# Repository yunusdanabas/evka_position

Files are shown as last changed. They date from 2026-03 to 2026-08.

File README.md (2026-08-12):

# Evka Position: Spherical 3D Positioning Prototype

> Turkce operator guide: [README_TR.md](README_TR.md)

Evka Position is an existing-repository prototype that derives a 3D point from two rotary
encoders and one draw-wire encoder:

```text
encoder counts -> (radius, theta, phi) -> sensor-frame (X, Y, Z) mm
```

Start with [HANDOFF.md](HANDOFF.md), use [docs/ONBOARDING.md](docs/ONBOARDING.md) for the
self-contained setup and safety baseline, and browse [docs/README.md](docs/README.md) for the
documentation status index.

## Handoff Status

| Area | Approved statement |
|---|---|
| Current hardware | The assembled ESP32-S3 v4 carrier is the current prototype. It is not a production-qualified product. |
| Firmware | Shared classic/v4 firmware and all PlatformIO environments build successfully. No new flash or hardware validation is claimed. |
| Telemetry | Live 20 Hz telemetry has been observed in earlier work. Full end-to-end hardware acceptance remains open. |
| Repeatability | Theta count loss is unresolved. The recorded return error reached about 1.1 degrees, approximately 35 mm at 2 m. |
| Coordinates | Firmware and `tools/evka_gui` report the sensor frame. No endpoint/world transform has been accepted. |
| Host application | `tools/evka_gui` is the canonical operator GUI. The vendor C# application has been deleted; the TCP compatibility protocol remains supported. |
| Legal/release | The repository has no redistribution license and makes no public production-readiness claim. |

Do not hide theta slip, backlash, or lost counts by changing PPR or fitting a world transform.
Resolve repeatability first, then calibrate scale, fit a candidate transform, and validate it on
hold-out points.

Known repeatability record:
[docs/calibration/sessions/2026-07-17_repeatability.md](docs/calibration/sessions/2026-07-17_repeatability.md).

### Software Verification Record

| Check | Result |
|---|---|
| `QT_QPA_PLATFORM=offscreen pytest -q -m qt_heavy --forked` | PASS: 44 tests |
| `QT_QPA_PLATFORM=offscreen pytest -q -m "not qt_heavy"` | PASS: 160 tests, 11 subtests (204 total with the above) |
| Dashboard harness (`npm ci && npm test`) | PASS: 50 checks |
| `python -m compileall tools -q` | PASS |
| `python -m tools.ipt.solver` | PASS: 0.405 mm target error |
| PlatformIO build matrix | PASS: all 10 configured environments |

The Python suite runs as **two invocations on purpose**. Modules marked `qt_heavy` build
pyqtgraph widgets that segfault when they share a process, so they run forked; forking only
works if the parent has not built a QApplication first, which is why they get their own
invocation. A plain `pytest -q` is still expected to segfault intermittently — use the two
commands above. Background: [docs/CI_PYTEST_SEGFAULT_LOG.md](docs/CI_PYTEST_SEGFAULT_LOG.md).

These are software-only results. Hardware acceptance remains governed by the open
gates in [docs/integration/final_integration_validation.md](docs/integration/final_integration_validation.md).

## Hardware Baseline

- MCU: ESP32-S3-DevKitC-1 on the v4 carrier; classic Wemos D1 R32 remains a compatibility target.
- Theta/Phi: Autonics E40S6-5000, 20,000 counts/rev at X4 quadrature.
- Radius: OPKON DWEM2 P2000, theoretical 8,000 counts/rev at X4 quadrature.
- Main firmware encoder driver: `madhephaestus/ESP32Encoder` using ESP32 PCNT.
- Encoder outputs are 5 V; the v4 carrier includes the signal dividers required by the ESP32.

### v4 Connector Map

| Connector | Axis | PCB pin order | GPIO |
|---|---|---|---|
| J1 | Draw-wire | `1=A, 2=GND, 3=B, 4=+5V` | A=7, B=8 |
| J2 | Phi | `1=+5V, 2=A, 3=GND, 4=B` | A=4, B=5 |
| J3 | Theta | `1=A, 2=GND, 3=B, 4=+5V` | A=9, B=10 |

Cable colors:

| Encoder | A | B | +5V | GND |
|---|---|---|---|---|
| E40S6 theta/phi | Black | White | Brown | Blue |
| DWEM2 draw-wire | Yellow | Green | Brown | White |

This connector order is derived from the v4 KiCad PCB/pad nets and the current firmware pin map.
It was **not physically reverified during this final documentation pass**. Verify the actual board
and cable before applying power.

Compile-time pins, calibration defaults, battery behavior, LED selection, and network constants
are defined in `firmware/src/SphericalSensor.h`. Runtime PPR values may be overridden by NVS, so
query `CONSTANTS` before a calibration session.

## Canonical Operator GUI

The host-tools package is version `0.2.1` and requires Python 3.10 or newer.

Install the Python dependencies from the repository root:

```bash
python3 -m venv .venv
source .venv/bin/activate
pip install -r requirements.txt
```

Run the canonical GUI:

```bash
python -m tools.evka_gui
python -m tools.evka_gui --serial /dev/ttyACM0 --baud 115200
python -m tools.evka_gui --tcp 192.168.1.50:8080
python -m tools.evka_gui --ws 192.168.1.50
python -m tools.evka_gui --replay frames.csv
```

`evka_gui` supports Serial, TCP, WebSocket, and replay; includes Quick IPT, diagnostics,
recording, snapshots, and the calibration-report workflow; and records raw sensor-frame data.
Software zero is a display/session offset only. The GUI does not apply an endpoint/world transform
to live telemetry, so its XYZ and IPT results remain in the sensor frame.

The standalone `tools/position_checker` entry points are legacy compatibility tools.

## Firmware Build and Flash

PlatformIO is the supported firmware toolchain. Build without uploading:

```bash
pio run -e esp32s3_v4
pio run -e wemos_d1_r32
pio run -e button_remote
```

Flash after wiring and safety review. Replace `/dev/ttyACM0` with the correct port
(`/dev/ttyUSB0` on some boards, `COMx` on Windows). Do not open the same port in two apps at once.

**Main device** (ESP32-S3 v4 carrier — current prototype):

```bash
pio run -e esp32s3_v4 --target upload --upload-port /dev/ttyACM0
pio device monitor -e esp32s3_v4
```

Classic Wemos compatibility target (not for the v4 carrier):

```bash
pio run -e wemos_d1_r32 --target upload --upload-port /dev/ttyUSB0
```

**Remote control** (ESP32-C3 pendant, ESP-NOW):

```bash
pio run -e button_remote --target upload --upload-port /dev/ttyACM0
pio device monitor -e button_remote
```

Bench-only pendant test firmware (own AP `REMOTE_TEST`, no ESP-NOW — see
[`tools/remote_tester/README.md`](tools/remote_tester/README.md)):

```bash
pio run -e button_remote_test --target upload --upload-port /dev/ttyACM0
```

The `test_*` environments use the classic Wemos pin map and must not be flashed onto the v4
carrier. See [CONTRIBUTING.md](CONTRIBUTING.md) and
[pcb_design/EVKA_position_v4/FIRMWARE.md](pcb_design/EVKA_position_v4/FIRMWARE.md) before any
flash or bring-up work.

## Protocol and Networking

The canonical, source-derived transport and command reference is
**[docs/PROTOCOL.md](docs/PROTOCOL.md)**. In summary:

- Serial: 115200 baud; machine-readable `DATA,...` at 20 Hz.
- WebSocket: `ws://<device>/ws`; `DATA,...` at 20 Hz.
- TCP: port 8080; separate `X...,Y...,Z...` and `SENSOR,...` lines at 20 Hz.
- `RAW_COUNTS` returns zero-relative counts, not absolute PCNT values.

The firmware's existing credentials and addresses are unchanged:

| Setting | Current value |
|---|---|
| AP SSID | `CMDCNC_EVKA` |
| AP password | `cmdcnc1234` |
| AP dashboard | `http://192.168.1.50` |
| TCP | `192.168.1.50:8080` |
| WebSocket | `ws://192.168.1.50/ws` |
| STA static profile | `192.168.1.84/24`, gateway `192.168.1.254` |
| STA default network | `WIFI_STA_DEFAULT_SSID` / `_PASS` in [firmware/src/SphericalSensor.h](firmware/src/SphericalSensor.h) — a specific shop-floor network; change before deploying elsewhere |

These fixed credentials and unauthenticated command channels are suitable only for an isolated,
trusted lab network. Do not expose the AP, TCP port, or WebSocket to an untrusted LAN or the public
internet. `WIFI_SET` changes stored STA credentials and reboots the device.

## Calibration Boundary

The active workflow is documented under [docs/calibration/](docs/calibration/). No shared/default
calibration JSON is checked in and no endpoint/world transform is accepted. After the repeatability,
calibration, and hold-out gates pass, a session JSON may be supplied explicitly to the legacy
visualizer with `--legacy-visualizer --calibration <session-calibration.json>`. The canonical
`tools/evka_gui` remains sensor-frame-only.

## Repository Areas

- Active: `firmware/src/`, `tools/evka_gui/`, `docs/PROTOCOL.md`, active calibration and v4 docs.
- Archive/reference: classic test material, integration history, GUI migration logs, and
  `docs/hardware_design/12v_legacy/`.
- Research: `laser_radius/` and `docs/research/`; these are studies, not implemented baseline.
- Unindexed: `report/` holds a standalone LaTeX report that nothing else references. It is kept
  for the record and is not part of the documentation status index.

Prebuilt operator GUI bundles (Windows `.exe` and portable source) are published as assets on the
[v0.2.1 release](https://github.com/yunusdanabas/evka_position/releases/tag/v0.2.1), not in git.
Rebuild them with the scripts in `packaging/evka_gui/`.

## License and Redistribution

There is no repository license file. Default copyright restrictions apply. Do not redistribute,
publish a product release, or represent this prototype as production-ready until ownership and
licensing are explicitly resolved. Historical vendor C# material has been deleted; that cleanup does
not affect the retained TCP wire protocol.

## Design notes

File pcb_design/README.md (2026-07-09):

# pcb_design — KiCad workspaces

Four board revisions live side by side. **Only v4 is fabricated and current** —
the rest are kept for reference.

| Workspace | Status | Notes |
|---|---|---|
| `EVKA_position_v4/` | **CURRENT — fabricated** | ESP32-S3-DevKitC-1 carrier; firmware env `esp32s3_v4` (`-DPCB_V4`). Pin map, bring-up, battery, LED: [`EVKA_position_v4/FIRMWARE.md`](EVKA_position_v4/FIRMWARE.md) |
| `EvkaPosition_v2/` | Superseded | Full-featured 5V design (74HC14 buffers, load-sharing). ERC-clean but never fabricated. Its design docs were removed on migration to v4 — recover from git history if needed |
| `EVKA_position_v3/` | Superseded | Stripped "simple" variant of v2 (direct-GPIO dividers, no buffers). Never fabricated |
| `EVKA_position_v5/` | Experimental / WIP | Layout exploration after v4; not fabricated, no firmware support |

Netlists are generated files — regenerate with
`kicad-cli sch export netlist <project>.kicad_sch` (a stray root-level
`EvkaPosition_v2.net` is git-ignored for this reason). KiCad backup folders
(`*-backups/`) are git-ignored too.

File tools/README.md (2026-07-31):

# Host Tools

The supported operator path is `tools/evka_gui`. Host tools are package version `0.2.1` and require
Python 3.10+. All current GUI telemetry, recordings, snapshots, and Quick IPT results are sensor-frame
values. No endpoint/world transform is accepted or applied by the canonical GUI.

## evka_gui: Canonical Operator GUI

```bash
python -m tools.evka_gui
python -m tools.evka_gui --serial /dev/ttyACM0 --baud 115200
python -m tools.evka_gui --tcp 192.168.1.50:8080
python -m tools.evka_gui --ws 192.168.1.50
python -m tools.evka_gui --replay frames.csv
```

It provides Serial/TCP/WebSocket/replay connections, 3D and 2D views, recording, snapshots,
saved-point events, diagnostics, zero-relative raw counts, Quick IPT, and calibration-session tools.

Coordinate rules:

- Software Zero is a display/session offset only.
- Hardware Zero sends a firmware `ZERO*` command.
- Recordings and calibration capture use raw sensor-frame telemetry, not software-zeroed display
  values.
- The calibration window can generate a candidate session JSON after report PASS, but that does not
  establish project acceptance or change the live GUI frame.

Full guide: [evka_gui/README.md](evka_gui/README.md).

## calibration

Candidate Kabsch sensor-to-world fitting with separate calibration and hold-out sets:

```bash
python -m tools.calibration.gui
python -m tools.calibration.report
```

Theta repeatability must pass before collecting endpoint pairs. No shared/default calibration JSON
is checked in or accepted.

Operator workflow: [../docs/calibration/report_workflow.md](../docs/calibration/report_workflow.md).
Tool details: [calibration/README.md](calibration/README.md).

## Quick IPT

Quick IPT is inline in `evka_gui`. A standalone UI remains available:

```bash
python -m tools.ipt --tcp 192.168.1.50:8080
python -m tools.ipt --serial /dev/ttyACM0 --baud 115200
python -m tools.ipt.solver
```

The recovered point is in the sensor frame. See [ipt/README.md](ipt/README.md).

## Remote Tester

Development-only direct TCP/serial tester for `button_remote_test` firmware:

```bash
python tools/remote_tester/remote_test_gui.py
```

It is also available from the canonical GUI's **Remote Tester...** action, using a separate test
connection. See [remote_tester/README.md](remote_tester/README.md).

## Legacy position_checker

`tools/position_checker` retains shared parsing/transport/view code and legacy standalone entry
points. New operator instructions should use `tools/evka_gui`.

A passing session JSON may be supplied explicitly only to the legacy visualizer:

```bash
python -m tools.position_checker.main --legacy-visualizer --port /dev/ttyUSB0 \
  --calibration docs/calibration/sessions/current/calibration.json
```

| Legacy command | Canonical replacement |
|---|---|
| `python -m tools.position_checker.main --legacy-visualizer --port ...` | `python -m tools.evka_gui --serial ...` |
| `python -m tools.position_checker.cmd_main` | `python -m tools.evka_gui --tcp ...` |

Historical migration documents may mention older GUI package names as archive history.

## Protocol and Security

[../docs/PROTOCOL.md](../docs/PROTOCOL.md) is the canonical protocol reference. Do not treat
`cmd_main.py`, a GUI parser, or a historical vendor application as the wire-contract source.

Current fixed credentials and unauthenticated state-changing commands are trusted-lab-only. Do not
expose the device's TCP/WebSocket services to an untrusted network.

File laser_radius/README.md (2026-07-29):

# Laser Radius Research — Spherical Positioning Variant

**Location:** `laser_radius/` at repo root — all detailed research deliverables live here.

**Scope:** Detailed research for an EVKA positioning variant that replaces the draw-wire radius encoder with a laser distance measurement, while keeping two rotary encoders for azimuth (θ) and elevation (φ).  
**Status:** Detailed study, revised to a fixed requirement (2026-07-01) — device shortlists, kinematics/calibration, firmware sketch, procurement plan, and a LaTeX summary report are documented below and in the linked files. Physical bench testing has not started.  
**Current prototype baseline:** ESP32-S3 v4 carrier + 2× E40S6 rotary encoders + OPKON DWEM2 draw-wire.
**Target platform (this variant):** ESP32-S3-DevKitC-1 on EVKA_position_v2 carrier direction.

---

## Executive Summary

**Fixed requirement:** laser range ≤ 40 m, laser device accuracy ≤ 10 mm (target sub-cm) across that full range. This is the laser sensor's own datasheet spec, not the total combined-system XYZ accuracy — see [`kinematics_and_calibration.md`](kinematics_and_calibration.md) §4 for why the rotary encoders separately add error that this spec doesn't cover.

**This single number is a real physics dividing line, and it reshaped the shortlist from an earlier draft of this study:** cheap pulsed time-of-flight LIDAR modules (the entire Benewake TF-series, DFRobot SEN0492) measure round-trip pulse timing directly and only achieve ±5cm–±1%-of-reading accuracy — they **fail this spec** and are excluded as recommendations (kept only as documented "does not meet spec" reference entries in `version_b_integrated_modules.md` §1). Phase-shift (AMCW) laser distance meters — the Leica handheld class, and industrial OEM modules like Meskernel and Dimetix — measure phase difference of a modulated beam and achieve flat, distance-independent mm-class accuracy across their full rated range. Every **certified** device below is confirmed phase-shift; two popular families (**Bosch** handhelds and the **JRT** OEM modules) are **flagged** rather than certified — the stricter 2026-07-08 survey could not confirm their measurement principle is phase-shift from any primary source, so they are held out of the recommended pass list until that is verified (they are *not* excluded — they are not ToF or %-of-reading; see `version_a_handheld_devices.md` §2.3).

**Recommendation (confirmed-phase-shift-first, revised 2026-07-09):** lead the bench path with a device whose phase-shift principle *and* price are both confirmed. Cheapest such path is the **Meskernel LDL-T** — both 2026-07-08 surveys confirm it as phase-shift; ±1 mm, 100 Hz, UART TTL/RS232/RS485; confirmed street price ~$87.50 (~4,097 TRY) for the 80 m LDL-T-80, ~$68–80 for the 40 m LDL-T 40. For the lowest *integration* risk, the **Dimetix D-series** is the only candidate with a fully public ASCII command set — the newly-confirmed **DBN-50-050** (±5 mm, still under the ≤10 mm bar) at CHF 1,076 / ~$1,332 is the budget entry, the **DAE-10-050** (±1 mm) at ~$2,700 the precise one. For a confirmed, domestically-stocked handheld, the **Leica DISTO D5** (±1 mm, 200 m, BLE) is now confirmed available in Turkey. **Bosch PLR 40 C: Bluetooth type now confirmed (BLE 4.2 GATT, 2026-07-09)** — ESP32-S3 compatible, protocol decrypted from GLM family (CRC-8, IEEE 754 float parsing), but byte-level traces are from GLM 50C/120C — **one real-device capture session on PLR 40 C still required** before firmware work. Measurement principle (phase-shift vs other) still unconfirmed. **Do not use PLR 40 C for production** — BLE latency jitter, no USB/wired fallback, 5-minute auto-power-off, and power supply fragility make it unsuitable for continuous automated tracking. Use wired industrial sensors (Meskernel/Dimetix) instead. **Flagged — do not certify yet:** the **Bosch GLM 50-27 CG** and **JRT B605B / M88B** are attractive on price and (for Bosch) domestic availability, but the stricter survey could not confirm their measurement principle from any primary source — treat them as promising-but-unverified and confirm the principle before committing. Reach for an industrial module (Micro-Epsilon ILR2250/3800, WayCon LDI, FAE LS 121/122 FA) only if IP-rated/certified housing becomes a hard requirement — a large cost premium for accuracy margin the Meskernel/Dimetix path already clears. Full reasoning: [`version_a_handheld_devices.md`](version_a_handheld_devices.md), [`version_b_integrated_modules.md`](version_b_integrated_modules.md), and the bench-test order in [`procurement_and_bom.md`](procurement_and_bom.md).

**2026-07-01 addendum — extended shortlist:** a second research pass (assisted by a Copilot CLI research agent) more than tripled the candidate count — 8 more handheld/BLE devices (Hilti PD-I, Leica DISTO D2/S910, Bosch GLM 50-27CG/165-27CG, Stanley TLM165i, RS PRO/CEM iLDM-150H, ADA Cosmo 60 Green) and 5 more industrial fixed-mount devices (Micro-Epsilon optoNCDT ILR1181-3/ILR2250/ILR3800, Jenoptik LDM4x, WayCon LDI, Scantron SLS), all confirmed phase-shift and meeting the ≤10mm/≤40m spec. Two standouts worth knowing about even in this summary: **RS PRO ILDM-150H** (~$90–130) is the cheapest BLE handheld found, potentially unseating Bosch on price with comparable local availability via RS Components' Turkey branch; **Leica DISTO S910** (~$900–1,200) is the single best-specified handheld (±1.0 mm, 300 m range, *native* wired USB — no accessory cable needed), priced near the industrial tier. The research also produced a documented "don't re-check these" list of 15+ rejected devices/manufacturers (wrong tech, wrong range, or no data interface) — see §3.1/§3.2 in the two device files.

**2026-07-08 addendum — confirmed pricing & SKU survey:** a targeted Istanbul price/model survey (two independent passes) replaced most of the earlier *estimates* with **CONFIRMED** prices and exact SKUs, and it changed two recommendations:
- **Confirmed prices/SKUs:** Dimetix **DAE-10-050** (P/N 500633, ±1 mm, ~$2,700) and **DBN-50-050** (P/N 500635, ±5 mm, ~$1,332 — cheapest qualifying Dimetix); Leica **DISTO D5** (confirmed in TR), **S910** (~$1,916–2,132 — **corrected up** from the earlier ~$900–1,200 estimate), and D2 (current refresh SKU 986858 = 150 m); Bosch **GLM 50-27 CG** (8,200 TRY / ~$175); Meskernel **LDL-T-80** (~$87.50, and its rate corrected **30 → 100 Hz**).
- **New models added:** Leica **DISTO X6** (250 m, ±1 mm — the practical rugged X4 successor alongside the D5), Dimetix **DBN-50-050**, Meskernel **LDK-40**, JRT **M88B**, and **FAE LS 121/122 FA** (50 m, ±3 mm industrial). New price *anchors* (still ESTIMATE) for the previously quote-only Micro-Epsilon **ILR2250** (~$1,800) and Jenoptik **LDM41** (~$1,500).
- **Corrections:** Bosch and JRT **demoted to a flagged (uncertified) tier** — see the physics note above. Micro-Epsilon's older **ILR1171/1181/1191** family is **pulsed ToF** (rejected); ILR2250/ILR3800 remain the confirmed phase-comparison picks. Jenoptik LDM4x's 150 m headline is reflector-dependent (~30 m on natural surfaces) — flagged.
- **New figures:** `report/figures/price_vs_accuracy.png` (same ±1 mm accuracy spans ~$43→$2,772) and `turkey_availability.png` (lead-time by sourcing class), generated by `report/figures/make_figures.py`. FX used: USD/TRY 46.85, CHF/USD 1.238, EUR/USD 1.141, GBP/USD 1.336 (2026-07-08).

**A brief LaTeX report summarizing this whole study is in [`report/`](report/report.pdf).**

**A key finding that affects both versions:** the RS-485 GPIO plan cited below (§1.4) comes from the older `12v_legacy/v2` pin map. The current as-built 5V v2 board wires those same pins differently (no dedicated RS-485/RS422 header exists yet) — see [`version_b_integrated_modules.md`](version_b_integrated_modules.md) §4 for the corrected wiring and the new-hardware implications.

---

## 1. Overview and Concept

### 1.1 Relation to Current System

The existing system computes 3D position from spherical coordinates `(r, θ, φ)` and converts to Cartesian `(X, Y, Z)` using the same elevation-azimuth convention documented in [`docs/hardware_design/system_architecture.md`](../docs/hardware_design/system_architecture.md) and implemented in `firmware/src/SphericalSensor.cpp`.

In this variant, **only the radius source changes**: instead of quadrature counts from a draw-wire drum, `r` comes from a laser distance measurement on the phi (elevation) head. The two rotary encoders remain unchanged in role.

### 1.2 Kinematic Chain

Current draw-wire chain:

`Base → Theta → Arm → Phi → Draw-Wire → Target`

Proposed laser chain:

`Base → Theta → Arm → Phi → Laser (on phi head) → Target`

The laser is mounted on the phi head and points at the target along the boom, replacing the draw-wire cable path.

```mermaid
graph TD
    Base[FixedBase] -->|Z_axis| ThetaMotor[Motor1_Theta]
    ThetaMotor --> Arm[HorizontalArm]
    Arm -->|X_axis| PhiMotor[Motor2_Phi]
    PhiMotor --> LaserHead[LaserOnPhiHead]
    LaserHead -->|"r via laser"| Target[TargetObject]
    Target --> XYZ["X Y Z computed"]
```

### 1.3 Why Laser Instead of Draw-Wire

| Factor | Draw-wire (current) | Laser (proposed) |
|---|---|---|
| Mechanical coupling | Cable sag, wrap, drum wear | Line-of-sight only |
| Calibration | `CAL_W`, drum circumference, PPR | Device offset, reflectivity |
| BOM / wiring | 3rd quadrature encoder (2 lines) | Serial or RS232/RS422/RS485 interface |
| Dual use | Fixed to machine | Version A: detachable handheld possible |
| Accuracy at 40 m | Good linear step (~0.025 mm/count), but ≤3 m practical reach | ±1–2.6 mm class (phase-shift devices) at full 40 m range |

### 1.4 ESP32-S3 Pin Baseline

Align with V2 pin assignment ([`pin_assignment_v2.md`](../docs/hardware_design/12v_legacy/v2/pin_assignment_v2.md)):

| Function | GPIO | Notes |
|---|---|---|
| Theta A/B | 4, 5 | Unchanged |
| Phi A/B | 6, 7 | Unchanged |
| Wire A/B/Z | 15, 16, 17 | **Freed** — no draw-wire in this variant |
| RS-485/RS422 TX/RX/DE | 13, 14, 18 | Version B fixed laser; optional for Version A wired serial. **Superseded** — the current as-built 5V v2 board wires 13/14 as general AUX pins and 18 as BTN2; see [`version_b_integrated_modules.md`](version_b_integrated_modules.md) §4 for the corrected 13/14/15 wiring. |
| Battery ADC | 1 | Optional, if carrier retains 12V monitor |

### 1.5 Accuracy Baseline (Current vs. Fixed Requirement)

Current draw-wire system (from system architecture, at ~5 m, ≤3 m practical reach):

| Axis | Source | Typical error contribution |
|---|---|---|
| θ, φ | E40S6 @ 20000 PPR | ~1.57 mm arc at 5 m (grows linearly with range — ~12.6 mm at 40 m) |
| r | Draw-wire | ±0.025 mm per count step |
| Combined XYZ | — | ~±3.2 mm worst case at 5 m |

**Laser variant fixed requirement:** ≤ 40 m range, ≤ 10 mm laser device accuracy (device spec, confirmed as the target — see Executive Summary). Every shortlisted device meets this with 4–10× margin (§2/§3 below and the linked files) — the harder number to watch is the *combined* system accuracy at long range, which the encoders alone push to ~18 mm at 40 m regardless of laser choice (see `kinematics_and_calibration.md` §4); that's out of scope for this laser-selection study per the user's decision but worth keeping in mind.

### 1.6 Related Work in This Repo

[`docs/research/improvement_research.md`](../docs/research/improvement_research.md) mentions a VL53L1X ToF sensor for cross-validation against the draw-wire — that is a short-range sanity check, not a full radius replacement. This folder covers a dedicated laser-radius architecture with two sub-versions below.

---

## 2. Version A — Detachable Handheld / Wired-Serial Laser

Mounted on the phi head during operation, quick-disconnect so the same tool can be used standalone in the field. **Full shortlist, per-device specs, protocol notes, and pricing: [`version_a_handheld_devices.md`](version_a_handheld_devices.md).**

Top candidates against the ≤40m/≤10mm spec: **Meskernel LDL-T** (confirmed phase-shift, ±1mm to 80m, RS232/RS485/USART, native **100 Hz**, ~$68–87.50), **Leica DISTO D5/S910** (±1mm to 200–300m, BLE + native USB on S910, confirmed TR pricing), and — *flagged, phase-shift unconfirmed by the stricter survey* — **JRT B605B/M88B** (≈±2.6mm @ 40m, RS232 TTL, cheapest wired option) and **Bosch PLR 40 C** (±2mm flat to 40m, BLE-only, best local availability). Extended research added Hilti PD-I, Leica DISTO D2/X6/S910, Bosch GLM 50-27CG/165-27CG, Stanley TLM165i, RS PRO/CEM iLDM-150H, ADA Cosmo 60 Green — 13 qualifying/flagged devices total. **UNI-T LM50A (and Makita LD050P, found in the addendum) remain unsuitable** regardless of the spec change — neither has any automated data interface at all (no Bluetooth/USB/RS232), which is an integration problem, not an accuracy one.

---

## 3. Version B — Built-In Fixed Laser Module

Permanently mounted on the phi head — no operator handling. **Full shortlist, wiring, and the as-built GPIO correction: [`version_b_integrated_modules.md`](version_b_integrated_modules.md).**

The previously-considered primary pick (Benewake TF02-i-RS485, and its TF03/TFmini/SEN0492 alternatives) **fails the ≤10mm spec** — pulsed-ToF modules land at ±5cm–±1% of reading, 5–40× over budget — and is now excluded, kept only as a documented reference for why. The primary path is a **Dimetix D-series** industrial phase-shift sensor — now pinned to confirmed SKUs: **DAE-10-050** (±1mm, ~$2,700) or the cheaper **DBN-50-050** (±5mm, still ≤10mm, ~$1,332), both with a fully public ASCII command set (lowest integration risk of any candidate). Far cheaper: panel-mount the **Meskernel LDL-T** bare module (confirmed phase-shift, ±1mm, 100 Hz) as a fixed installation instead of a handheld dock — the **JRT B605B** works the same way but is flagged (phase-shift unconfirmed). Extended research added industrial-tier alternatives to Dimetix (Micro-Epsilon optoNCDT ILR2250/ILR3800 ~$1,800, Jenoptik LDM41 ~$1,500, FAE LS 121/122 FA ~$1,400, WayCon LDI quote-only, Scantron SLS — all ±1-3mm class) plus a sweep of 13 manufacturers (SICK, Banner, Wenglor, Balluff, Contrinex, Riftek, and others) that turned out to sell the wrong technology (pulsed ToF or short-range triangulation) — documented as a "don't re-research" list. Note: Micro-Epsilon's older ILR1171/1181/1191 line is pulsed ToF (2026-07-08 correction) and now rejected — use the phase-comparison ILR2250/ILR3800 instead.

---

## 4. Open Questions

1. ~~Range and accuracy requirements~~ — **resolved**: ≤40 m, ≤10 mm laser device accuracy (2026-07-01).
2. **Spherical origin offset** — distance from laser aperture to mechanical pivot; correction term in `r` before `sphericalToCartesian()`. See `kinematics_and_calibration.md` §1.
3. **Target reflectivity** — dark, glossy, or angled surfaces; need for retroreflector plate or laser filter window on phi head. See `kinematics_and_calibration.md` §2.
4. **Exact pricing for most candidates** (JRT B605B, Meskernel LDL-T, Leica's current D-line, and all 4 addendum industrial modules) — unconfirmed, need direct quotes. See `procurement_and_bom.md` Open Risks.
5. **Update rate** — resolved for the recommended devices (JRT ~8Hz needs hold-last-value gap-filling; Meskernel/Bosch/Dimetix don't). See `firmware_integration.md` §2.
6. **Firmware architecture** — new `LaserRadiusSensor` class vs extending `SphericalSensor.h`; removal of wire encoder and `CAL_W` / `PPR_WIRE` paths. Sketch in `firmware_integration.md` §4.
7. **Calibration workflow** — replace draw-wire `CAL_W` with laser zero offset and optional scale check. Proposed in `kinematics_and_calibration.md` §3.
8. **Safety and enclosure** — Class 1 vs Class 2 exposure; interlocks if operator can remove dock (Version A).
9. **CMD / WiFi dashboard** — expose radius source type in `STATUS` / WebSocket JSON; update calibration UI tab.
10. **Dimetix's exact current-catalog SKU** for a confirmed 40 m RS232/RS422 unit — see `version_b_integrated_modules.md` Open Risk #1.

---

## 5. Next Steps

1. Order a **Meskernel LDL-T** (confirmed phase-shift, cheapest such option) and a **Dimetix DBN-50-050** (confirmed public ASCII protocol, lowest integration risk) as the two confirmed-phase-shift leads — see `procurement_and_bom.md` §2 for the full bench-test order.
2. Bench-test the confirmed lead at 5 m / 20 m / 40 m against a known reference to confirm its datasheet accuracy holds in practice.
3. Measure spherical origin offset (`d_offset_mm`) on a physical phi-head mock-up.
4. Draft the `LaserRadiusSensor` firmware class and prototype the non-blocking poll pattern from `firmware_integration.md` §2 on a bare ESP32-S3 dev board.
5. Only pursue the **flagged** Bosch/JRT modules after confirming their phase-shift principle from a primary source; escalate to the industrial tier (Micro-Epsilon, WayCon, FAE) only if IP-rated housing becomes a hard requirement.

---

## Folder Index (detailed research)

| File | Status |
|---|---|
| `README.md` | Executive summary + brief overview (this file) |
| `RESEARCH_PROMPT.md` | Prompt used for the original deep-dive research pass |
| [`bosch_plr_40c_integration.md`](bosch_plr_40c_integration.md) | **Updated 2026-07-09** — Bluetooth type **confirmed** (BLE 4.2 GATT). Protocol decrypted from GLM family (CRC-8, IEEE 754 float, BLE UUIDs). ESP32-S3 NimBLE code sketches. **Not yet verified on physical PLR 40 C** — one capture session required. Recommendation: do not use for production (use wired Meskernel/Dimetix instead). |
| [`version_a_handheld_devices.md`](version_a_handheld_devices.md) | Done — 12 wired/BLE candidates vs. the ≤40m/≤10mm spec (4 original + 8 from the 2026-07-01 addendum); why UNI-T LM50A / Makita LD050P are excluded |
| [`version_b_integrated_modules.md`](version_b_integrated_modules.md) | Done — Dimetix D-series + 4 more industrial-tier options + JRT/Meskernel budget path; TF02-i-class and 13 rejected manufacturers documented with physics reasoning |
| [`kinematics_and_calibration.md`](kinematics_and_calibration.md) | Done — offset geometry, `CAL_W`-replacement workflow, combined error-budget table |
| [`firmware_integration.md`](firmware_integration.md) | Done — interface options, 20 Hz feasibility, BLE+WiFi coexistence, `LaserRadiusSensor` sketch; §2 updated 2026-07-09 with confirmed BLE details, UUIDs, CRC-8 code, IEEE 754 parsing |
| [`procurement_and_bom.md`](procurement_and_bom.md) | Done — pricing/supplier table, recommended bench-test order |
| [`report/report.pdf`](report/report.pdf) | Done — brief LaTeX report summarizing this whole study |

---

*Document created: 2026-07-01. Revised same day to a fixed ≤40m/≤10mm requirement (dropping the earlier proposed tier framework). Detailed study — not a build specification; no firmware or PCB files were changed. Physical bench testing is the next phase (see each file's "Next Physical Test Steps").*

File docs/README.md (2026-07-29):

# Documentation Status Index

This index separates the active v4 prototype handoff from historical material and research. A file
in the repository is not automatically a current requirement.

## Active Prototype Handoff

| Document | Role |
|---|---|
| [../AGENTS.md](../AGENTS.md) | Shared agent guide: working rules, safety boundaries, validation commands |
| [../AGENT_LOG.md](../AGENT_LOG.md) | Historical multi-agent activity log |
| [../HANDOFF.md](../HANDOFF.md) | Approved existing-repository status, blockers, and reading order |
| [ONBOARDING.md](ONBOARDING.md) | Self-contained workstation, safety, and first-session baseline |
| [../CONTRIBUTING.md](../CONTRIBUTING.md) | Supported toolchain and contribution boundaries |
| [../README.md](../README.md) | Short project and operator overview |
| [ARCHITECTURE.md](ARCHITECTURE.md) | Runtime design, coordinate frames, pins, LED, and battery behavior |
| [PROTOCOL.md](PROTOCOL.md) | **Canonical source-derived telemetry and command/reply contract** |
| [PROJECT_ROADMAP.md](PROJECT_ROADMAP.md) | Remaining prototype gates in approved order |
| [firmware/CODE_WALKTHROUGH.md](firmware/CODE_WALKTHROUGH.md) | Guided map of current firmware source |
| [../pcb_design/EVKA_position_v4/FIRMWARE.md](../pcb_design/EVKA_position_v4/FIRMWARE.md) | v4 PCB-derived pin map and firmware quickstart |
| [../README_TR.md](../README_TR.md) | Turkish operator guide |

## Active Calibration

Theta count loss is unresolved and there is no accepted endpoint/world transform. Treat generated
transforms as candidates until the required repeatability, calibration, and hold-out gates pass.

| Document | Role |
|---|---|
| [calibration/README.md](calibration/README.md) | Calibration order and current stop conditions |
| [calibration/calibration_guide.md](calibration/calibration_guide.md) | Encoder-scale and candidate endpoint workflow |
| [calibration/report_workflow.md](calibration/report_workflow.md) | CSV/report workflow and acceptance thresholds |
| [calibration/sessions/README.md](calibration/sessions/README.md) | Session inputs, candidate outputs, and archiving |
| [calibration/sessions/2026-07-17_repeatability.md](calibration/sessions/2026-07-17_repeatability.md) | Current theta count-loss evidence |
| [calibration/draw_wire_calibration.md](calibration/draw_wire_calibration.md) | Draw-wire scale procedure |
| [calibration/theta_rotary_calibration.md](calibration/theta_rotary_calibration.md) | Theta procedure and repeatability gate |
| [calibration/phi_rotary_calibration.md](calibration/phi_rotary_calibration.md) | Phi procedure and J2 mapping |

## Active Integration and Operations

| Document | Role |
|---|---|
| [integration/CMD_SOFTWARE_INTEGRATION.md](integration/CMD_SOFTWARE_INTEGRATION.md) | Retained TCP compatibility integration; vendor C# app has been deleted |
| [integration/final_integration_validation.md](integration/final_integration_validation.md) | Pending prototype acceptance checklist |
| [integration/setup_test_guide.md](integration/setup_test_guide.md) | Classic-board bench reference plus v4 routing notice |
| [WIFI_PERFORMANCE_ISSUES_LOG.md](WIFI_PERFORMANCE_ISSUES_LOG.md) | Historical WiFi fixes and open validation notes |
| [WIFI_AP_STA_RECONNECT_PATTERNS.md](WIFI_AP_STA_RECONNECT_PATTERNS.md) | AP/STA implementation reference |
| [ASYNCTCP_STACK_OVERFLOW_ANALYSIS.md](ASYNCTCP_STACK_OVERFLOW_ANALYSIS.md) | AsyncTCP implementation risk reference |
| [ESPASYNCHACK_NOTES.md](ESPASYNCHACK_NOTES.md) | Installed ESPAsyncWebServer behavior notes |

## Hardware Reference

| Document | Status |
|---|---|
| [../pcb_design/README.md](../pcb_design/README.md) | PCB workspace index; v4 is the current assembled prototype |
| [hardware_design/encoders/](hardware_design/encoders/) | Active encoder references |
| [hardware_design/remote/](hardware_design/remote/) | ESP-NOW pendant reference |
| [hardware_design/assembly/](hardware_design/assembly/) | Bench/assembly reference; verify revision before use |
| [hardware_design/5v/](hardware_design/5v/) | Older classic-board design reference |
| [hardware_design/12v_legacy/](hardware_design/12v_legacy/) | **Archive:** superseded 12 V/v2/v3 designs, not the v4 baseline |

## Host Tools

| Document | Status |
|---|---|
| [../tools/evka_gui/README.md](../tools/evka_gui/README.md) | **Active canonical GUI**, sensor-frame-only |
| [../tools/calibration/README.md](../tools/calibration/README.md) | Active candidate transform/report tooling |
| [../tools/ipt/README.md](../tools/ipt/README.md) | Active Quick IPT tooling; result remains sensor-frame |
| [../tools/remote_tester/README.md](../tools/remote_tester/README.md) | Development-only pendant tester |
| [../tools/position_checker/README.md](../tools/position_checker/README.md) | Legacy standalone tools plus shared libraries |

## Archive and History

These explain how the current repository evolved; they are not current acceptance statements:

- [integration/CMD_INTEGRATION_CHANGELOG.md](integration/CMD_INTEGRATION_CHANGELOG.md)
- [firmware/firmware_rework_log.md](firmware/firmware_rework_log.md)
- [gui_unification/](gui_unification/)
- [superpowers/specs/](superpowers/specs/)

Historical mentions of `tools/evka_gui_v2` or the deleted vendor C# application remain historical
only; referenced vendor paths no longer exist in the worktree.
The supported GUI is `tools/evka_gui`; the retained protocol is [PROTOCOL.md](PROTOCOL.md).

## Research

Research documents describe alternatives, not implemented or accepted hardware:

- [research/](research/)
- [../laser_radius/](../laser_radius/)
- [BLE_WIFI_COEXISTENCE.md](BLE_WIFI_COEXISTENCE.md)
- [resources.md](resources.md)

## Legal and Security Boundary

The repository has no redistribution license and makes no public production-readiness claim. The
current fixed credentials and unauthenticated TCP/WebSocket commands are trusted-lab-only. See
[PROTOCOL.md](PROTOCOL.md#security-boundary).

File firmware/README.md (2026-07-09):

# Evka Position Firmware

ESP32 firmware for the Spherical 3D Positioning System.

## Project Structure

*   `src/`: Production firmware (PlatformIO build target `wemos_d1_r32`).
    *   `EvkaPosition.cpp`: Entry point (`setup()` / `loop()`).
    *   `SphericalSensor.h`: Configuration defines, structs, class declaration.
    *   `SphericalSensor.cpp`: Coordinate math, filtering, validation.
    *   `WebDashboard.h` / `WebDashboard.cpp`: WiFi AP, HTTP dashboard, WebSocket server.
    *   `CmdTcpServer.h` / `CmdTcpServer.cpp`: Raw TCP server on port 8080 (CMD protocol).
*   `tests/`: Standalone test sketches, each compiled independently.
    *   `DrawWireTest/`: Standalone test for the OPKON DWEM2 draw-wire encoder.
    *   `RotaryEncoderTest/`: Standalone test for the Autonics E40S6 rotary encoder (theta + phi).
    *   `SingleRotaryTest/`: Single rotary encoder test (theta or phi independently).
    *   `AllSensorsTest/`: All three encoders together, without position math.

## Dependencies

*   **Encoder** by Paul Stoffregen (v1.4.4+) — automatically installed by PlatformIO via `platformio.ini`.

## Build & Flash

Supported workflow policy: use PlatformIO on ESP32 only. Arduino IDE and `arduino-cli` are not part of this firmware workflow.

See [`docs/integration/setup_test_guide.md`](../docs/integration/setup_test_guide.md) for full toolchain setup and step-by-step instructions.

For the WiFi/TCP/WebSocket user guide (Turkish): [`README_TR.md`](../README_TR.md)

Quick compile check:
```bash
pio run -e wemos_d1_r32
```

## Configuration

Edit `src/SphericalSensor.h` to change pin assignments, encoder resolution, or safety limits. See [`docs/ARCHITECTURE.md`](../docs/ARCHITECTURE.md) for a summary of all constants.

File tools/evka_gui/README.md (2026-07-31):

# evka_gui — EVKA Unified Control GUI (canonical)

Single-window control panel + 3D view for v4 board bring-up and daily operation.
Opens maximized with a 50/50 control/plot splitter by default.

This is the canonical operator GUI for the current prototype. It is **sensor-frame-only**: live XYZ,
recordings, snapshots, saved points, and Quick IPT results do not receive an endpoint/world
transform. Software zero is a display/session offset.

**Transports:** Serial, WiFi/TCP (port 8080), WebSocket (port 80 `/ws`), CSV replay.
A dropped link **reconnects on its own** (exponential backoff, 1 s → 30 s); the
Disconnect button becomes **Cancel** while a retry is pending.

**Main panel:** live position and connection controls stay visible; IPT, Points,
Diagnostics, and Commands live in tabs. The compact protocol log is in the left
column, not a bottom dock.

**Toolbar:** Record, Freeze, Calibration…, WiFi Settings…, IPT plots…, Remote Tester…
(ButtonRemoteTest dev firmware), Capture/Clear/Export Snapshots, Export Saved Points CSV,
Open Dashboard, Export Session CSV.

**Record** writes the live stream as raw firmware `DATA,` lines — the format
`--replay` already reads, so a recording plays straight back. It works on every
transport (TCP sends `X,Y,Z` + `SENSOR,` instead of `DATA,`, and is re-serialised), and
it always stores **raw sensor-frame** values, never software-zeroed ones. The firmware
web dashboard records the same format, so you can record on a phone in the field and
replay it here.

**Freeze** pauses the *view* — the link stays up, command replies still land, and a
recording in progress keeps writing. Arming IPT clears it automatically, since capture
would otherwise collect nothing.

**Views:** software 3D trail + XY/XZ/YZ plots with layer toggles (trail / IPT / origin /
saved points), adjustable trail length, IPT overlays on 2D and 3D views. The 3D view
rotates on left-drag and zooms on the mouse wheel.

**Look and feel:** colours and button names come from
`docs/gui_unification/DESIGN_TOKENS.md` (mirrored in `tokens.py`), shared with the
firmware web dashboard so the two read as one product.

**Replay:** pause, speed, step, slider seek (rebuilds session state from frame 0).

**Profiles:** save/load/delete named connection presets (mode, host, port, replay path).

```bash
python -m tools.evka_gui                              # open disconnected
python -m tools.evka_gui --serial /dev/ttyUSB0 --baud 115200
python -m tools.evka_gui --tcp 192.168.1.50:8080      # AP direct
python -m tools.evka_gui --tcp 192.168.1.84:8080      # STA
python -m tools.evka_gui --ws 192.168.1.50            # WebSocket dashboard stream
python -m tools.evka_gui --replay frames.csv
```

**Quick IPT:** inline **Quick IPT** group — ARM, sweep, STOP, SOLVE, Copy P, export capture
CSV, add P to snapshots. Optional **IPT plots…** pop-out. Standalone: `python -m tools.ipt`.

**Calibration window:** wire/theta/phi PPR trials, plus an **Endpoint** tab that runs the
whole endpoint session — collect world/sensor pairs, assign each to the calibration or
validation set, **Generate report**, and read PASS/FAIL and per-point residuals.

The currently named **Deploy calibration.json** button is historical legacy behavior, not canonical
GUI deployment. No shared/default calibration JSON is checked in or auto-loaded. A passing session
JSON may be supplied explicitly only to the legacy visualizer; this GUI remains sensor-frame-only.
Resolve theta count loss before endpoint capture.

Points are read from and written to `docs/calibration/sessions/current/`
(`calibration_points.csv` / `validation_points.csv`) directly — those files are the session
state, so the tab and `python -m tools.calibration.report` always agree. **Import CSV** pulls
in an export from the web dashboard **CALIBRATE → ENDPOINT** tab. The report itself is
generated by `tools/calibration/report.py`; the GUI never fits the transform itself. See
[`docs/calibration/report_workflow.md`](../../docs/calibration/report_workflow.md).

Captured sensor XYZ is always **raw sensor-frame**, never software-zeroed — same rule as
Record, and required for a valid fit.

**Protocol log:** compact left-column panel — filter DATA / ACK / ERR / Other.

Modules: `gui.py`, `model.py`, `transport.py`, `ws_client.py`, `protocol_log.py`,
`session_utils.py`, `replay_utils.py`, `calibration.py`, `ipt_panel.py`, `ipt_window.py`,
`wifi_window.py`, `remote_window.py`. Tests: `tests/`.

## Windows packaging

To ship this GUI to users who have no Python installed, see
[`packaging/evka_gui/WINDOWS.md`](../../packaging/evka_gui/WINDOWS.md) — a PyInstaller
one-folder build producing `EvkaGUI.exe`, with verification and troubleshooting steps. Build it
**on Windows** from the repo root (PyInstaller cannot cross-compile):

```powershell
powershell -ExecutionPolicy Bypass -File packaging\evka_gui\build_windows.ps1
```

Frozen builds have no repo root, so calibration sessions and `calibration.json` go to
`%LOCALAPPDATA%\evka_position\` instead — see `_project_root()` in
[`tools/calibration/report.py`](../calibration/report.py).

Feature matrix and design history: [`tools/README.md`](../README.md) and
[`docs/gui_unification/`](../../docs/gui_unification/).

Runtime protocol: [`docs/PROTOCOL.md`](../../docs/PROTOCOL.md). Fixed credentials and unauthenticated
commands are for isolated trusted-lab use only.

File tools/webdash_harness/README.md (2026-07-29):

# webdash_harness — run the firmware web dashboard without hardware

The dashboard is ~1,100 lines of HTML/CSS/JS living inside a PROGMEM string in
`firmware/src/WebDashboard.cpp`. `pio run` proves it *compiles*; it proves nothing
about whether the JavaScript **runs**. This harness executes it.

It extracts the blob, stubs the WebSocket the page expects, and drives the real page
under jsdom — so a broken DOM id, a typo'd handler, or a mis-wired button fails here
instead of on a phone in the field.

```bash
cd tools/webdash_harness
npm ci                     # installs the pinned dev-only jsdom version
npm test                   # extracts WebDashboard.cpp and runs the UI checks
```

What it checks: page loads clean, IPT mode + ARM/STOP/SOLVE recovering a known hidden
target, degenerate sweeps being blocked rather than trusted, recording surviving a
FREEZE, the protocol log, `RAW_COUNTS`, and that calibration APPLY + SAVE (NVS)
actually sends `SAVE_PPR` while APPLY (RAM) does not.

`window.__sweep(P, L, n, halfAngleDeg)` synthesises the operator's spiral hand motion
around a hidden target, which is what makes the IPT path testable at all.

**The numerics are covered separately** and with no npm dependency, by
`tools/ipt/tests/test_web_solver_parity.py` — that one runs in normal `pytest`, slices
the solver out of the blob, and asserts it agrees with `tools/ipt/solver.py` under
node. This harness covers the *UI wiring*; that test covers the *math*.

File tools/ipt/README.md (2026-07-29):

# Quick IPT — hidden-point measurement

Recover a target point that the pen **cannot touch directly** (around a corner,
behind an obstacle, inside a recess) using the same method as the Prodim Proliner V9's
"Quick IPT" (Inverted Pen Technology).

You hold the pen **tip** fixed on the hidden target and sweep the **handle**. The
draw-wire attaches to the pen *body*, a fixed distance `L` from the tip, so every
point evka_position measures during the sweep lies on a **sphere of radius `L`
centred on the target**. Fitting that sphere returns the target. evka_position has
the same sensor topology as the Proliner V9 (one wire + two angle encoders), so the
method transfers directly — this tool needs **no firmware change**.

Prototype limitation: theta count loss is unresolved, so real IPT accuracy is not accepted. Results
are sensor-frame points. `tools/evka_gui` does not apply an endpoint/world transform, and no current
transform has been accepted.

```
            measured attachment points  M_i  (on a sphere of radius L)
                      .  .  .
                  .            .
                .    target P    .        the tip is held on P;
                .   (tip fixed)  .        the handle sweeps, so the wire-side
                  .            .          attachment point M_i traces a sphere
                      .  .  .             centred on P.
```

## Quick start

```bash
# Unified GUI (recommended) — connect once, then use inline Quick IPT
python -m tools.evka_gui --tcp 192.168.1.50:8080

# Standalone IPT (own connection UI)
# WiFi (raw CMD server, default port 8080) — AP CMDCNC_EVKA @ 192.168.1.50
python -m tools.ipt --tcp 192.168.1.50:8080

# Serial
python -m tools.ipt --serial /dev/ttyUSB0 --baud 115200

# No flag → opens disconnected; pick TCP/serial in the panel
python -m tools.ipt
```

When using `evka-gui` / `python -m tools.evka_gui`, use the inline **Quick IPT**
group on the main panel (ARM/STOP/SOLVE). Optional toolbar **IPT plots…** opens
full-height projections. No second connection is needed.

**Dependencies:** `numpy`, `PyQt5`, `pyqtgraph`, `pyserial` (all in `pyproject.toml`).

## Trying it out — step by step

### Option A: No hardware (solver self-check)

You can run the sphere-fit solver on synthetic data right now, no ESP32 needed:

```bash
python -m tools.ipt.solver
```

Expected output:

```
P_hat = [1200.101 -450.051  300.389]  L_hat = 399.596 mm  rms = 0.0734 mm  cond = 35  slip = ok  geom = ok
target error = 0.405 mm
```

This generates 12 points on a synthetic 35° spiral, fits the sphere, and prints
the recovered target, pen length, RMS residual, and quality flags. It proves the
math works before you touch any hardware.

### Option B: Run the tests

```bash
python -m pytest tools/ipt/tests/ -v
```

10 offline tests: solver recovery, known-radius path, slip detection, geometry
conditioning, too-few-points, large-offset centering, capture arming, dedup,
invalid-frame dropping, and TCP XYZ/SENSOR pairing.

### Option C: Connect to a real EVKA device over WiFi (TCP)

**Recommended:** use the unified GUI and the inline **Quick IPT** panel after
connecting (no second socket). Standalone steps below still apply if you
prefer `python -m tools.ipt`.

1. **Power on the EVKA device.** It creates a WiFi AP:
   - SSID: `CMDCNC_EVKA`
   - Password: `cmdcnc1234`

2. **Connect your PC to that WiFi network.**

3. **Run the tool:**
   ```bash
   # Unified GUI (recommended)
   python -m tools.evka_gui --tcp 192.168.1.50:8080
   # Connect, then use inline Quick IPT

   # Standalone IPT
   python -m tools.ipt --tcp 192.168.1.50:8080
   ```
   Or open standalone without arguments and fill in the panel:
   ```bash
   python -m tools.ipt
   ```
   Then select **TCP**, enter `192.168.1.50` : `8080`, click **CONNECT**.

4. **If the device is in router (STA) mode** instead of AP, use the STA IP:
   ```bash
   python -m tools.ipt --tcp 192.168.1.84:8080
   ```
   (STA static IP is `192.168.1.84`, gateway `192.168.1.254` — see
   `SphericalSensor.h` for the current profile.)

5. **Subnet conflict?** If `192.168.1.50` is unreachable, your PC may be routing
   it to your home router. Disconnect from home/office WiFi and connect to
   `CMDCNC_EVKA` only.

### Option D: Connect over serial (USB)

1. **Plug the ESP32 into your PC** via USB.

2. **Find the serial port:**
   ```bash
   # Linux
   ls /dev/ttyUSB* /dev/ttyACM*

   # macOS
   ls /dev/cu.usbserial* /dev/cu.usbmodem*

   # Windows (Device Manager → Ports)
   #   COM3, COM4, etc.
   ```

3. **Run the tool:**
   ```bash
   # Linux
   python -m tools.ipt --serial /dev/ttyUSB0 --baud 115200

   # macOS
   python -m tools.ipt --serial /dev/cu.usbserial-XXXX --baud 115200

   # Windows
   python -m tools.ipt --serial COM3 --baud 115200
   ```

   Or open the GUI and pick **Serial** in the connection panel.

### Using the GUI

Once connected, the GUI has three panels:

**Connection** (top right):
| Field | Default | Description |
|---|---|---|
| TCP / Serial radio | TCP | Pick transport |
| Host (TCP) | `192.168.1.50` | AP fallback IP |
| Port (TCP) | `8080` | CMD TCP port |
| Serial port | `/dev/ttyUSB0` | USB serial device |
| Baud | `115200` | Firmware baud rate |
| CONNECT / DISCONNECT | — | Start/stop transport |

**Capture** (middle right):
| Control | Action |
|---|---|
| Known pen length L | Enter mm (e.g. `400`) or leave blank for self-calibration |
| ARM / START SWEEP | Begin capturing points (clears previous buffer) |
| STOP | Stop capturing |
| SOLVE | Fit sphere to captured points and show result |
| CLEAR | Clear points and result |

**Result** (bottom right):
| Field | Shows |
|---|---|
| Points | Count of accepted samples (need ≥ 8) |
| P | Recovered target X, Y, Z in mm (sensor frame) |
| L_hat / L used | Fitted pen length (self-cal) or entered value + independent fit |
| RMS residual | Sphere fit quality in mm + status [ok/warn/reject] |
| Geometry cond | Sweep quality number + status [ok/warn/block] |

**3D view** (left): green dots = captured points, blue translucent sphere = fit,
orange marker = recovered target P.

### Doing a real measurement

1. **Connect** (TCP or serial — see above).
2. **Attach a pen** to the draw-wire body at a fixed offset from the tip. The
   exact offset doesn't matter if you leave L blank (self-calibrating).
3. **Hold the pen tip firmly** on the point you can't reach directly.
4. Click **ARM / START SWEEP**.
5. **Sweep the handle** in a wide spiral — aim for 30°+ of movement in multiple
   directions. The bigger the sweep, the better the geometry.
6. Click **STOP** (need at least 8 points; 15–20 is better).
7. Click **SOLVE**.
8. **Check the quality flags:**
   - **RMS residual [ok]** + **Geometry cond [ok]** → good measurement, read P.
   - **[warn]** → marginal; consider re-measuring with a wider sweep.
   - **[reject]** or **[block]** → re-measure. Tip slipped or sweep too small.
9. The recovered **P** (X, Y, Z) is in the sensor origin frame, in mm.

### Headless use (no GUI)

`solve_ipt()` works on any numpy array — useful for batch processing or scripts:

```python
import numpy as np
from tools.ipt.solver import solve_ipt

# M is an (n, 3) array of measured attachment points in mm
M = np.array([
    [1200.1, -450.0, 300.2],
    [1205.3, -448.1, 310.5],
    # ... at least 8 points
])

# Self-calibrating (L unknown)
out = solve_ipt(M)
print(out["P"], out["L_hat"], out["L_fit"],
      out["slip_warning"], out["geom_warning"])

# Known pen length (L = 400 mm)
out = solve_ipt(M, L=400.0)
print(out["P"], out["L_hat"], out["L_fit"])  # L_hat == 400, L_fit == independent
```

Return dict fields:

| Key | Type | Meaning |
|---|---|---|
| `ok` | bool | True if enough points; False if < 8 |
| `P` | np.ndarray (3,) | Recovered target [X, Y, Z] in mm |
| `L_hat` | float | Fitted pen length (self-cal) or entered L (known-L mode) |
| `L_fit` | float | Independent algebraic sphere-fit radius (sanity check) |
| `rms_resid` | float | RMS residual of the sphere fit in mm |
| `cond` | float | Geometric Jacobian condition number |
| `n_points` | int | Number of accepted points |
| `slip_warning` | str | "ok" / "warn" / "reject" |
| `geom_warning` | str | "ok" / "warn" / "block" |

## Workflow

```mermaid
flowchart LR
    A[Connect<br>TCP / serial] --> B[Hold tip<br>on target]
    B --> C[ARM<br>start sweep]
    C --> D[Sweep handle<br>wide spiral]
    D --> E[STOP]
    E --> F[SOLVE]
    F --> G{Quality?}
    G -- ok --> H[Read P]
    G -- warn/reject --> I[Re-measure<br>wider sweep]
    I --> C
```

1. **Connect** (TCP or serial).
2. Hold the pen **tip** on the hidden target.
3. **ARM / START SWEEP**, then sweep the handle through a **wide spiral** (the
   bigger the cone, the better the result — see "Why a big movement").
4. **STOP**, then **SOLVE**.
5. Read the recovered **P**, the self-calibrated **L_hat** (or **L used** if you
   entered a fixed value), and the quality flags. Leave the *Known pen length L*
   field blank to self-calibrate, or enter the nominal pen length (e.g. 200/400/600)
   to use the better-conditioned solver and sanity-check `L_fit` against it.

The recovered **P is in the sensor origin frame** (the boot zero-point set by
`setZeroPoint()`), in mm — the same frame as the live X/Y/Z readout, *not* a world
frame.

## Reading the quality flags

| Field | Meaning |
|---|---|
| **Points** | Accepted samples. Need ≥ 8; more averages down noise (~1/√n). |
| **L_hat** | Self-calibrated pen length (when L field is blank). Should match your physical pen within a few mm. |
| **L used / fit** | When L is entered: `L used` is the fixed value; `fit` is the independent algebraic sphere-fit radius — compare to sanity-check the entered length against the data. |
| **RMS residual** | How cleanly the points lie on one sphere. Rises when the tip slips. |
| **Geometry cond** | Dilution of precision from the sweep shape. High = sweep too small/flat. |

Status bands (heuristics, tuned in simulation — re-tune on real hardware):

- **RMS residual** — `ok < 2 mm`, `warn 2–5 mm`, `reject > 5 mm`.
- **Geometry cond** — `ok` up to ~25° sweep, `warn` ~10–20° (≈2 mm error),
  `block` below ~5° (≈20 mm error).

### Why a big movement?

A small or single-plane sweep leaves the sphere centre poorly determined along the
sweep axis (a small patch of a big sphere is nearly flat — it doesn't pin a
centre). This is geometric dilution of precision, exactly like poor satellite
geometry in GNSS. Simulation: a 3° sweep gives ~85 mm error; a 70° sweep gives
~0.17 mm. If `Geometry cond` warns, **open the sweep wider**. In tight spaces, a
two-direction "cross" motion is the minimum viable substitute for a full spiral.

### "Reject" / tip slipped

If the tip wanders off the target during the sweep, the points no longer lie on a
single sphere and the RMS residual climbs. A `reject` flag means re-measure.

## Hardware assumptions

- **Sensor topology:** one draw-wire encoder (radius) + two rotary encoders (θ, φ).
- **Coordinate frame:** sensor origin at boot zero-point; X/Y/Z in mm; θ azimuth, φ elevation from horizontal.
- **Update rate:** 20 Hz DATA stream over serial; 20 Hz X/Y/Z + SENSOR over TCP.
- **Validity:** firmware emits `is_valid` flag; invalid frames are dropped by the capture buffer.
- **Dedup:** points closer than 1 mm to the last accepted point are rejected (20 Hz emits many near-identical frames when the handle is momentarily still).

## Troubleshooting

| Symptom | Likely cause | Fix |
|---|---|---|
| `need >= 8 points` | Sweep too short or dedup too aggressive | Sweep wider; move handle more between samples |
| `RMS residual: reject` | Tip slipped off target | Re-measure; hold tip firmly on target |
| `Geometry cond: block` | Sweep too small or flat | Open sweep wider; use spiral motion |
| `L_fit` differs from entered `L` by >5 mm | Entered L is wrong or tip slipped | Re-measure pen length; leave L blank to self-calibrate |
| No points captured | Not armed or invalid frames | ARM first; check `is_valid` in firmware stream |
| TCP connection fails | Wrong IP/port or subnet conflict | Use AP fallback `192.168.1.50:8080`; disconnect from home/office WiFi |

## Known-radius mode

When you enter a fixed pen length `L` in the GUI:

- The solver uses the better-conditioned differencing method (trilateration).
- The radius is held at `L` during refinement.
- `L used` shows the fixed value you entered.
- `L fit` shows the independent algebraic sphere-fit radius — if this differs from `L` by more than a few mm, the entered length is wrong or the tip slipped.

When you leave `L` blank:

- The solver fits both centre and radius (self-calibrating).
- `L_hat` is the fitted radius — should match your physical pen within a few mm.

## Files

| File | Role |
|---|---|
| `solver.py` | Sphere-fit estimators + `solve_ipt()` entry point. Pure numpy; no I/O. |
| `capture.py` | Armed buffer: dedup + TCP XYZ/SENSOR pairing + serial frame ingest. |
| `gui.py` | Standalone pyqtgraph GUI (own connection panel). |
| `../evka_gui/ipt_panel.py` | Embedded IPT panel for unified GUI (shared connection). |
| `../evka_gui/ipt_window.py` | Optional IPT projection plot pop-out. |
| `__main__.py` | CLI entry point (`python -m tools.ipt`). |
| `tests/` | Offline pytest suite (no hardware): `test_solver.py`, `test_capture.py`. |

```mermaid
flowchart LR
    FW[ESP32 firmware<br>unchanged] -->|raw lines| EVKA[evka_gui _drain]
    FW -->|XYZ stream 20 Hz| STAND[standalone ipt/gui.py]
    EVKA --> CAP[capture.py<br>armed buffer]
    STAND --> CAP
    CAP -->|point cloud| SOL[solver.py<br>sphere fit]
    SOL --> OUT[Result: P, L, flags]
```

`solve_ipt(M, L=None)` is usable headlessly on any `(n, 3)` array of mm points:

```python
import numpy as np
from tools.ipt.solver import solve_ipt
out = solve_ipt(my_points)          # {ok, P, L_hat, L_fit, rms_resid, cond, n_points, ...}
print(out["P"], out["L_hat"], out["L_fit"], out["slip_warning"], out["geom_warning"])
```

## Tests

```bash
python -m pytest tools/ipt/tests/ -q
python -m tools.ipt.solver          # self-check demo on a synthetic spiral
```

## Implementation notes

- **Transport asymmetry.** Serial carries one full `DATA,...` line per cycle (with
  validity); the raw TCP server sends `X..,Y..,Z..` and `SENSOR,...` as *separate*
  lines, so the TCP path pairs each XYZ line with the following SENSOR line to
  recover validity.
- **Threading.** Transports run on daemon threads. The TCP client only enqueues
  raw lines; a `QTimer` on the GUI thread drains the queue and polls the serial
  `DataStore`. All pyqtgraph GL updates happen on the GUI thread only.
- **Centering.** The cloud is centred before the algebraic fit so the condition
  number reflects geometry, not coordinate magnitude. Because that removes the
  scale-driven ill-conditioning, the *geometry* warning instead uses the condition
  number of the geometric Jacobian (the true dilution-of-precision indicator).
- **Finite-value guard.** TCP XYZ floats are checked for `isfinite` before acceptance;
  serial `DATA` parsing already rejects non-finite values.

## Limitations

- **3-DOF only.** evka_position returns a point, not a pose (no orientation sensor).
  IPT recovers the hidden *point*, not the full 6-DOF pose of the pen tip.
- **Tip slip detection.** RMS residual flags slip, but cannot correct it. If the tip
  wanders, re-measure.
- **Sweep geometry.** Small or flat sweeps give poor geometry conditioning. The
  `Geometry cond` warning is the operator's cue to sweep wider.
- **Coordinate frame.** Results are in the sensor origin frame (boot zero-point),
  not a world frame. Transform externally if you need world coordinates.

## References

- Prodim patent **US 9,267,794 B2** / EP 2,792,994 B1 (Teune & Janssen) — the IPT method.
- Z. Yaniv, *"Which Pivot Calibration?"*, SPIE 2015 — pivot-calibration estimators/accuracy.
- I. D. Coope, *"Circle fitting by linear and nonlinear least squares"*, JOTA 76(2), 1993.

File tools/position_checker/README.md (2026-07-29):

# tools/position_checker — live 3D visualizer + CMD GUI

> **Legacy standalone tools.** Use the canonical GUI instead:
> `python -m tools.evka_gui`. Legacy entry points remain as shims
> (`--legacy-visualizer`, `--legacy-cmd-gui`).

This package still provides shared
libraries (`tcp_client.py`, `cmd_display.py`, `parser.py`) consumed by
`tools/evka_gui` and `tools/ipt`.

The canonical wire contract is [../../docs/PROTOCOL.md](../../docs/PROTOCOL.md), not `cmd_main.py`.

Two host-side apps that read the firmware's telemetry:

- **Visualizer** — reads the serial `DATA,` stream and renders a live 3D trajectory.
- **Legacy TCP GUI** - connects over TCP and shows live X/Y/Z + R/theta/phi, min/max tracking,
  saved points, and WiFi settings.

## Run

```bash
# From the repo root, with the venv active (see ../../CONTRIBUTING.md)
python -m tools.position_checker.main --legacy-visualizer --port /dev/ttyUSB0
python -m tools.position_checker.cmd_main                    # TCP CMD GUI
python -m tools.position_checker.main --legacy-visualizer --replay-file frames.csv --fps 20
```

The legacy visualizer defaults to the sensor frame. After both report gates pass, a session JSON can
be applied only with an explicit path:

```bash
python -m tools.position_checker.main --legacy-visualizer --port /dev/ttyUSB0 \
  --calibration docs/calibration/sessions/current/calibration.json
```

It does not search for or auto-load a shared/default JSON. A JSON with a non-`PASS` verdict is
rejected.

## Tests

```bash
pytest tools/position_checker/tests -q
```

Protocol details live in [../../docs/PROTOCOL.md](../../docs/PROTOCOL.md). New operator workflows
use `tools/evka_gui`.

## Module map

| Module | Role |
|---|---|
| `main.py` / `__main__.py` | Visualizer entry point (serial/replay) |
| `cmd_main.py` / `cmd_gui.py` / `cmd_display.py` | Legacy TCP GUI and display helpers |
| `parser.py` | Parse `DATA,` / `X,Y,Z` / `SENSOR,` lines |
| `serial_reader.py` / `tcp_client.py` / `replay_reader.py` | Transports |
| `data_store.py` / `transform.py` / `gui.py` | State, coordinate transform, pyqtgraph view |

Explicit legacy calibration use does not make the transform accepted and does not change canonical
`evka_gui` sensor-frame behavior.

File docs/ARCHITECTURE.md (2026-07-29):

# Architecture and Prototype Boundaries

This document describes the current repository implementation. It does not certify the assembled
v4 prototype. Compile-time configuration is defined in `firmware/src/SphericalSensor.h`; runtime
protocol behavior is defined in `firmware/src/EvkaPosition.cpp` and
`firmware/src/CmdTcpServer.cpp`.

See [PROTOCOL.md](PROTOCOL.md) for the canonical telemetry and command/reply contract and
[firmware/CODE_WALKTHROUGH.md](firmware/CODE_WALKTHROUGH.md) for source navigation.

## Processing Pipeline

Every 50 ms, the main loop performs:

```text
PCNT encoder counters
    -> subtract boot/command zero offsets
    -> apply runtime PPR and encoder signs
    -> spherical (r mm, theta deg, phi deg)
    -> Cartesian sensor frame (X, Y, Z mm)
    -> limits/finite validation
    -> Cartesian EMA filter (alpha 0.2)
    -> Serial, WebSocket, and TCP telemetry
```

- Theta and phi use Autonics E40S6-5000 encoders.
- Radius uses an OPKON DWEM2 draw-wire encoder.
- Main firmware uses `ESP32Encoder` hardware PCNT on classic and v4 targets.
- `RAW_COUNTS` is zero-relative because `readRawEncoders()` subtracts stored offsets.
- Invalid frames bypass Cartesian filtering; the filter is re-primed after zero operations.

## Coordinate Frames

Firmware uses elevation/azimuth spherical coordinates:

```text
x = r * cos(phi) * cos(theta)
y = r * cos(phi) * sin(theta)
z = r * sin(phi)
```

Theta is azimuth from +X in the XY plane. Phi is elevation from horizontal. Signs are board-specific:
v4 uses theta `+1` / phi `-1`; classic uses theta `-1` / phi `+1`.

The firmware output frame is the **sensor frame** established by the zero offsets. The canonical
`tools/evka_gui` displays and records that frame. Its software-zero controls create a client-side
display/session offset only. Quick IPT also returns a sensor-frame point.

The calibration tools can fit a candidate rigid transform:

```text
world = R @ sensor + t
```

No transform or shared/default calibration JSON is currently accepted. `evka_gui` never applies a
world transform to live telemetry. A passing session JSON may be supplied explicitly only to the
legacy visualizer.

## Current Configuration Summary

| Constant | Current source value | Meaning |
|---|---:|---|
| `PPR_ROTARY` | 20000 | E40S6-5000 at X4 quadrature |
| `PPR_WIRE` | 8000 | DWEM2 theoretical X4 count; mounted calibration pending |
| `DRUM_CIRCUM_MM` | 200 | Draw-wire conversion basis |
| `ENCODER_THETA_SIGN` | v4 +1; classic -1 | Count-to-theta sign |
| `ENCODER_PHI_SIGN` | v4 -1; classic +1 | Count-to-phi sign |
| `UPDATE_PERIOD_MS` | 50 | 20 Hz main update |
| `ENABLE_WIFI` | 1 | AP/STA dashboard and WebSocket enabled |
| `ENABLE_CMD_TCP` | 1 | TCP port 8080 enabled |
| `ENABLE_ESPNOW_REMOTE` | 1 | Wireless pendant receiver enabled |
| `ENABLE_BATTERY_MONITOR` | 1 | Battery/supply ADC reporting compiled in |
| `BATTERY_ADC_12V_INPUT` | 0 | Current scaling is the 1S divider path |

NVS values in namespace `evka_cal` override the PPR compile defaults. `CONSTANTS` reports the
runtime values.

## Board Pin Maps

| Target | Theta A/B | Phi A/B | Wire A/B | Battery ADC | Status LED |
|---|---|---|---|---|---|
| Classic `wemos_d1_r32` | 14 / 12 | 32 / 35 | 16 / 17 | GPIO36 | GPIO2 monochrome |
| v4 `esp32s3_v4` | 9 / 10 | 4 / 5 | 7 / 8 | GPIO1, 1S divide-by-2 source path | DevKit WS2812 GPIO48 by default |
| v4 `esp32s3_v4_rgb38` | 9 / 10 | 4 / 5 | 7 / 8 | GPIO1 | DevKit WS2812 GPIO38 override |

### v4 Physical Connector Order

| Connector | Axis | PCB-derived order |
|---|---|---|
| J1 | Wire | `1=A, 2=GND, 3=B, 4=+5V` |
| J2 | Phi | `1=+5V, 2=A, 3=GND, 4=B` |
| J3 | Theta | `1=A, 2=GND, 3=B, 4=+5V` |

J2 A/B therefore reach GPIO4/GPIO5 through pins 2/4, not pins 1/3. This mapping is derived from the
current v4 KiCad PCB/pad nets and source pin comments. It was **not physically reverified in this
final documentation pass**.

## Status LED and Battery

Current source includes `StatusLed.{h,cpp}`:

- v4 default uses a DevKit NeoPixel on GPIO48; `esp32s3_v4_rgb38` selects GPIO38.
- Source states include boot calibration, ESP-NOW fault, invalid position, STA reconnecting,
  connected, AP-only, and transient zero/remote/blink overlays.
- Classic builds retain the GPIO2 off/blink/on WiFi indication.

These are source-defined behaviors, not newly physically verified LED behavior.

Battery monitoring is compiled in (`ENABLE_BATTERY_MONITOR=1`). With the current
`BATTERY_ADC_12V_INPUT=0`, source interprets the ADC as a 1S LiPo divide-by-2 path and emits
`BATT,...` after `STATUS`. This pass did not verify ADC scaling or battery accuracy on hardware.

## Runtime Components

| Component | Responsibility |
|---|---|
| `EvkaPosition.cpp` | Setup/loop, zeroing, command dispatch, 20 Hz fan-out, ESP-NOW events |
| `SphericalSensor.{h,cpp}` | Configuration, PCNT reads, conversions, validation, filter, NVS, battery |
| `StatusLed.{h,cpp}` | Classic and RGB status state machine |
| `WebDashboard.{h,cpp}` | AP/STA management, HTTP dashboard, WebSocket queue/fan-out |
| `CmdTcpServer.{h,cpp}` | TCP port 8080, client limits, line framing, XYZ/SENSOR stream |
| `tools/evka_gui` | Canonical sensor-frame host UI |
| `tools/calibration` | Candidate sensor-to-world fitting/report tools |

The vendor C# application has been deleted from the supported architecture. `CMD` remains only as a
compatibility name for the retained TCP protocol.

## Networking and Security

The device runs AP+STA when STA credentials are configured and keeps the AP fallback available.
Current AP is `CMDCNC_EVKA` / `cmdcnc1234` at `192.168.1.50`; current STA profile is
`192.168.1.84/24` with gateway `192.168.1.254`.

TCP and WebSocket commands are unauthenticated. Fixed credentials are trusted-lab-only, not a
production security boundary. Do not expose ports 80/8080 to an untrusted network.

## Open Architecture Risks

- Theta loses or fails to return counts; mechanical slip/backlash and signal integrity remain open.
- v4 connector mapping needs a recorded physical re-verification.
- Mounted encoder constants are not accepted.
- No endpoint/world transform is accepted or applied by the canonical GUI.
- Full three-encoder accuracy, repeatability, battery, LED, WiFi endurance, and system validation are
  not signed off.
- The repository has no redistribution license and no public production status.

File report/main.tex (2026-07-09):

\documentclass[11pt,a4paper]{article}

% --- PACKAGES ---
\usepackage[utf8]{inputenc}
\usepackage[T1]{fontenc}
\usepackage{lmodern}
\usepackage[top=28mm, bottom=28mm, left=25mm, right=25mm]{geometry}
\usepackage{amsmath}
\usepackage{amssymb}
\usepackage{booktabs}
\usepackage{graphicx}
\usepackage{enumitem}
\usepackage{microtype}
\usepackage{parskip}
\usepackage{xcolor}
\usepackage{array}
\usepackage{tabularx}
\usepackage{fancyhdr}
\usepackage{titlesec}
\usepackage{abstract}
\usepackage{caption}
\usepackage{tikz}
\usetikzlibrary{arrows.meta, shapes.geometric, positioning, fit, backgrounds, shadows}
\usepackage{hyperref}

% --- HYPERREF ---
\hypersetup{
    colorlinks=true,
    linkcolor=blue,
    citecolor=blue,
    urlcolor=blue,
    pdftitle={Spherical 3D Position Tracking System},
    pdfauthor={Yunus Danabas}
}

% --- COLOURS ---
\definecolor{sectionblue}{rgb}{0.10, 0.28, 0.58}
\definecolor{boxblue}{rgb}{0.85, 0.92, 1.00}
\definecolor{boxgreen}{rgb}{0.85, 1.00, 0.88}
\definecolor{arrowgray}{rgb}{0.40, 0.40, 0.40}

% --- SECTION HEADINGS ---
\titleformat{\section}
  {\normalfont\Large\bfseries\color{sectionblue}}
  {\thesection}{1em}{}[\vspace{2pt}\titlerule]
\titleformat{\subsection}
  {\normalfont\large\bfseries}{\thesubsection}{1em}{}

% --- HEADER / FOOTER ---
\pagestyle{fancy}
\fancyhf{}
\fancyhead[L]{\small\itshape Spherical 3D Position Tracking System}
\fancyhead[R]{\small\thepage}
\renewcommand{\headrulewidth}{0.4pt}
\renewcommand{\footrulewidth}{0pt}

% --- CAPTIONS ---
\captionsetup{font=small, labelfont={it}, labelsep=period}

% --- ABSTRACT STYLE ---
\renewenvironment{abstract}
  {\begin{center}\begin{minipage}{0.88\textwidth}
   \rule{\textwidth}{0.4pt}\par\smallskip
   \noindent\textbf{\abstractname}\par\smallskip}
  {\par\rule{\textwidth}{0.4pt}\end{minipage}\end{center}\bigskip}

% --- TITLE ---
\title{%
  \bfseries\LARGE Spherical 3D Position Tracking System\\[8pt]
  \large ESP32-Based Three-Sensor Approach\\[6pt]
  \normalsize\rule{\linewidth}{0.6pt}
}
\author{Yunus Danabas}
\date{March 2026}

% ==================================================================
\begin{document}

\maketitle
\thispagestyle{empty}

\begin{abstract}
This report describes the design, implementation, and calibration of a
real-time 3D position tracking system based on spherical coordinates.
Two Autonics E40S6 incremental rotary encoders measure azimuth
(\(\theta\)) and elevation (\(\phi\)), while an OPKON DWE3000 draw-wire
encoder measures radial distance (\(r\)).  An ESP32-WROOM-32 samples
all three channels at 20\,Hz, converts raw quadrature counts to
Cartesian \((X,Y,Z)\) coordinates, and streams the result over serial
and an optional WiFi web dashboard.  The calibrated system achieves an
angular resolution of \(0.018^\circ\) and a radial resolution of
\(0.025\)\,mm, with a theoretical worst-case positional error of
\(\pm 3.2\)\,mm at 5\,m range.
\end{abstract}

\tableofcontents
\newpage

% ==================================================================
\section{Introduction}

High-precision 3D position measurement is required in robotics
calibration, structural monitoring, and industrial metrology.
Commercial solutions such as laser trackers are accurate but expensive.
For workspaces on the scale of a few metres, where millimetre-level
accuracy suffices, there is a clear gap for an affordable alternative.

This project addresses that gap with a spherical coordinate measurement
approach: a fixed-base assembly with two rotary joints and a retractable
wire.  Azimuth and elevation are measured by incremental rotary encoders;
radial distance by a draw-wire encoder.  An ESP32 converts the three
measurements into real-time Cartesian coordinates and serves data over
serial and WiFi.

The remainder of this report is organised as follows:
Section~\ref{sec:arch} describes the system architecture and processing
pipeline.  Section~\ref{sec:hw} covers the hardware design.
Section~\ref{sec:sw} details the firmware and communication interfaces.
Section~\ref{sec:cal} presents calibration procedures.
Section~\ref{sec:results} reports achieved resolution and accuracy.
Section~\ref{sec:conclusion} concludes.

% ==================================================================
\section{System Architecture}
\label{sec:arch}

\subsection{Kinematic Chain}

The mechanical structure forms a serial chain anchored at a fixed base.
Figure~\ref{fig:kinematic} illustrates the three degrees of freedom and
how they map to spherical coordinates.

\begin{figure}[h]
\centering
\begin{tikzpicture}[
  node distance=0pt,
  block/.style={
    rectangle, rounded corners=4pt, minimum width=2.2cm, minimum height=0.9cm,
    align=center, fill=boxblue, draw=sectionblue, line width=0.8pt,
    font=\small\bfseries
  },
  sensor/.style={
    rectangle, rounded corners=4pt, minimum width=2.0cm, minimum height=0.7cm,
    align=center, fill=boxgreen, draw=green!50!black, line width=0.7pt,
    font=\footnotesize
  },
  arr/.style={-{Stealth[length=6pt]}, line width=1.2pt, color=arrowgray},
  label/.style={font=\footnotesize\itshape, color=sectionblue}
]
  % Main chain nodes
  \node[block] (base) {Base\\(Origin)};
  \node[block, right=1.4cm of base] (theta) {Theta Joint\\(\(\theta\))};
  \node[block, right=1.4cm of theta] (phi) {Phi Joint\\(\(\phi\))};
  \node[block, right=1.4cm of phi] (wire) {Draw-Wire\\(\(r\))};
  \node[block, right=1.4cm of wire] (target) {Target\\Point};

  % Arrows between main nodes
  \draw[arr] (base) -- (theta);
  \draw[arr] (theta) -- (phi);
  \draw[arr] (phi) -- (wire);
  \draw[arr] (wire) -- (target);

  % Sensor nodes below
  \node[sensor, below=0.6cm of theta] (enc_theta) {E40S6\\GPIO 32/35};
  \node[sensor, below=0.6cm of phi]   (enc_phi)   {E40S6\\GPIO 14/12};
  \node[sensor, below=0.6cm of wire]  (enc_wire)  {DWE3000\\GPIO 16/17};

  % Dashed connections to sensors
  \draw[dashed, color=gray!70, line width=0.7pt] (theta) -- (enc_theta);
  \draw[dashed, color=gray!70, line width=0.7pt] (phi)   -- (enc_phi);
  \draw[dashed, color=gray!70, line width=0.7pt] (wire)  -- (enc_wire);

  % Range labels above
  \node[label, above=0.3cm of theta] {\(-180^\circ \ldots +180^\circ\)};
  \node[label, above=0.3cm of phi]   {\(0^\circ \ldots 180^\circ\)};
  \node[label, above=0.3cm of wire]  {100\,mm \ldots 3000\,mm};
\end{tikzpicture}
\caption{Kinematic chain and sensor assignment.  Blue blocks show mechanical
joints; green blocks show the encoder and GPIO used to measure each degree of
freedom.}
\label{fig:kinematic}
\end{figure}

\subsection{Processing Pipeline}

Figure~\ref{fig:pipeline} shows the three-stage data transformation
running at 20\,Hz in firmware.

\begin{figure}[h]
\centering
\begin{tikzpicture}[
  stage/.style={
    rectangle, rounded corners=5pt,
    minimum width=3.4cm, minimum height=1.2cm,
    align=center, fill=boxblue, draw=sectionblue, line width=0.8pt,
    font=\small\bfseries
  },
  detail/.style={font=\footnotesize, text=black!70, align=center},
  arr/.style={-{Stealth[length=7pt]}, line width=1.4pt, color=sectionblue}
]
  \node[stage] (raw) {Raw Counts\\(int32)};
  \node[stage, right=1.8cm of raw] (sph) {Spherical\\Coords};
  \node[stage, right=1.8cm of sph] (ema) {EMA Filter\\(\(\alpha=0.2\))};
  \node[stage, right=1.8cm of ema] (cart) {Cartesian\\$(X,Y,Z)$\,mm};

  \draw[arr] (raw) -- node[above, font=\scriptsize\itshape]{DEG/MM per pulse} (sph);
  \draw[arr] (sph) -- node[above, font=\scriptsize\itshape]{\(r,\theta,\phi\;\to\;X,Y,Z\)} (ema);
  \draw[arr] (ema) -- node[above, font=\scriptsize\itshape]{smooth} (cart);

  \node[detail, below=0.5cm of raw]  {\(\theta\), \(\phi\), \(r\) counts\\3 encoders};
  \node[detail, below=0.5cm of sph]  {\(\theta\) deg, \(\phi\) deg\\\(r\) mm};
  \node[detail, below=0.5cm of ema]  {per-axis\\low-pass};
  \node[detail, below=0.5cm of cart] {streamed over\\serial / WiFi};
\end{tikzpicture}
\caption{Firmware data-processing pipeline.  Each stage runs once per 50\,ms
update cycle.}
\label{fig:pipeline}
\end{figure}

\subsection{Coordinate Convention}

The physics spherical convention is used throughout:

\begin{align}
  X &= r \sin\phi \cos\theta \label{eq:x}\\
  Y &= r \sin\phi \sin\theta \label{eq:y}\\
  Z &= r \cos\phi             \label{eq:z}
\end{align}

where \(r\) is in millimetres and \(\theta\), \(\phi\) are in degrees
(converted to radians before evaluating the trigonometric functions).

% ==================================================================
\section{Hardware Design}
\label{sec:hw}

The hardware uses entirely off-the-shelf components.  The only bespoke
element is the voltage-level shifting network required to interface 5\,V
encoder outputs with the ESP32's 3.3\,V GPIO.

\subsection{Microcontroller}

The system is built around an \textbf{ESP32-WROOM-32} (Wemos D1~R32
form factor).  Key features:

\begin{itemize}[noitemsep, topsep=4pt]
  \item Dual-core Xtensa LX6 at 240\,MHz --- interrupts on one core,
        main loop on the other.
  \item Six interrupt-capable GPIO pins for three quadrature channels.
  \item Integrated 802.11\,b/g/n WiFi for the optional web dashboard.
  \item ADC1 channel (GPIO~36) for battery voltage monitoring.
\end{itemize}

\subsection{Encoders}

\renewcommand{\arraystretch}{1.3}
\begin{table}[h]
\centering
\caption{Encoder specifications.}
\label{tab:encoders}
\begin{tabular}{@{}llll@{}}
\toprule
\textbf{Axis} & \textbf{Model} & \textbf{Type} &
  \textbf{PPR (\(\times\)4)} \\
\midrule
Theta (\(\theta\)) & Autonics E40S6-5000 & Incremental rotary & 20\,000 \\
Phi (\(\phi\))     & Autonics E40S6-5000 & Incremental rotary & 20\,000 \\
Radius (\(r\))     & OPKON DWE3000       & Draw-wire          & \phantom{0}8\,020 \\
\bottomrule
\end{tabular}
\end{table}

All encoders output 0--5\,V TTL quadrature signals and are decoded
using the PaulStoffregen \texttt{Encoder} library (hardware ISR, X4
quadrature).

\subsection{Signal Conditioning}

Every signal line passes through a 10\,k\(\Omega\) / 20\,k\(\Omega\)
resistive voltage divider:

\[
  V_\text{GPIO}
    = 5\,\text{V} \times \frac{20\,\text{k}\Omega}
                              {10\,\text{k}\Omega + 20\,\text{k}\Omega}
    = 3.33\,\text{V}
\]

Additional protection per line: 1\,nF bypass capacitor (noise filter)
and a TVS diode (ESD).  Ferrite beads (600\,\(\Omega\) at 100\,MHz)
isolate encoder VCC feeds.

\subsection{Pin Map}

\renewcommand{\arraystretch}{1.3}
\begin{table}[h]
\centering
\caption{ESP32 GPIO assignments.}
\label{tab:pins}
\begin{tabularx}{\textwidth}{@{}lcX@{}}
\toprule
\textbf{Signal} & \textbf{GPIO} & \textbf{Notes} \\
\midrule
Theta A  & 32 & ADC1\_CH4; interrupt-capable. \\
Theta B  & 35 & Input-only; interrupt-capable. \\
Phi A    & 14 & Interrupt-capable. \\
Phi B    & 12 & Strapping pin --- requires external pull-down. \\
Wire A   & 16 & Draw-wire quadrature A. \\
Wire B   & 17 & Draw-wire quadrature B. \\
Battery  & 36 & ADC1\_CH0; 100\,k\(\Omega\)+100\,k\(\Omega\) divider. \\
\bottomrule
\end{tabularx}
\end{table}

\subsection{Power System}

Two sources are OR-ed via Schottky diodes:

\begin{itemize}[noitemsep, topsep=4pt]
  \item \textbf{External 5\,V} via barrel jack with SI2301 P-MOSFET
        reverse-polarity protection.
  \item \textbf{LiPo cell} charged by TP4056+DW01A, boosted to 5.3\,V
        by MT3608 (compensates Schottky forward-voltage drop).
\end{itemize}

% ==================================================================
\section{Software Design}
\label{sec:sw}

\subsection{Firmware Modules}

The firmware is written in C\texttt{++} (PlatformIO / Arduino ESP32
framework) and split into three modules:

\begin{itemize}[noitemsep, topsep=4pt]
  \item \texttt{EvkaPosition.cpp} --- \texttt{setup()} and
        \texttt{loop()} at 20\,Hz (50\,ms period).
  \item \texttt{SphericalSensor.h/.cpp} --- constants, data structures,
        coordinate math, EMA filter, and range validation.
  \item \texttt{WebDashboard.h/.cpp} --- WiFi AP and WebSocket server
        (compile-gated by \texttt{ENABLE\_WIFI}).
\end{itemize}

Encoder objects are heap-allocated inside \texttt{begin()} because
the ESP32 GPIO ISR infrastructure is not ready during global
construction.

\subsection{Coordinate Mathematics}

Counts are offset by the zero-point snapshot, then converted:

\begin{align}
  \theta &= \bigl(\text{counts}_\theta - \text{offset}_\theta\bigr)
             \times \tfrac{360^\circ}{20\,000} \label{eq:theta}\\[3pt]
  \phi   &= \bigl(\text{counts}_\phi - \text{offset}_\phi\bigr)
             \times \tfrac{360^\circ}{20\,000} \label{eq:phi}\\[3pt]
  r      &= \bigl(\text{counts}_r - \text{offset}_r\bigr)
             \times \tfrac{200\;\text{mm}}{8\,020} \label{eq:r}
\end{align}

The Cartesian output from Eqs.~(\ref{eq:x})--(\ref{eq:z}) is then
smoothed per axis by the EMA filter (Eq.~\ref{eq:ema}):

\begin{equation}
  \hat{x}_n = \alpha \cdot x_n + (1 - \alpha) \cdot \hat{x}_{n-1},
  \qquad \alpha = 0.2
  \label{eq:ema}
\end{equation}

\subsection{Communication Architecture}

Figure~\ref{fig:comms} shows all communication interfaces.

\begin{figure}[h]
\centering
\begin{tikzpicture}[
  mcu/.style={
    rectangle, rounded corners=6pt,
    minimum width=3.0cm, minimum height=3.6cm,
    fill=sectionblue!15, draw=sectionblue, line width=1.2pt,
    align=center, font=\small\bfseries
  },
  ext/.style={
    rectangle, rounded corners=4pt,
    minimum width=2.8cm, minimum height=0.9cm,
    align=center, fill=boxblue, draw=sectionblue, line width=0.7pt,
    font=\small
  },
  enc/.style={
    rectangle, rounded corners=4pt,
    minimum width=2.8cm, minimum height=0.75cm,
    align=center, fill=boxgreen, draw=green!50!black, line width=0.7pt,
    font=\footnotesize
  },
  arr/.style={-{Stealth[length=6pt]}, line width=1.1pt},
  biarr/.style={{Stealth[length=6pt]}-{Stealth[length=6pt]}, line width=1.1pt}
]
  % Central MCU
  \node[mcu] (mcu) {ESP32\\WROOM-32\\[6pt]20\,Hz loop};

  % Encoders on the left
  \node[enc, left=2.2cm of mcu, yshift= 1.1cm] (etheta) {Theta Encoder\\(E40S6, GPIO 32/35)};
  \node[enc, left=2.2cm of mcu, yshift= 0.0cm] (ephi)   {Phi Encoder\\(E40S6, GPIO 14/12)};
  \node[enc, left=2.2cm of mcu, yshift=-1.1cm] (ewire)  {Draw-Wire Enc.\\(DWE3000, GPIO 16/17)};

  % Interfaces on the right
  \node[ext, right=2.2cm of mcu, yshift= 1.2cm] (serial) {Serial Monitor\\115200\,baud};
  \node[ext, right=2.2cm of mcu, yshift= 0.0cm] (wifi)   {WiFi AP\\192.168.4.1};
  \node[ext, right=2.2cm of mcu, yshift=-1.2cm] (python) {Python GUI\\PyQtGraph 3D};

  % Encoder → MCU arrows (quadrature pulses)
  \draw[arr, color=green!50!black]
        (etheta.east) -- node[above, font=\scriptsize]{quadrature} (mcu.west |- etheta);
  \draw[arr, color=green!50!black]
        (ephi.east)   -- (mcu.west |- ephi);
  \draw[arr, color=green!50!black]
        (ewire.east)  -- (mcu.west |- ewire);

  % MCU → Serial
  \draw[arr, color=sectionblue]
        (mcu.east |- serial) -- node[above, font=\scriptsize]{DATA,x,y,z} (serial.west);

  % MCU ↔ WiFi (bidirectional: commands + data)
  \draw[biarr, color=sectionblue]
        (mcu.east |- wifi) -- node[above, font=\scriptsize]{WebSocket} (wifi.west);

  % Serial → Python
  \draw[arr, color=gray!60]
        (serial.south) -- (python.north);

  % Labels
  \node[font=\scriptsize\itshape, text=gray, below=0.18cm of etheta.south west, anchor=north west]
        {5\,V TTL → 3.3\,V dividers};
\end{tikzpicture}
\caption{Communication architecture.  Encoder signals flow into the ESP32 via
voltage dividers.  Processed position data exits over USB serial (also consumed
by the Python GUI) and optionally over WebSocket to a WiFi-connected browser.}
\label{fig:comms}
\end{figure}

\subsection{Serial Protocol}

Commands are newline-terminated ASCII strings at 115200\,baud:

\renewcommand{\arraystretch}{1.3}
\begin{table}[h]
\centering
\caption{Serial command interface.}
\label{tab:serial}
\begin{tabularx}{\textwidth}{@{}llX@{}}
\toprule
\textbf{Command} & \textbf{Response} & \textbf{Action} \\
\midrule
\texttt{ZERO}   & \texttt{ACK:ZERO}   & Snapshot current counts as new
                                         zero-point; all positions become
                                         relative to this instant. \\
\texttt{PING}   & \texttt{ACK:PONG}   & Connectivity check. \\
\texttt{STATUS} & \texttt{STATUS,...} & Comma-separated frame: validity,
                                         frame count, timestamp,
                                         \(r/\theta/\phi\), \(X/Y/Z\). \\
\bottomrule
\end{tabularx}
\end{table}

The firmware also emits unsolicited \texttt{DATA,x,y,z,...} lines at
20\,Hz for the Python visualiser.

\subsection{WiFi Dashboard}

When \texttt{ENABLE\_WIFI=1}, \texttt{setup()} creates a WPA2 access
point (\texttt{EvkaPosition}) and starts a WebSocket server on port~80.
Browsers at \texttt{192.168.4.1} receive live position frames at 20\,Hz.

% ==================================================================
\section{Calibration}
\label{sec:cal}

\subsection{Zero-Point Procedure}

On power-up the firmware waits 2\,s, then calls \texttt{setZeroPoint()},
which records the current encoder counts as reference offsets.  The
robot \textit{must} be at mechanical home (wire retracted, angles at
reference marks) at this moment.  The \texttt{ZERO} serial command
re-takes the snapshot at any time without reflashing.

\subsection{PPR Calibration}

The nominal DWE3000 base PPR is 2000.  With X4 decoding and a 200\,mm
drum, the initial scaling was:

\[
  \text{MM\_PER\_PULSE}_\text{nom}
    = \frac{200\;\text{mm}}{2000 \times 4}
    = 0.025\;\text{mm/count}
\]

A known 400\,mm extension read as 1604\,mm --- a factor of $\sim$4.01
error.  The corrected base PPR is:

\begin{equation}
  \text{PPR\_WIRE}_\text{cal}
    = 2000 \times \frac{1604}{400}
    = 8020
  \label{eq:ppr}
\end{equation}

giving the corrected scaling:

\[
  \text{MM\_PER\_PULSE}_\text{cal}
    = \frac{200\;\text{mm}}{8020}
    \approx 0.02494\;\text{mm/count}
\]

Rotary PPR is verified by commanding ten full turns and confirming
\(10 \times 4 \times 5000 = 200\,000\) counts.  All runs are logged to
CSV templates in \texttt{docs/calibration/templates/}.

% ==================================================================
\section{Results}
\label{sec:results}

\subsection{Resolution and Accuracy}

\renewcommand{\arraystretch}{1.3}
\begin{table}[h]
\centering
\caption{Theoretical resolution and positional error at 5\,m range.}
\label{tab:accuracy}
\begin{tabular}{@{}llll@{}}
\toprule
\textbf{Axis} & \textbf{Sensor} & \textbf{Resolution} &
  \textbf{Error at 5\,m} \\
\midrule
\(\theta\) & E40S6   & \(0.018^\circ\)       & \(\approx 1.57\)\,mm arc \\
\(\phi\)   & E40S6   & \(0.018^\circ\)       & \(\approx 1.57\)\,mm arc \\
\(r\)      & DWE3000 & \(\pm 0.025\)\,mm     & \(\pm 0.025\)\,mm        \\
\textbf{Total} & ---  & ---                   & \(\approx \pm 3.2\)\,mm  \\
\bottomrule
\end{tabular}
\end{table}

At the primary 3\,m workspace, the angular error contribution drops to
\(\approx \pm 0.94\)\,mm, making the total error comfortably better
than \(\pm 2\)\,mm.

\subsection{Update Rate and Visualisation}

The main loop runs at 20\,Hz (50\,ms, set by
\texttt{UPDATE\_PERIOD\_MS}).  The companion Python tool at
\texttt{tools/position\_checker/gui.py} renders a live 3D trajectory
using PyQtGraph \texttt{GLViewWidget} at 30--60\,FPS over serial.

% ==================================================================
\section{Conclusion}
\label{sec:conclusion}

A self-contained 3D position tracking system was built from commodity
industrial encoders and an ESP32 microcontroller.  The spherical
coordinate approach reduces mechanical complexity to three single-axis
sensors.  A systematic PPR calibration corrected a factor-of-four
draw-wire error, bringing radial accuracy to within 1\,mm.  The system
delivers \(\pm 3.2\)\,mm worst-case accuracy at 5\,m range at 20\,Hz,
with an optional WiFi dashboard and a real-time Python 3D visualiser.

\subsection*{Future Work}

\begin{itemize}[noitemsep, topsep=4pt]
  \item Full three-encoder hardware integration test on the assembled
        mechanism.
  \item Custom PCB fabrication (design complete; 120\(\times\)80\,mm
        pertinax layout, assembly pending).
  \item Dynamic accuracy validation using a laser distance meter as
        ground truth.
  \item Extended Kalman filter fusing encoder data with an IMU for
        improved dynamic tracking.
\end{itemize}

\end{document}

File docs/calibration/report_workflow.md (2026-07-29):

# Calibration Report Workflow

Operator guide for the systematic endpoint (Kabsch) calibration and validation report.

> **Current status:** this workflow produces candidate transforms. Theta count loss is unresolved,
> there is no accepted endpoint/world transform, and no shared/default calibration JSON is checked
> in. `tools/evka_gui` remains sensor-frame-only.

```bash
# From the repo root
python -m tools.calibration.report
```

This is the preferred path for Stages 5-6 of [calibration_guide.md](calibration_guide.md).
It does **not** change firmware — you collect real-world reference points, put them in CSV
files, then the tool fits a candidate sensor-to-world transform and writes a Markdown report.

Full tool notes: [tools/calibration/README.md](../../tools/calibration/README.md).
Session folder layout: [sessions/README.md](sessions/README.md).

---

## 1. Purpose and prerequisites

Endpoint calibration computes a rigid-body transform that maps **sensor XYZ** into your
**machine/world** frame:

```text
world = R @ sensor + t
```

| Requirement | Detail |
|---|---|
| Mechanical repeatability | Theta/phi/radius must return repeatably; Kabsch cannot correct count loss, slip, or backlash. |
| Encoder PPR done | Complete Stages 1–4 first (wire, theta, phi, apply constants). This stage corrects frame tilt/offset, not encoder scale. |
| Calibration points | At least **3** (tool minimum); recommend **8+**, well spread in X/Y/Z |
| Validation points | At least **1** (tool minimum); recommend **3–5** hold-outs not used in the fit |
| Geometry | Calibration set must span **≥ 2 directions** (not collinear or coincident) |

---

## 2. Quick start

Default session directory: `docs/calibration/sessions/current/`.

### Standalone app (normal path)

```bash
python -m tools.calibration.gui --tcp 192.168.1.84:8080     # or --serial /dev/ttyUSB0, --ws HOST
```

One full-screen window: connection, live position, and tabs for Wire / Theta / Phi /
**Endpoint** / Points / Commands. On the Endpoint tab: collect pairs (**Use Current Sensor
XYZ** grabs the live reading), set **Add to: Calibration / Validation** per point,
**Generate report**, and read the verdict and per-point residuals. Keep the generated JSON in its
session directory; optional legacy visualization is described in
[Section 6](#6-optional-explicit-legacy-transform).

It has no software zero — captured coordinates are always the raw sensor frame.

### Inside evka_gui

`python -m tools.evka_gui` → toolbar **Calibration…** → **Endpoint** tab has the same
endpoint workflow, if you are already in the telemetry GUI.

Both read and write the two session CSVs directly and call the same `generate_report()` as
the CLI, so all three always agree. No terminal step, and no device connection is needed
once the points are in.

### CLI (two-run workflow)

**First run** — creates empty CSV templates if they are missing:

```bash
python -m tools.calibration.report
```

You should see something like:

```text
Input templates are ready in: .../docs/calibration/sessions/current
Fill `calibration_points.csv` and `validation_points.csv`, then run:
python -m tools.calibration.report
```

**Fill the CSVs** (see [CSV format](#4-csv-format) below), then **run again**:

```bash
python -m tools.calibration.report
```

On success the tool writes `report.md`, `calibration.json`, and the per-point error CSVs
into the same session folder. See
[optional explicit legacy transform](#6-optional-explicit-legacy-transform).

---

## 3. Collecting measurement pairs

For each point: move the probe to a known world position `(world_x, world_y, world_z)` and
record the sensor Cartesian output `(sensor_x, sensor_y, sensor_z)`.

**Recommended layout (calibration set):**
- 3–4 points along +X (e.g. 100, 200, 400, 600 mm)
- 3–4 points along +Y
- 1–2 points along +Z or otherwise off-plane
- Include the world origin when practical

### Collection paths

| Source | How | CSV compatibility |
|---|-----|---|
| **Calibration app** | `python -m tools.calibration.gui` → Endpoint tab → enter world XYZ, **Use Current Sensor XYZ**, pick the set, **Add pair** | Writes both session CSVs directly — no split step |
| **evka_gui** | Toolbar **Calibration…** → Endpoint tab → same as above | Writes both session CSVs directly — no split step |
| **Web dashboard** | Connect to AP `CMDCNC_EVKA` → `http://192.168.1.50` → **CALIBRATE → ENDPOINT** → SET ORIGIN → RECORD POINT → EXPORT CSV | Header has `label` + 6 coords (no `notes`) — loads as-is, or use the GUI's **Import CSV** |
| **Serial** | Move probe, send `STATUS`, copy last three fields as sensor XYZ into the session CSVs | Manual entry |

`STATUS` reply format:

```text
STATUS,<is_valid>,<frame_count>,<ts_ms>,<r>,<theta>,<phi>,<x>,<y>,<z>
```

Use the last three fields as `sensor_x`, `sensor_y`, `sensor_z`.

### Splitting into calibration vs validation

The split is an operator decision: the **fit** set goes to `calibration_points.csv`, and
**hold-out** points not used in the fit go to `validation_points.csv`.

In either GUI, choose the set in the **Add to** dropdown when adding a point, or change a
row's **Set** dropdown afterwards — the CSVs are rewritten on every change. By hand, edit
the two files directly.

Optional **repeatability**: in the validation set, measure the same world point more than
once and reuse the **same label** with the **same world coordinates**. The report then
computes per-label standard deviation and spread. If the same label is reused for
*different* world points, that label is skipped and a warning is written into `report.md`.

---

## 4. CSV format

**Required columns** (only these six are mandatory):

```text
world_x, world_y, world_z, sensor_x, sensor_y, sensor_z
```

**Optional columns:** `label`, `notes`.

Full header (matches the templates the tool creates):

```csv
label,world_x,world_y,world_z,sensor_x,sensor_y,sensor_z,notes
```

Example rows:

```csv
label,world_x,world_y,world_z,sensor_x,sensor_y,sensor_z,notes
P0,0,0,0,1106.28,25.38,-160.68,origin
PX,100,0,0,1205.10,24.90,-161.20,
PY,0,100,0,1107.00,125.50,-160.40,
```

Blank lines are skipped. Non-numeric coordinates raise an error that names the physical
CSV line number.

---

## 5. Outputs and pass criteria

After a successful run, the session folder contains:

| File | Purpose |
|---|---|
| `report.md` | Human-readable summary: transform, RMSE, per-point errors, PASS/FAIL |
| `calibration.json` | Candidate transform `{R, t, rmse_mm, n_points}` for review and optional explicit legacy use |
| `calibration_errors.csv` | Per-point calibration residuals |
| `validation_errors.csv` | Per-point validation residuals |

**Pass criteria** (printed in the report Thresholds table):

| Check | Limit |
|---|---:|
| Calibration RMSE | ≤ 10.0 mm |
| Validation max error | ≤ 15.0 mm |

Both must PASS before you use the session JSON or consider accepting the transform.

**Error sign convention:** in the report tables and error CSVs,

```text
dX / dY / dZ = computed − world
```

Positive means the transformed sensor reading overshoots the known world coordinate.
`error_mm` is the Euclidean norm of that delta.

If calibration uses fewer than 8 points, `report.md` includes a warning — still usable for
bench checks, but prefer 8+ for a final field report.

---

## 6. Optional Explicit Legacy Transform

The session `calibration.json` stays in the session directory. There is no checked-in shared/default
file and no tool auto-loads one. After **both** Calibration and Validation show **PASS**, the legacy
visualizer can inspect that session transform only when the path is supplied explicitly:

```bash
python -m tools.position_checker.main --legacy-visualizer --port /dev/ttyUSB0 \
  --calibration docs/calibration/sessions/current/calibration.json
```

Without `--calibration PATH`, it remains in the sensor frame; a JSON with a non-`PASS` verdict is
rejected. Passing and viewing a transform do not by themselves create project acceptance.

`tools/evka_gui` is not a transform consumer. It records, plots, and solves IPT in the sensor frame.
The currently named **Deploy calibration.json** GUI action is legacy source behavior. The report CLI
prints only an explicit legacy-visualizer invocation; neither path changes the canonical GUI frame.

---

## 7. Session archiving

Before starting a new calibration session:

1. Copy the working folder to a dated archive, for example:

   ```bash
   cp -r docs/calibration/sessions/current \
         docs/calibration/sessions/2026-07-16_operator
   ```

2. Clear or replace the point rows in `current/calibration_points.csv` and
   `current/validation_points.csv` (keep the header).
3. Attach the archived `report.md` (and optionally the error CSVs) to the final calibration
   record — see [templates/final_calibration_record_template.md](templates/final_calibration_record_template.md).

Generated artifacts (`report.md`, `calibration.json`, `*_errors.csv`) are git-ignored under
`sessions/`; archive or attach them outside git if you need a durable paper trail.

---

## 8. Troubleshooting

| Symptom | Cause / fix |
|---|---|
| `Input templates are ready…` | CSVs are empty (header only). Add rows and rerun. |
| `need at least 3 calibration points` | Too few fit points in `calibration_points.csv`. |
| `need at least 1 validation point` | Add at least one hold-out row to `validation_points.csv`. |
| `collinear or coincident` | Spread calibration points in at least two directions (not a single line). |
| `missing columns: …` | CSV is missing one of the six required coordinate headers. |
| `row N has non-numeric coordinates` | Bad cell; `N` is the physical line number (blank lines counted). |
| Calibration **FAIL** (RMSE > 10 mm) | Re-check Stages 1–4; re-measure outliers; avoid collinear sets. |
| Validation **FAIL** (max > 15 mm) | Hold-outs disagree with the fit - re-measure; do not copy or accept. |
| Repeatability warning in report | Same `label` used for different world points — use unique labels or identical world coords for repeats. |
| High residuals after copy | Confirm the session passed and re-check mechanics, scale, labels, and hold-outs. |

---

## 9. Legacy alternative

For a one-off fit without validation CSVs, you can still edit embedded arrays in
`tools/calibration/calibrate.py` and run:

```bash
python -m tools.calibration.calibrate
python -m tools.calibration.calibrate --out /tmp/evka_candidate_calibration.json
```

That path writes (or can write) `calibration.json` directly and does **not** produce
`report.md` or a hold-out validation table. Prefer the report workflow for field sessions
and an auditable PASS/FAIL record. Do not use quick-fit output as a passing session transform.

---

## 10. Tests

```bash
pytest tools/calibration/tests/test_report.py -q
```

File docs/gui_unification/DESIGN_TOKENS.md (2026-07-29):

# EVKA Operator UI — Design Tokens & Action Vocabulary

The two operator UIs — the PyQt5 desktop (`tools/evka_gui/`) and the firmware web
dashboard (`firmware/src/WebDashboard.cpp`) — are used roughly equally, often by the
same person in the same session. They must read as one product.

Qt cannot render HTML components, so **nothing below is shared code**. What is shared
is the spec: the colour roles, the type/spacing scale, and one canonical name per
action. Each UI implements them natively.

> Source of truth for this doc is the doc itself. When a UI disagrees with it, the UI
> is wrong. New UI must be built against it; existing UI is retrofitted in Phase 3.

---

## 1. Colour roles

The web already had a coherent HUD palette. The desktop was a hybrid — Flat-UI colours
(`#27ae60`, `#c0392b`, `#f39c12`, `#2980b9`) fighting HUD colours (`#00ff88`, `#ff4444`)
inside the same window. **The HUD palette wins**: it is what the field operator sees on
the phone, and it is the one that was internally consistent.

| Role | Hex | Use | Replaces on desktop |
|---|---|---|---|
| `ok` | `#00ff88` | Success, connected, live, go-actions (ARM, CONNECT, APPLY) | `#27ae60` |
| `danger` | `#ff4444` | Destructive + hardware-affecting (ZERO (HW), CLEAR, DISCONNECT, DELETE) | `#c0392b` |
| `warn` | `#ffd700` | Caution, marginal fit, frozen, reconnecting, RAM-only state | `#f39c12`, `#e67e22` |
| `accent` | `#00ffff` | Headings, live values, focus, the primary read-out | `#00bcd4` |
| `info` | `#4488ff` | Neutral emphasis, Z axis, links | `#2980b9` |
| `ipt` | `#00ff88` | IPT capture cloud (same green as `ok`) | — |
| `ipt-target` | `#ff8c00` | The solved IPT point P + its sphere | `#ff6600` |
| `muted` | `#8899aa` | Secondary labels, hints, units | `#7f8c8d`, `#aaaaaa` |
| `text` | `#eef` | Primary text | `#e0e0e0` |
| `bg-deep` | `#0a0a1a` | Inputs, wells, recessed surfaces | — |
| `bg-canvas` | `#0f0f23` | 3D / plot backgrounds | — |
| `bg-panel` | `#1a1a2e` | Panel + window chrome | — |
| `border` | `#2a3550` | Dividers, card edges | — |

Axis colours are **not** themeable — they are a physical convention and already agree:
X `#ff4444`, Y `#00ff88`, Z `#4488ff`.

## 2. Type & spacing

- **Monospace everywhere for numbers.** A position that shifts width as it counts is
  unreadable. Both UIs already do this; keep it.
- Type scale: `10 / 12 / 14 / 16 / 20 / 28 px`. 16 px is the floor for any web
  `<input>` — below that, iOS Safari zooms the page on focus.
- Spacing scale: `4 / 8 / 12 / 16 / 24 px`.
- **Touch targets ≥ 44 px** on the web (the dashboard is used on a phone). The desktop
  may go smaller; it has a mouse.

## 3. Action vocabulary — one name per action

Same action, same name, both UIs. The table fixes three real defects:

1. The desktop shipped **raw protocol tokens as button labels** (`SAVE_POINT`,
   `DEL_POINT`). The wire format is not operator-facing language.
2. The web called the same concept **two different things** — `SAVE ORIGIN` in the
   session panel, `SET ORIGIN` in the endpoint calibration tab.
3. A bare **`CLEAR`** appeared in the web's CONTROL block meaning "clear the trail",
   colliding with `CLEAR` elsewhere meaning "clear the table".

| Action | Canonical label | Role | Was (web) | Was (desktop) |
|---|---|---|---|---|
| Re-zero all encoders (firmware `ZERO`) | `ZERO (HW)` | danger | `ZERO (HW)` | `Hardware ZERO` |
| Zero the client-side display offsets | `ZERO (SW)` | warn | `ZERO (SW)` | `Software Zero (All)` |
| Drop those offsets | `CLEAR SW ZERO` | muted | `CLEAR` (ambiguous) | `Clear SW Zero` |
| Store a point on the device | `SAVE POINT` | ok | `SAVE POINT` | `SAVE_POINT` ✗ |
| Remove the last stored point | `DEL LAST POINT` | danger | `DEL LAST POINT` | `DEL_POINT` ✗ |
| Mark the session origin | `SET ORIGIN` | ok | `SAVE ORIGIN` / `SET ORIGIN` ✗ | `Set Origin` |
| Forget the session origin | `CLEAR ORIGIN` | muted | — | `Clear Origin` |
| Empty the 3D trail | `CLEAR TRAIL` | muted | `CLEAR` (ambiguous) ✗ | `Clear Trail` |
| Reset per-axis extremes | `RESET MIN/MAX` | muted | `RESET MIN/MAX` | `Reset Min/Max` |
| Capture a manual point | `CAPTURE SNAPSHOT` | ok | `CAPTURE` | `Capture Snapshot` |
| Pause the position stream | `FREEZE` | warn | `FREEZE` | `Freeze` |
| Flash the status LED | `BLINK LED` | info | `BLINK LED` | `Blink LED` |
| Apply calibration to RAM | `APPLY (RAM)` | warn | `APPLY (RAM)` | `APPLY (RAM)` |
| Apply + persist to flash | `APPLY + SAVE (NVS)` | ok | `APPLY + SAVE (NVS)` | `APPLY + SAVE (NVS)` |
| Begin an IPT sweep | `ARM` | ok | *(new)* | `ARM` |
| End the sweep | `STOP` | warn | *(new)* | `STOP` |
| Fit the hidden point | `SOLVE` | accent | *(new)* | `SOLVE` |
| Start writing the stream to file | `RECORD` | danger | *(new)* | *(new)* |

**Casing rule.** Action buttons — commands aimed at the machine — are `ALL CAPS` in
both UIs. Window chrome, menus and toolbar entries keep each platform's idiom: Title
Case with an ellipsis on the desktop (`Calibration…`), all-caps in the web's HUD header.
Unifying the *chrome* would make the desktop feel like a kiosk; unifying the *actions*
is what lets an operator move between the two without re-learning.

## 4. State colour semantics

Both UIs signal connection and data state constantly. Same state, same colour:

| State | Colour |
|---|---|
| Connected / live | `ok` |
| Frozen, reconnecting, RAM-only calibration, marginal fit | `warn` |
| Disconnected, invalid frame, rejected fit | `danger` |
| Idle / never connected | `muted` |

An invalid frame (`is_valid == 0`) turns the X/Y/Z read-outs `danger` in both UIs
already. Keep that — it is the single most important state on the screen.

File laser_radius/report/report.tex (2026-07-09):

\documentclass[11pt]{article}

\usepackage[a4paper,margin=2.5cm]{geometry}
\usepackage{amsmath}
\usepackage{graphicx}
\usepackage{booktabs}
\usepackage{array}
\usepackage{xcolor}
\usepackage{tikz}
\usepackage{hyperref}
\usepackage{enumitem}
\usepackage{fancyhdr}
\usetikzlibrary{arrows.meta, positioning}

\hypersetup{colorlinks=true, linkcolor=blue, urlcolor=blue, citecolor=blue}
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

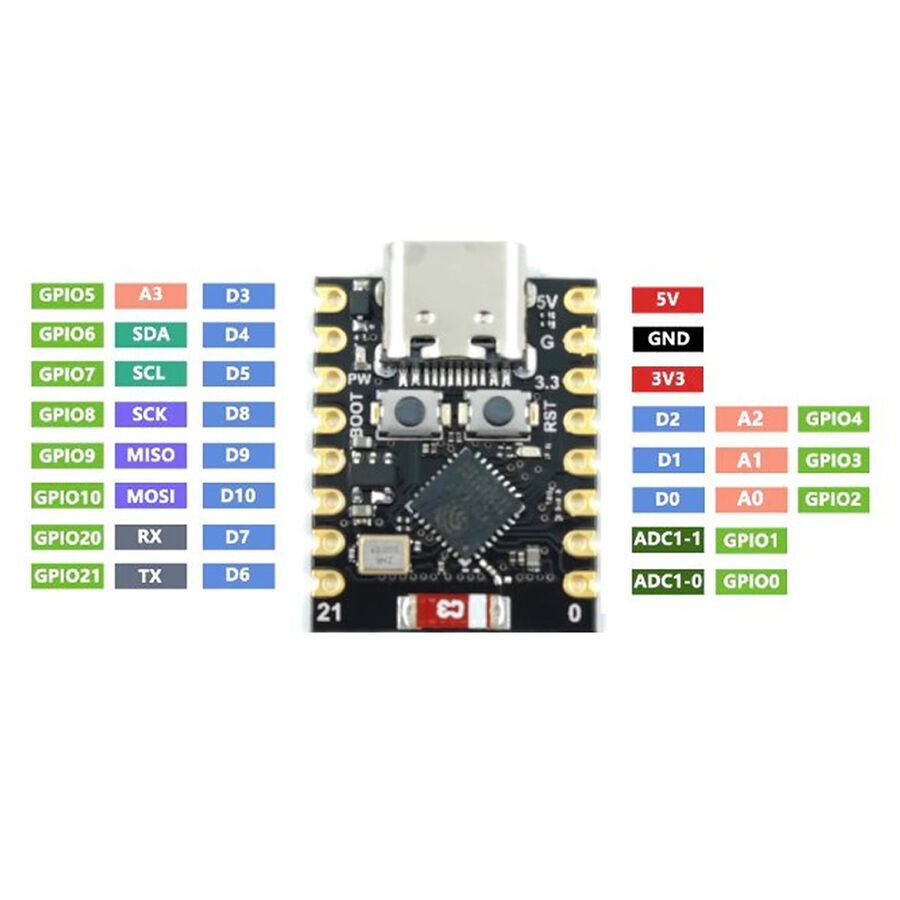
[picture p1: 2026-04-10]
docs/hardware_design/remote/esp32-c3-mini-boardScematic.jpg

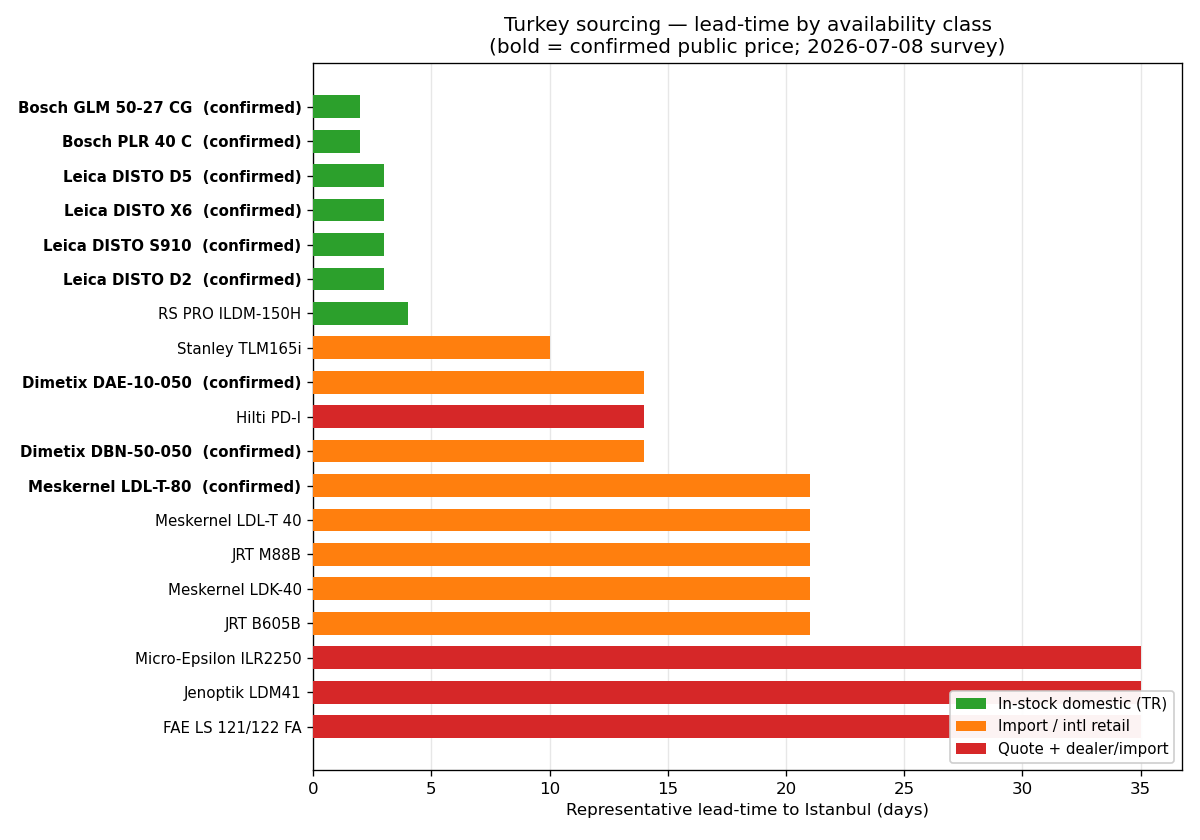
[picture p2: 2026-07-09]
laser_radius/report/figures/turkey_availability.png

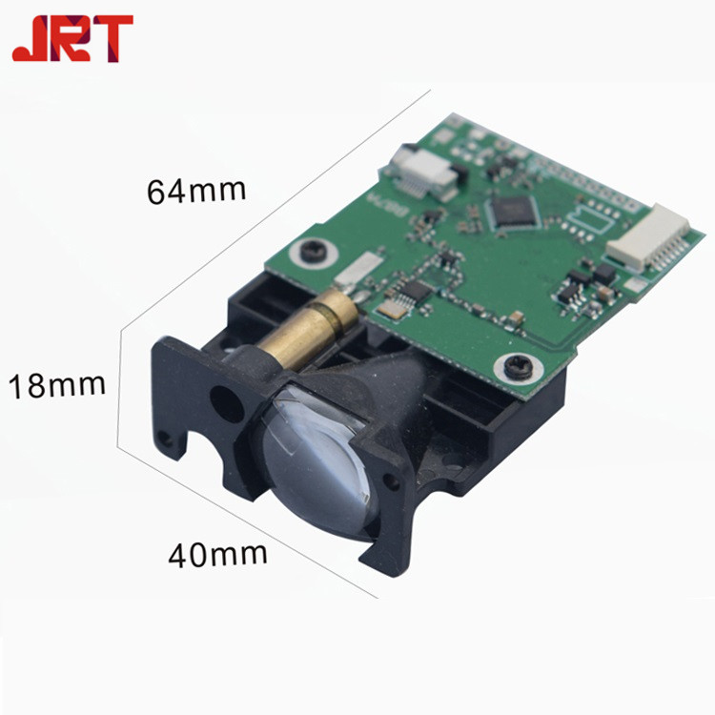
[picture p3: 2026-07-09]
laser_radius/report/images/jrt_b605b.jpg

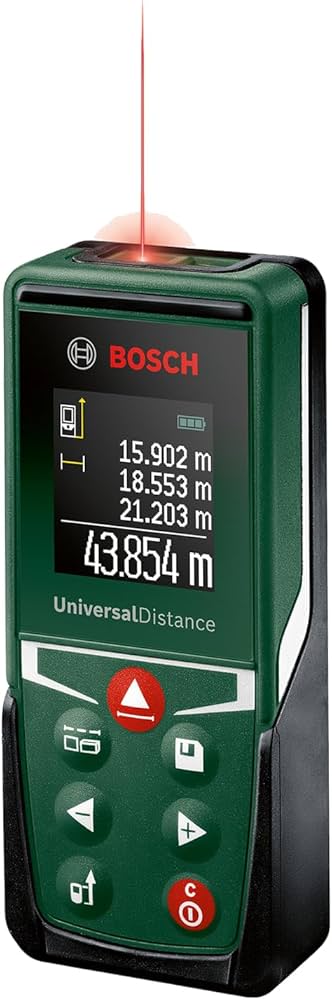
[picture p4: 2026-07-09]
laser_radius/report/images/bosch_plr40c.jpg

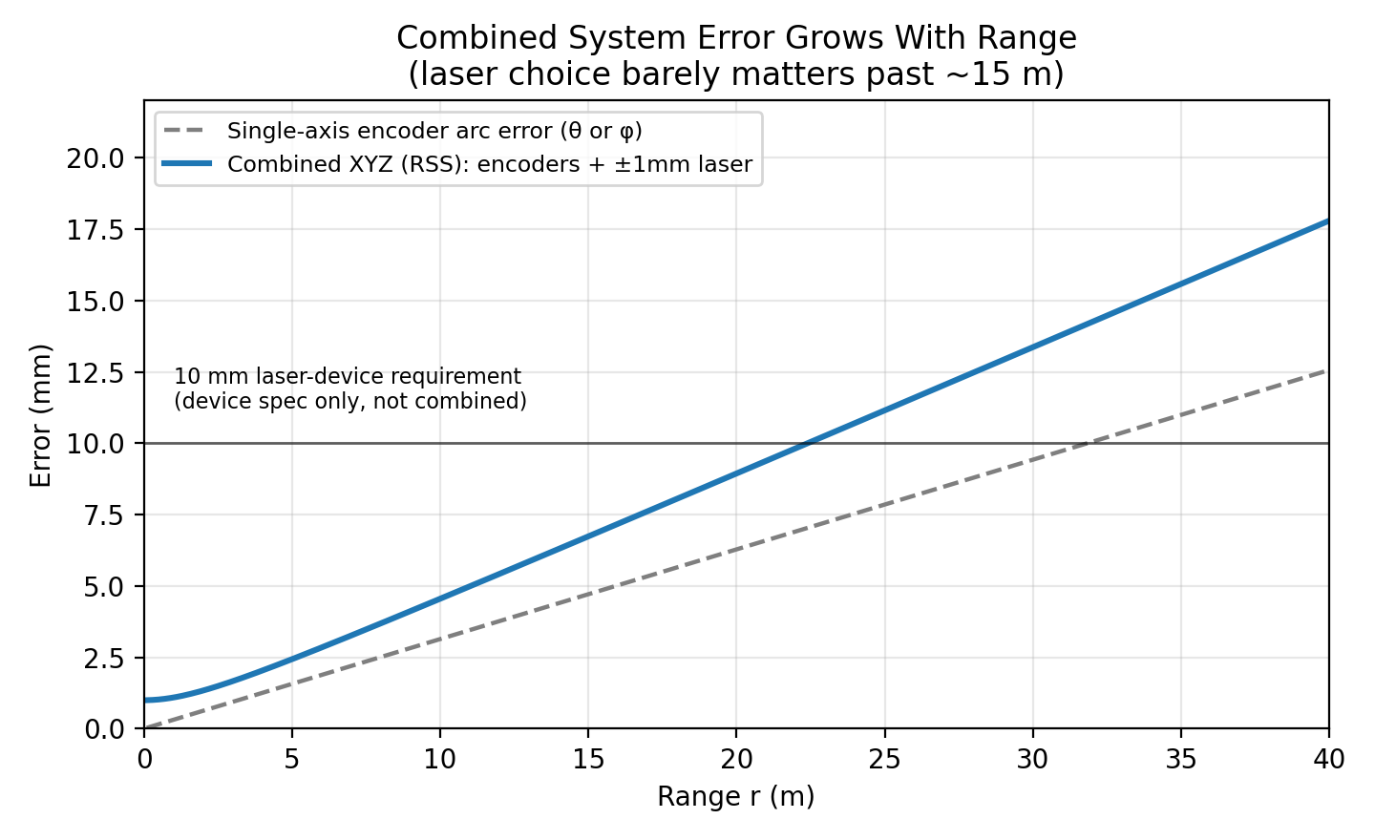
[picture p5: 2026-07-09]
laser_radius/report/figures/error_budget.png

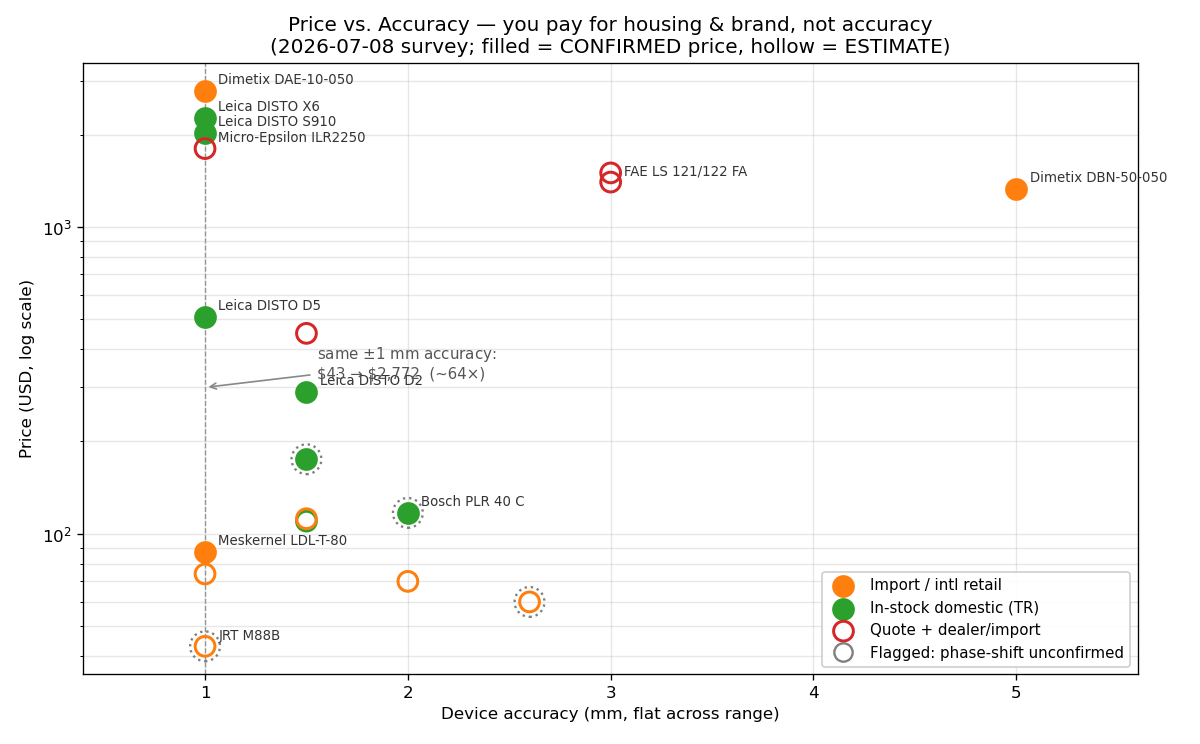
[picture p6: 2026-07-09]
laser_radius/report/figures/price_vs_accuracy.png

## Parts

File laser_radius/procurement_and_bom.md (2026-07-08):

# Procurement & Bench-Test BOM — Laser Radius Variant

**Parent doc:** [`README.md`](README.md). Rough costs, suppliers, and a recommended bench-test order sequence.

**Fixed requirement (2026-07-01, revised):** ≤40 m range, ≤10 mm laser accuracy — every device below meets this spec (the previously-considered ToF modules that don't are omitted; see `version_b_integrated_modules.md` §1 if that history is needed).

**2026-07-01 addendum:** extended research pass added 13 more candidates (8 handheld, 5 industrial) — see §1.1/§1.2 below.

**2026-07-08 price-survey addendum:** a targeted Istanbul price/model survey (two independent passes) converted many estimates into **CONFIRMED** prices/SKUs, added new models (Leica **X6**, Dimetix **DBN-50-050**, Meskernel **LDK-40**, JRT **M88B**, **FAE LS 121/122 FA**), and **demoted Bosch and JRT to a flagged tier** (measurement principle not independently confirmed — see `version_a_handheld_devices.md` §2.1/§2.3). FX used (2026-07-08): **USD/TRY 46.85, EUR/USD 1.141, CHF/USD 1.238, GBP/USD 1.336**. TL prices move with FX/VAT — treat as sensitive.

---

## 1. Cost & Supplier Summary

All prices are as retrieved during this research pass (2026-07-01) — **verify live pricing/stock before ordering**, especially TL prices (move with FX/VAT) and quote-only items.

### 1.1 Original Shortlist

| Device | Role | Price | Supplier | Lead time class |
|---|---|---|---|---|
| **Meskernel LDL-T** | **Confirmed-phase-shift lead** — cheapest device with principle + price both confirmed | **LDL-T-80: ~$87.50 / ~4,097 TRY (CONFIRMED)**; LDL-T 40: ~$68–80 (est.); LDK-40: ~$70 (est.) | Alibaba/AliExpress/meskernel.net | Slow — import, 2–4 wk class |
| **Dimetix DBN-50-050** (P/N 500635) | Confirmed-protocol budget lead — ±5 mm, public ASCII spec | **CHF 1,076 / ~$1,332 (CONFIRMED)** | shop.dimetix.com; TR dealers Megasensor/Ulusat | Slow — EU order |
| **Dimetix DAE-10-050** (P/N 500633) | Industrial precise option — ±1 mm, public ASCII spec | **CHF 2,298–2,699 / ~$2,700–2,844 / ~126,394 TRY (CONFIRMED)** | shop.dimetix.com, Laser-View/Eurolase | Slow — EU order |
| **Leica DISTO D5** | Confirmed domestically-stocked handheld reference (±1 mm, BLE) | **~$311–708 / ~14,595–33,200 TRY (CONFIRMED, source spread)** | Amazon.com.tr / Optet Makina (Hepsiburada) | Fast–Medium — TR channel |
| JRT B605B / M88B ⚠flagged | Cheapest wired module — *phase-shift unconfirmed, verify first* | M88B: ~$43 / ~2,013 TRY (est.); B605B: $30–90 (est.) | jrt-measure.com, Alibaba, AliExpress | Slow — import, 2–4 wk |
| Bosch PLR 40 C ⚠flagged | Fast local BLE reference — *phase-shift unconfirmed, verify first* | ~3,865–4,275 TL (~$110–125, CONFIRMED price) | Hepsiburada, Trendyol, N11, Amazon.tr, Tekzen | Fast — domestic, multiple retailers |
| UNI-T LM50A | Reference tool only (not a candidate — no data interface) | Cheap, in stock | robotistan.com | Fast — domestic |

### 1.2 Extended Shortlist (2026-07-01 addendum)

**More handheld/BLE options** — full detail in `version_a_handheld_devices.md` §3:

| Device | Price | Supplier | Lead time class |
|---|---|---|---|
| RS PRO ILDM-150H (OEM: CEM iLDM-150) | **Cheapest BLE handheld found**: ~$90–130 (est.) | RS Components' Turkey branch (rsonline.com.tr); CEM-branded twin on Amazon/eBay/Newegg | Fast — domestic (RS TR) or Amazon |
| Stanley TLM165i / TLM165SI FatMax | ~$110–115 (est.) | Amazon EU/UK confirmed | Medium — international shipping |
| Leica DISTO D2 (986858 refresh / 838725) | **~$270–309 / ~14,500 TRY (CONFIRMED)** | Wide Amazon/EU retail; Leica TR dealer network | Fast–Medium |
| Bosch GLM 50-27 CG ⚠flagged | **$175 / 8,200 TRY (CONFIRMED price; principle unconfirmed)** | Same Bosch Professional TR channel as PLR 40 C | Fast — domestic |
| Bosch GLM 165-27 C/CG ⚠flagged | ~$200–250 (est.) | Amazon US/EU | Medium |
| ADA Cosmo 60 Green | Quote-only | CIS/Eastern Europe distribution | Slow — quote + import |
| Hilti PD-I | Est. $400–500 | Hilti direct-channel dealer network incl. Turkey | Medium — dealer order |
| **Leica DISTO X6** (SKU 950909) **[NEW]** | **~$2,263 / 106,000 TRY (CONFIRMED)** — rugged X-series flagship, 250 m | Trendyol TR / Leica dealer network | Medium — dealer/marketplace |
| Leica DISTO S910 (SKU 805080) | **~$1,916–2,132 / ~89,780–99,855 TRY (CONFIRMED)** — corrected up from earlier ~$900–1,200 est.; best accuracy/range/native-USB in Version A | Leica dealer network / TR channel stock | Medium — dealer order |

**More industrial/fixed-mount options** — full detail in `version_b_integrated_modules.md` §3:

| Device | Price | Supplier | Lead time class |
|---|---|---|---|
| Micro-Epsilon optoNCDT ILR2250 / ILR3800 | **ILR2250: ~$1,800 / ~84,294 TRY (ESTIMATE)**; ILR3800 quote-only | Micro-Epsilon direct (Germany); TR dealers İmaj Teknik, Simtekno | Slow — quote + EU import |
| **FAE LS 121 / LS 122 FA** **[NEW]** | **~$1,400 / ~65,562 TRY (ESTIMATE)** | FAE Srl (Italy); EU import (Customs-Union advantage) | Slow — quote + EU import |
| Jenoptik LDM41 / LDM4x series | **~$1,500 / ~70,245 TRY (ESTIMATE)** — 150 m range is reflector-dependent (~30 m natural) | Jenoptik direct (Germany); Edmund Optics | Slow — quote + EU import |
| WayCon LDI | Quote-only | WayCon Positionsmesstechnik direct (Germany) | Slow — quote + EU import |
| Scantron SLS | Quote-only | Scantron Industrial Products (UK) | Slow — quote + EU import |
| ~~Micro-Epsilon ILR1171/1181/1191~~ | **Rejected** — older branch is pulsed ToF (2026-07-08), not phase | — | — |

**MAX3232 (RS232) and MAX485/RS422 transceiver breakout modules** — needed depending on which device/interface is chosen (see `firmware_integration.md` §1) — are cheap (~$1–3 class), widely available on direnc.net/AliExpress, and not itemized per-device since they're shared infrastructure, not sensor cost.

## 2. Recommended Bench-Test Order

Revised 2026-07-08 to a **confirmed-phase-shift-first** ordering (the earlier draft led with Bosch/JRT, now flagged for unconfirmed measurement principle):

1. **Meskernel LDL-T** (~$68–87.50, import, 2–4 wk) — order first. Cheapest device with **both** a confirmed phase-shift principle and a confirmed street price; ±1 mm, 100 Hz native (exceeds the 20 Hz loop, no gap-filling). Request the command datasheet from Meskernel *before* ordering (its byte-level protocol is the one open gap). Bench-test both mounting styles (Version A dock / Version B panel) with the same unit.
2. **Dimetix DBN-50-050** (CHF 1,076 / ~$1,332, EU order) — order alongside step 1. It's the only candidate with a fully public ASCII protocol, so it de-risks the firmware parsing path independently of Meskernel's datasheet; ±5 mm still clears the ≤10 mm spec. Step up to **DAE-10-050** (±1 mm, ~$2,700) only if the tighter accuracy is wanted.
3. **Leica DISTO D5** (~$311–708, TR channel) — order for a confirmed, domestically-stocked ±1 mm handheld reference and to validate the BLE read path with a *confirmed-phase-shift* device (unlike the flagged Bosch).
4. **(Flagged — verify principle first) Bosch PLR 40 C + RS PRO ILDM-150H + JRT B605B/M88B** — cheap and fast/domestic (Bosch, RS PRO) or cheapest of all (JRT ~$43), but only worth ordering *after* a primary-source datasheet confirms their measurement principle is phase-shift. Until then, keep the Bosch as a hand reference only.
5. **(Conditional) Industrial tier — Micro-Epsilon ILR2250 (~$1,800), WayCon LDI, or FAE LS 121/122 FA (~$1,400)** — only if steps 1–3 fail to meet the ≤10 mm spec in real bench conditions (unlikely, given the margin) or if an IP rating / certified housing becomes a hard requirement. Request quotes in parallel rather than defaulting to one vendor.
6. **(Optional) Leica DISTO S910 or X4 + RS232 accessory** — only worth pursuing if the industrial-tier budget is available *and* a handheld/dockable form factor is preferred over the industrial candidates' fixed housings. Otherwise redundant with steps 1–5.

## Open Risks

1. **Bosch and JRT measurement principle is unconfirmed** — both are flagged (see the tables) and must not be treated as certified until a primary-source datasheet confirms phase-shift.
2. **Confirmed prices are FX-sensitive** — the CONFIRMED TL figures move with USD/TRY (46.85 as of 2026-07-08) and VAT; re-check before ordering.
3. **Import lead times (2–4 weeks) for Meskernel/JRT are estimates**, not confirmed shipping quotes.
4. ~~Dimetix SKU needs confirmation~~ **RESOLVED** — DAE-10-050 / DBN-50-050 confirmed. Only a TR shipping quote remains open.
5. **Still-estimated prices** — Micro-Epsilon ILR2250 (~$1,800), Jenoptik LDM41 (~$1,500), FAE LS 121/122 (~$1,400), Hilti, Stanley, RS PRO, ADA. WayCon and Scantron remain fully quote-only. Confirm before a hard budget.

## Next Physical Test Steps

1. Request the Meskernel LDL-T command datasheet, then place the Meskernel LDL-T and Dimetix DBN-50-050 orders — the two confirmed-phase-shift leads (one cheapest, one public-protocol).
2. Order a Leica DISTO D5 from the TR channel for a confirmed-phase-shift ±1 mm handheld reference and BLE-path validation.
3. Once a confirmed lead arrives, run the accuracy spot-check from `kinematics_and_calibration.md` §3.2 at 5 m / 20 m / 40 m before deciding whether an industrial-tier sensor is ever needed.
4. Obtain primary-source phase-shift confirmation for Bosch/JRT **before** ordering either for anything beyond a hand reference.
5. If the industrial tier does become necessary, request quotes from Micro-Epsilon, WayCon, and FAE in parallel — roughly comparable on paper; only a real quote reveals which is cheapest/fastest.

---

*Part of the [laser radius detailed study](README.md). Docs-only — no firmware or PCB changes.*

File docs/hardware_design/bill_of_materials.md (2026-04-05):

# Bill of Materials — evka_position Hardware Board

> Complete BOM for the double-sided pertinax PCB (120mm x 80mm).
> All components are through-hole unless noted.

---

## Resistors (1/4W, 1%, Metal Film, Through-Hole)

| Ref | Qty | Value | Purpose | Notes |
|-----|-----|---|---|---|
| R1-R7 | 7 | 10kΩ | Voltage dividers (top resistor) | Signal line 5V→3.3V conversion |
| R8-R14 | 7 | 20kΩ | Voltage dividers (bottom resistor) | Signal line 5V→3.3V conversion |
| R15-R16 | 2 | 100kΩ | Battery ADC voltage divider | GPIO 36, draws 21μA |
| R17-R18 | 2 | 1kΩ | LED current limiters | Green (power) + Red (battery low) |
| R19 | 1 | 100kΩ | SI2301 gate pull-down | Reverse polarity protection |

**Subtotal: 19 resistors**

---

## Capacitors

| Ref | Qty | Value | Type | Purpose | Notes |
|-----|-----|---|---|---|---|
| C1 | 1 | 220μF/10V | Electrolytic | 5V_RAIL bulk decoupling | Low ESR preferred |
| C2-C5 | 4 | 100nF | Ceramic (X7R) | Rail + encoder VCC decoupling | C2 at rail, C3-C5 at J1/J2/J3 |
| C6-C12 | 7 | 1nF | Ceramic (C0G/NP0) | Signal line RC filters | At divider junctions |
| C13 | 1 | 10μF/10V | Ceramic or electrolytic | MT3608 input decoupling | At VIN pad |

**Subtotal: 13 capacitors**

---

## Diodes

| Ref | Qty | Part Number | Package | Purpose | Key Specs |
|-----|-----|---|---|---|---|
| D1-D2 | 2 | SS34 | DO-214AB (SMA) or DO-201 | Schottky OR power switching | 3A, Vf ≈ 0.2V @ 400mA |
| D3 | 1 | 1N5817 | DO-41 (axial) | Auto-charge path (ext→TP4056) | 1A, Vf ≈ 0.45V |

**Subtotal: 3 diodes**

---

## Protection Components

| Ref | Qty | Part Number | Package | Purpose | Key Specs |
|-----|-----|---|---|---|---|
| TVS1-TVS7 | 7 | 1.5KE3.3CA | Axial (DO-201) | ESD protection on signal GPIOs | Bidirectional, clamp 3.3V |
| FB1-FB3 | 3 | TDK MPZ1608 or axial equiv. | Axial | EMI filter on encoder VCC | 600Ω @ 100MHz, <1Ω DC |
| Q1 | 1 | SI2301 | SOT-23 | Reverse polarity P-MOSFET | Vgs(th) -1.2V, Rds(on) 110mΩ |

**Subtotal: 11 protection components**

---

## Connectors

| Ref | Qty | Part Number | Pitch | Purpose |
|-----|-----|---|---|---|
| J1 | 1 | KF301-4P | 5.08mm | Theta encoder (E30S6 #1) |
| J2 | 1 | KF301-4P | 5.08mm | Phi encoder (E30S6 #2) |
| J3 | 1 | KF301-5P | 5.08mm | Wire encoder (DWE3000) |
| J4 | 1 | DC barrel jack 5.5×2.1mm or KF301-2P | — | External 5V power input |
| J5 | 1 | JST-PH 2-pin | 2.0mm | LiPo battery |
| J6 | 1 | KF128V-5.08-2P | 5.08mm | Direct 5V test input |
| U1 | 2 | Female header strip 1×15 or 1×19 | 2.54mm | ESP32 Wemos D1 R32 socket |

**Subtotal: 8 connector assemblies**

---

## Modules

| Ref | Qty | Module | Purpose | Notes |
|-----|-----|---|---|---|
| MOD1 | 1 | TP4056 with DW01A | LiPo charger + battery protection | PROG: 1.2kΩ (1A charge) |
| MOD2 | 1 | MT3608 boost converter | 3.7V LiPo → 5.3V boost | Adjust trim pot to 5.3V |

**Subtotal: 2 modules**

---

## LEDs

| Ref | Qty | Color | Size | Purpose | Drive |
|-----|-----|---|---|---|---|
| LED1 | 1 | Green | 3mm | Power indicator (5V_RAIL on) | 5V_RAIL → 1kΩ → LED → GND |
| LED2 | 1 | Red | 3mm | Battery low warning | GPIO 25 → 1kΩ → LED → GND |

**Subtotal: 2 LEDs**

---

## Mechanical / Misc

| Qty | Item | Purpose |
|-----|---|---|
| 1 | Tactile push-button 6mm | Reset button (ESP32 RST → GND) |
| 5+ | Test point pins (gold-plated) | TP1-TP5 (5V, 3.3V, MT3608, BAT, GND) |
| 1 | Double-sided pertinax board 120×80mm | PCB substrate |
| — | 0.8mm tinned copper wire | Via links (top↔bottom layer connections) |
| — | Hook-up wire (22AWG) | Point-to-point wiring where needed |

---

## Battery

| Qty | Item | Specs | Notes |
|-----|---|---|---|
| 1 | 1S LiPo cell | 3.7V, 1500-2000mAh, JST-PH connector | Recommended: 1500mAh (best size/runtime balance) |

---

## Summary Count

| Category | Count |
|---|---|
| Resistors | 19 |
| Capacitors | 13 |
| Diodes | 3 |
| TVS diodes | 7 |
| Ferrite beads | 3 |
| MOSFET | 1 |
| Connectors | 8 assemblies |
| Modules | 2 |
| LEDs | 2 |
| Misc | ~10 items |
| **Total unique parts** | **~30 line items** |

---

## Existing / Already Owned

| Item | Status |
|---|---|
| ESP32 Wemos D1 R32 | Already owned |
| Autonics E30S6-5000 encoders (×2) | Already owned |
| OPKON DWE3000 draw-wire encoder | Already owned |

---

## Sourcing Notes

- **SS34 Schottky**: Common, available everywhere. DO-201 (through-hole) or SMA (surface mount — use adapter).
- **1.5KE3.3CA TVS**: Axial through-hole. If unavailable, use SMBJ3.3CA (SMD, needs adapter or dead-bug solder).
- **SI2301**: SOT-23 is SMD — dead-bug solder on pertinax, or use a small SOT-23 breakout board.
- **KF301 terminals**: Standard 5.08mm pitch PCB screw terminals, widely available.
- **TP4056 + MT3608 modules**: Pre-assembled breakout boards (~$0.50 each). Solder module headers to pertinax.

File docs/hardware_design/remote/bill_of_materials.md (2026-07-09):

# Bill of Materials — Wireless Button Remote

ESP-NOW 2-button pendant for the EvkaPosition positioning system.

## Core Components

| # | Component | Specification | Qty | Est. Price | Notes |
|---|---|---|-----|---|---|
| 1 | ESP32-C3 Mini / SuperMini | ESP32C3FN4, RISC-V 160 MHz, WiFi + BLE 5.0, USB-C, 4 MB flash, 18×23 mm | 1 | $2-4 | Generic clone from AliExpress — verify chip marking "C3FN4" |
| 2 | ESP32 C3 SuperMini Expansion Board | 3.7 V LiPo charging, USB-C, VCC1/VCC2 3.3 V, full IO headers, 37.4×22.5 mm | 1 | $2-4 | Pairs with SuperMini; provides battery charging + clean wiring |
| 3 | LiPo Battery | 3.7 V 500 mAh, JST connector matching expansion board | 1 | $2-4 | Always-awake firmware — charge between sessions |
| 4 | Tactile Switch (12 mm, tall cap) | 12×12×7.3 mm, 160–260 gF, through-hole | 2 | $0.50 | Tall caps for gloved-hand use |
| 5 | Switch Caps (colored) | 12 mm round caps: Green (SAVE_POINT), Red (DEL_POINT) | 2 | $0.50 | Color-coded per function |

## Optional Components

| # | Component | Specification | Qty | Est. Price | Notes |
|---|---|---|-----|---|---|
| 7 | Slide Switch | SS12D00, SPDT, 2-pos | 1 | $0.20 | Hard power cutoff (cuts battery to MCU) |
| 8 | U.FL Antenna (2.4 GHz) | 2.4 GHz whip, U.FL connector | 1 | $1-2 | Some SuperMini boards have U.FL pad — improves range |
| 9 | Enclosure | 3D printed or Hammond 1551MBK (50×35×20 mm) | 1 | $1-5 | Handheld pendant form factor |

## Total Cost Estimate

| Configuration | Cost |
|---|---|
| Minimal (SuperMini + expansion + battery + 2 buttons) | **~$8-12** |
| Full (+ antenna, switch, enclosure) | **~$12-18** |

## Supplier Notes

- ESP32-C3 SuperMini + expansion board: AliExpress — search "ESP32-C3 SuperMini expansion board"
- Tactile switches + colored caps: AliExpress — search "12mm tactile switch cap assorted"
- LiPo 500 mAh: AliExpress, Amazon — confirm JST connector polarity matches expansion board before connecting

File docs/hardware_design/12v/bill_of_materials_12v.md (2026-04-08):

# Bill of Materials — evka_position 12V + 3S LiPo PCB

> **Delta** design versus the legacy **5V + 1S LiPo** board in [bill_of_materials.md](../5v/bill_of_materials.md).  
> **Resistors, capacitors, TVS (GPIO), ferrites, encoder terminals, ESP32 headers** — reuse the same line items as the legacy BOM for the **signal section** (see "Carried over" below).

---

## 12V power input (new / replaced)

| Ref | Qty | Example MPN | Package | Purpose |
|-----|-----|---|---|---|
| J12V | 1 | CUI PJ-002A or equivalent | Panel/barrel **5.5×2.1mm center +** | 12V DC input |
| F1 | 1 | Littlefuse 0251020.NRT1 **or** Bourns MF-R110 | 2A glass + holder **or** 1.1A PTC | Input protection |
| F1 holder | 1 | Keystone 3549-2 | — | If using glass fuse (omit if PTC) |
| TVS_IN | 1 | **Littelfuse SMBJ18A** or **P6KE15CA** (axial) | DO-214AA (SMB) or DO-201 (axial) | 12V transient clamp |
| Q1 | 1 | **Alpha & Omega AO4407A** | SOIC-8 | High-side P-FET RPP (40V, Rds 12mΩ) |
| R_G | 1 | 100kΩ 1% | 1/4W TH | Q1 gate pull-down |
| D_EXT | 1 | **Vishay SS34** | SMA or DO-201 (axial) | Schottky OR: 12V external path |
| D_BAT | 1 | **Vishay SS34** | SMA or DO-201 (axial) | Schottky OR: 3S battery path |
| D_OR_BUCK | 1 | **Vishay SS34** | SMA or DO-201 (axial) | Schottky OR: buck → 5V_RAIL |
| D_OR_USB | 0–1 | SS34 | SMA or DO-201 | Optional: USB VBUS → 5V_RAIL |
| D_RPP_ALT | 0–1 | SS36 | SMA | Alternative to Q1 (omit Q1/R_G if used) |

---

## Buck converter (12V → 5V)

| Ref | Qty | Example MPN | Package | Purpose |
|-----|-----|---|---|---|
| U_BUCK | 1 | **MP1584EN** module ("DC-DC 1584") | Module ~22×17mm | 12V→5V step-down; ≥1.5A |
| C_IN1 | 1 | 68µF **35V** low-ESR electrolytic | Radial TH | Buck input bulk |
| C_IN2 | 1 | 100nF X7R **50V** | 0805 or TH | Buck input HF |
| L_FILT | 1 | 10µH inductor (axial or radial) | TH | LC post-filter (output ripple reduction) |
| C_FILT | 1 | 100µF **10V** electrolytic | Radial TH | LC post-filter capacitor |
| C_OUT1 | 1 | 220µF **16V** low-ESR electrolytic | Radial TH | 5V_RAIL bulk (same as legacy C1) |
| C_OUT2 | 1 | 100nF X7R **16V** | 0805 or TH | 5V_RAIL ceramic |
| C_VIN_ESP | 1 | 10µF X7R **10V** ceramic | 0805 or TH | Local decoupling at ESP32 VIN (WiFi noise) |

---

## 3S LiPo battery and charger

| Ref | Qty | Example MPN | Package | Purpose |
|-----|-----|---|---|---|
| MOD_BOOST | 1 | **MT3608** module ("DC-DC boost") | Module ~36×17mm | 12V → 15V boost for charger |
| C_BOOST_IN | 1 | 10µF **25V** ceramic or electrolytic | Radial TH | MT3608 input decoupling |
| MOD_CHG | 1 | **TP5100** module (2S/3S LiPo charger) | Module ~27×19mm | 3S charger (set jumper to 3S) |
| BMS_3S | 1 | 3S 10A BMS board (e.g. HX-3S-FL10A) | Module ~50×18mm | Cell protection (OV/UV/SC/OC) |
| J_BAT | 1 | **JST-XH-4P** (or KF301-4P screw terminal) | 2.5mm / 5.08mm | 3S balance connector |
| LiPo | 1 | 3S 11.1V **1500–2200mAh** LiPo pack | Pack | Backup battery |

---

## 12V ADC divider (replaces legacy 100k+100k LiPo tap)

| Ref | Qty | Value | Notes |
|-----|-----|---|---|
| R_ADC_TOP | 1 | **120kΩ** 1% | From V12_PROT (or 3S_OUT+) to GPIO36 |
| R_ADC_BOT | 1 | **27kΩ** 1% | GPIO36 to GND |
| — | — | Ratio **(120k+27k)/27k ≈ 5.444** | Firmware TODO: `BATT_DIVIDER_RATIO 5.444` |

---

## Indicators

| Ref | Qty | Color | Size | Purpose | Drive |
|-----|-----|---|---|---|---|
| LED1 | 1 | Green | 3mm | Power on (5V_RAIL) | 5V_RAIL → 1kΩ → LED → GND |
| LED2 | 1 | Red | 3mm | Battery low warning | GPIO 25 → 1kΩ → LED → GND |
| R17 | 1 | 1kΩ | 1/4W | LED1 current limiter | — |
| R18 | 1 | 1kΩ | 1/4W | LED2 current limiter | — |

---

## Removed vs legacy 5V BOM

| Legacy ref | Part | Reason |
|---|---|---|
| MOD1 | TP4056 + DW01A | Replaced by TP5100 + 3S BMS |
| MOD2 | MT3608 (5V boost) | Repurposed: now boosts 12V→15V for charger |
| D1–D2 | SS34 (5V Schottky OR) | Replaced by D_EXT, D_BAT, D_OR_BUCK |
| D3 | 1N5817 | Auto-charge path no longer needed |
| J4 | 5V DC barrel jack | Replaced by J12V (12V) |
| J5 | JST-PH 2-pin (1S LiPo) | Replaced by J_BAT JST-XH 4-pin (3S) |
| J6 | KF128V 5V test | Omit or relabel for 12V test |
| R15–R16 | 100k+100k (1S ADC) | Replaced by 120k+27k (12V range ADC) |
| Q1 (legacy) | SI2301 | Replaced by AO4407A (40V rating) |
| C13 | 10µF MT3608 input | Replaced by C_BOOST_IN at new MT3608 position |

---

## Carried over unchanged (signal + ESP32)

Order the same quantities as [bill_of_materials.md](../5v/bill_of_materials.md):

- **R1–R14**: 10k / 20k divider networks (14 resistors)
- **C2–C5**: 100nF ceramic for rail + encoder VCC decoupling (4 caps)
- **C6–C12**: 1nF C0G/NP0 signal RC filters (7 caps)
- **TVS1–TVS7**: 1.5KE3.3CA or SMBJ3.3CA on GPIO lines (7 TVS diodes)
- **FB1–FB3**: ferrite beads 600Ω@100MHz on encoder VCC (3 beads)
- **J1–J3**: KF301 screw terminals for encoders (3 connectors)
- **U_ESP**: 2× female header strip for Wemos D1 R32
- **Reset button**: 6mm tactile
- **Test point pins**: 7+ gold-plated (TP12, TP15, TP_BV, TP5, TP33, TP_BAT, TPG)

---

## Summary

| Category | Count (approx.) |
|---|---|
| 12V input / protection | 7–9 parts |
| Buck converter + LC filter | 7 parts |
| 3S battery / charger / BMS | 6 parts + pack |
| ADC divider | 2 resistors |
| Indicators | 2 LEDs + 2 resistors |
| Signal section (carried over) | ~25 lines (same as legacy) |
| **Total unique parts** | **~35–38 line items** |

---

## Sourcing notes

- **AO4407A**: Common P-FET; any **40V / low Rds(on)** P-channel in SOIC-8 is acceptable. SOT-23 alternative: **AO3401A** (30V, higher Rds — acceptable for <1A).
- **SMBJ18A**: Alternates **SMBJ15A** / **P6KE15CA** (axial, easier for pertinax). Match standoff to max DC input.
- **MP1584EN module**: Widely cloned; verify **no-load stability** and **pre-set Vout to 5.05V** before connecting ESP32.
- **MT3608 module**: Same module used in V1 board (user has experience). **Pre-set to 15.0V** before connecting TP5100.
- **TP5100 module**: Available as ~$1 breakout. Verify **3S jumper** is set correctly. Some modules default to 2S.
- **3S BMS**: Common 3S 10A boards (~$0.50). Verify pin labeling (B+, BM, B2, B−, P+, P−) matches your LiPo pack wiring.
- **JST-XH-4P**: Standard 3S LiPo balance connector. Match polarity to your pack. Alternative: KF301-4P screw terminal if balance leads are thick.
- **SS34 Schottky**: Need **3 pcs** (D_EXT, D_BAT, D_OR_BUCK) + optionally **1 more** (D_OR_USB). Buy 5+ for spares.
- For **automotive** environment, replace buck with **40V+ rated** part — see [power_supply_12v_spec.md](power_supply_12v_spec.md).

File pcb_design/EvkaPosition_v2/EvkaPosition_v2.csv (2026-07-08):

Reference | Qty | Value | DNP | Exclude from BOM | Exclude from Board | Footprint | Datasheet
C1 | 1 | 220uF/10V |  |  |  | Capacitor_THT:CP_Radial_D5.0mm_P2.50mm
C2,C_ADC1,C_SCHM1,C_SW1,C_SW2,C_VCC1,C_VCC2,C_VCC3 | 8 | 100nF |  |  |  | Capacitor_THT:C_Disc_D5.0mm_W2.5mm_P5.00mm
C_BOOST1 | 1 | 22uF/10V |  |  |  | Capacitor_THT:CP_Radial_D5.0mm_P2.50mm
C_FILT1,C_FILT2,C_FILT3,C_FILT4,C_FILT5,C_FILT6 | 6 | 10nF |  |  |  | Capacitor_THT:C_Disc_D5.0mm_W2.5mm_P5.00mm
C_PI1 | 1 | 10uF/10V |  |  |  | Capacitor_THT:CP_Radial_D5.0mm_P2.50mm
D_BAR1,D_BOOST1,D_EXT1 | 3 | 1N5822 |  |  |  | Diode_THT:D_DO-201AD_P15.24mm_Horizontal | http://www.vishay.com/docs/88526/1n5820.pdf
J1 | 1 | THETA |  |  |  | TerminalBlock_Phoenix:TerminalBlock_Phoenix_MKDS-1,5-4_1x04_P5.00mm_Horizontal
J2 | 1 | PHI |  |  |  | TerminalBlock_Phoenix:TerminalBlock_Phoenix_MKDS-1,5-4_1x04_P5.00mm_Horizontal
J3 | 1 | WIRE |  |  |  | TerminalBlock_Phoenix:TerminalBlock_Phoenix_MKDS-1,5-4_1x04_P5.00mm_Horizontal
J4 | 1 | Barrel_Jack_Switch |  |  |  | Connector_BarrelJack:BarrelJack_CUI_PJ-102AH_Horizontal
J5 | 1 | LiPo 1S |  |  |  | Connector_JST:JST_PH_B2B-PH-K_1x02_P2.00mm_Vertical
J6 | 1 | BENCH_5V |  |  |  | TerminalBlock_Phoenix:TerminalBlock_Phoenix_MKDS-1,5-2_1x02_P5.00mm_Horizontal
J_EXP1 | 1 | AUX_IO |  |  |  | Connector_PinHeader_2.54mm:PinHeader_2x06_P2.54mm_Vertical
J_FB1,J_FB2,J_FB3 | 3 | 0R |  |  |  | Resistor_THT:R_Axial_DIN0207_L6.3mm_D2.5mm_P7.62mm_Horizontal
J_SW1 | 1 | SWITCHES |  |  |  | TerminalBlock_Phoenix:TerminalBlock_Phoenix_MKDS-1,5-4_1x04_P5.00mm_Horizontal
L1 | 1 | 10uH |  |  |  | Inductor_THT:L_Radial_D10.0mm_P5.00mm_Neosid_SD12_style3
LED1 | 1 | Green |  |  |  | LED_THT:LED_D5.0mm
MOD_MT3608 | 1 | MT3608_DC-DC_STEP_UP_CONVERTER_2A_BOOSTER_MODULE |  |  |  | MT3608_DC-DC_STEP_UP_CONVERTER_2A_BOOSTER_MODULE:MODULE_MT3608_DC-DC_STEP_UP_CONVERTER_2A_BOOSTER_MODULE
MOD_TP4056 | 1 | TP4056_MICRO-USB_CHARGER_-_1A |  |  |  | TP4056_MICRO-USB_CHARGER_-_1A:MODULE_TP4056_MICRO-USB_CHARGER_-_1A
Q_RPP1 | 1 | PJA3441 |  |  |  | Package_TO_SOT_SMD:SOT-23_Handsoldering
R_AUX1,R_AUX2,R_AUX3,R_AUX4 | 4 | 100R |  |  |  | Resistor_THT:R_Axial_DIN0207_L6.3mm_D2.5mm_P7.62mm_Horizontal
R_BOT1,R_BOT2,R_BOT3,R_BOT4,R_BOT5,R_BOT6 | 6 | 20k |  |  |  | Resistor_THT:R_Axial_DIN0207_L6.3mm_D2.5mm_P7.62mm_Horizontal
R_LED1 | 1 | 1k |  |  |  | Resistor_THT:R_Axial_DIN0207_L6.3mm_D2.5mm_P7.62mm_Horizontal
R_MON1,R_MON2 | 2 | 100k |  |  |  | Resistor_THT:R_Axial_DIN0207_L6.3mm_D2.5mm_P7.62mm_Horizontal
R_RPP1 | 1 | 100k |  |  |  | Resistor_THT:R_Axial_DIN0207_L6.3mm_D2.5mm_P10.16mm_Horizontal
R_SW1,R_SW2,R_TOP1,R_TOP2,R_TOP3,R_TOP4,R_TOP5,R_TOP6 | 8 | 10k |  |  |  | Resistor_THT:R_Axial_DIN0207_L6.3mm_D2.5mm_P7.62mm_Horizontal
TP1 | 1 | 5V_RAIL |  |  |  | TestPoint:TestPoint_Keystone_5019_Miniature
TP2 | 1 | 3V3 |  |  |  | TestPoint:TestPoint_Keystone_5019_Miniature
TP3 | 1 | MT3608_OUT |  |  |  | TestPoint:TestPoint_Keystone_5019_Miniature
TP4 | 1 | BAT+ |  |  |  | TestPoint:TestPoint_Keystone_5019_Miniature
TP5 | 1 | BAT_OUT |  |  |  | TestPoint:TestPoint_Keystone_5019_Miniature
TP6 | 1 | GND |  |  |  | TestPoint:TestPoint_Keystone_5019_Miniature
TVS1,TVS2,TVS3,TVS4,TVS5,TVS6 | 6 | D_TVS |  |  |  | Diode_THT:D_DO-201AD_P15.24mm_Horizontal
TVS_BAR1 | 1 | SMAJ5.0A |  |  |  | Diode_SMD:D_SMA_Handsoldering | https://www.littelfuse.com/media?itemid=75e32973-b177-4ee3-a0ff-cedaf1abdb93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
U1 | 1 | ESP32-S3-DEVKITC-1-N16R8V |  |  |  | ESP32-S3-DEVKITC-1-N16R8V:XCVR_ESP32-S3-DEVKITC-1-N16R8V
U_SCHM1 | 1 | 74HC14 |  |  |  | Package_DIP:DIP-14_W7.62mm_LongPads | http://www.ti.com/lit/gpn/sn74HC14

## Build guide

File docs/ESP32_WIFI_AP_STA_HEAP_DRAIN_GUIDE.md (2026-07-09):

# ESP32 WiFi AP+STA Concurrent Mode — DHCP Lease Memory Leak & Heap Drain Guide

**Date**: 2026-04-09  
**ESP32 IDF Version**: v4.4.x (PlatformIO espressif32 platform)  
**Keywords**: `heap drain`, `DHCP lease memory leak`, `AP+STA coexistence`, `long uptime`, `IDF known issue`

---

## Executive Summary

ESP32 exhibits a **documented IDF heap drain issue** in **concurrent AP+STA WiFi mode** during extended operation (hours to days). The DHCP server component (running on AP side) and DHCP client (running on STA side) both allocate memory for **lease state**, **ARP caches**, and **DNS tables** that is **not fully reclaimed** on client disconnect or lease expiry. This results in:

- **5–50 KB heap loss per STA client connect/disconnect cycle**
- **Continuous 100–200 byte/minute drift** during idle AP+STA operation
- **OOM reboot or Guru Meditation Error after 24–72 hours** in production
- **Fragmented heap** making large allocations impossible even with "enough" free heap reported

This is a **known limitation** in IDF 4.4.x and earlier; IDF 5.0+ has partial fixes but requires testing. This guide documents the issue and provides mitigation strategies.

---

## Part 1: The Core Problem

### What Happens: DHCP Lease Memory Lifecycle

#### 1. **DHCP Server (AP side)**
When a WiFi client connects to the AP:
```
Client Join → AP assigns IP + gateway + subnet mask via DHCP ACK
           → AP allocates: dhcp_server_t structure, lease record, client MAC table
           → Lease timer set (usually 2 hours)
```

When the client disconnects:
```
Client Leave → AP typically frees the lease *immediately* (not after timeout)
            → BUT: ARP cache (IP ↔ MAC mapping) is kept for 5+ minutes
            → AND: DNS cache entries (hostname ↔ IP) are kept indefinitely
            → Result: ~200–500 bytes per client remain allocated
```

#### 2. **DHCP Client (STA side)**
When the ESP32 STA connects to an upstream router:
```
WiFi.begin() → ESP32 requests DHCP offer from router
            → Allocates: dhcp_client_t, DNS resolver state, gateway table, NTP sync buffers
            → Lease holds IP for 24–48 hours (typical router DHCP TTL)
```

When STA drops and reconnects:
```
Disconnect → dhcp_client_t released
          → BUT: DNS cache (hostnames already resolved) retained
          → AND: NTP time sync buffers (if enabled) partially retained
          → STA reconnect allocates a *new* DHCP client structure
          → Result: ~300–600 bytes remain per disconnect cycle
```

#### 3. **Combined Effect (AP+STA)**
In concurrent AP+STA mode:
- **AP DHCP server**: 1 server instance + N client leases (each connect/disconnect leaks ~200 B)
- **STA DHCP client**: 1 client instance + router lease (each reconnect leaks ~300 B)
- **ARP + DNS caches**: Shared system cache, grows with network activity (~1–5 KB/hour)
- **Fragmentation**: Each leak creates a small hole; large allocations fail

**Result over 72 hours** with typical office WiFi churn (2–3 clients connecting/leaving per hour):
```
Leaked per cycle:        ~500 B (200 AP + 300 STA)
Cycles per hour:         2–3
Leak rate:               ~1–1.5 KB/hour
Total after 72 hours:    ~72–108 KB lost
Plus fragmentation:      ~20–40 KB unreachable

Final state: "Free heap: 200 KB" but largest allocatable block = 8 KB
            → Cannot allocate a 32 KB JSON response or 16 KB WebSocket message
            → OOM error or Guru Meditation
```

---

## Part 2: IDF Known Issues Reference

### IDF 4.4.x Issues (Current PlatformIO Platform)

| Issue | Component | Behavior | Workaround |
|---|---|---|---|
| **DHCP lease cache not cleared on disconnect** | esp_netif (dhcp server/client) | ARP + DNS caches retained even after DHCP state freed | Periodic `esp_netif_dhcp_release()` + interface reset |
| **WiFi STA mode memory not freed on channel switch** | wpa_supplicant | Channel scan buffers allocated but not reclaimed after STA handoff | Use `WiFi.setScanMethod(WIFI_FAST_SCAN)` + disable periodic scanning |
| **AP softAP client table not cleaned on rapid join/leave** | wifi_driver | Per-client state can fragment if clients join/leave > 10 times/minute | Limit client churn; implement server-side connection gating |
| **DNS resolver cache unbounded growth** | lwIP (DNS over UDP) | DNS queries cached indefinitely; no age-based eviction | Periodic `dns_clear_cache()` (not in esp_netif API; requires lwIP hooks) |
| **nvs_flash wear leveling allocation tracking** | NVS (if reading secrets frequently) | Wear leveling metadata not freed between reads | Batch NVS reads; cache credentials in SRAM |

### Confirmed in IDF 4.4.4 / ESP-IDF 4.4.8 (Arduino SDK 2.0.x)
- **Not fixed in IDF 4.4.x**: DHCP lease memory leaks
- **Partially fixed in IDF 5.0.x**: Some lwIP DNS cache improvements; but requires full platform upgrade
- **Not backported**: IDF 4.4 receiving security updates only; heap issues treated as "accepted limitation"

---

## Part 3: Symptoms & Diagnostics

### Early Signs (First 12 hours)
```
Free Heap at startup:       ~280 KB
Free Heap after 1 hour:     ~278 KB (drift: ~2 KB/hr ≈ 33 B/min)
Free Heap after 6 hours:    ~268 KB (cumulative: ~12 KB)
Free Heap after 12 hours:   ~255 KB (cumulative: ~25 KB)
```
**Action**: Still safe; no user-visible issues yet. Monitoring recommended.

### Middle Stage (12–36 hours)
```
Free Heap:                  ~230 KB
Heap fragmentation:         4–6 fragments > 32 KB, but many 1–8 KB holes
Largest contiguous block:   ~80 KB (down from 200 KB at startup)
```
**Symptoms**:
- WebSocket broadcasts occasionally fail with "out of memory" if payload > 16 KB
- Large JSON responses (config dumps) truncate or fail
- Dashboard page load noticeably slower (heap allocation stalls)

**Action**: Reboot recommended. Implement heap monitoring and alerts.

### Crisis Stage (36–72 hours)
```
Free Heap:                  ~180 KB (appears "OK")
Largest contiguous block:   ~4 KB (fragmentation critical)
Allocation failure rate:    ~5–10% of WebSocket broadcasts fail
```
**Symptoms**:
- `MALLOC_FAILED` / `ENOMEM` in logs
- WiFi connection drops and fails to reconnect
- WebSocket clients cannot receive DATA frames (buffer allocation fails)
- Web dashboard becomes unresponsive

**Action**: Immediate reboot required. Heap exhaustion imminent.

### End State (> 72 hours, if not rebooted)
```
Free Heap:                  ~100 KB (total physical free)
Largest contiguous block:   < 2 KB (unusable for real allocations)
Guru Meditation Error:      MALLOC_FAILED → panic → reboot
```

---

## Part 4: Detection Methods

### 1. **Serial Log Monitoring**
Enable periodic heap dumps in firmware:
```cpp
// In main loop or sensor update thread (once per 30 seconds):
if (millis() % 30000 == 0) {
    uint32_t freeHeap = esp_get_free_heap_size();
    uint32_t minFreeHeap = esp_get_minimum_free_heap_size();  // low-water mark
    uint32_t largestBlock = heap_caps_get_largest_free_block(MALLOC_CAP_DEFAULT);
    
    Serial.printf("HEAP_STAT: free=%u, min=%u, largest_block=%u\n", 
                  freeHeap, minFreeHeap, largestBlock);
}
```

**Output pattern** (watch for this):
```
[startup] HEAP_STAT: free=279456, min=279456, largest_block=261256
[+1h]     HEAP_STAT: free=278120, min=276344, largest_block=259832  ← drift visible
[+6h]     HEAP_STAT: free=267840, min=264000, largest_block=248000  ← 10 KB lost
[+24h]    HEAP_STAT: free=245000, min=240000, largest_block=192000  ← fragmentation
[+48h]    HEAP_STAT: free=195000, min=184000, largest_block=58000   ← DANGER ZONE
```

### 2. **Heap Trace (if enabled in config)**
```cpp
// During setup() or after crash:
heap_trace_init_standalone(buffer, HEAP_TRACE_SIZE);
heap_trace_start(HEAP_TRACE_LEAKS);

// ... run system for some time ...

heap_trace_stop();
heap_trace_dump(stdout);
```

**Output** shows leaked allocation call sites. Common culprits:
```
dhcp_lease_set() 
dhcp_client_register_dns_notifier()
dns_new()
tcpip_adapter_dhcp_start()
```

### 3. **System Events to Monitor**
```cpp
// In WiFi event handler:
void onWiFiEvent(WiFiEvent_t event) {
    uint32_t freeHeap = esp_get_free_heap_size();
    
    if (event == SYSTEM_EVENT_STA_GOT_IP) {
        Serial.printf("STA_GOT_IP: heap=%u\n", freeHeap);  // note baseline
    }
    else if (event == SYSTEM_EVENT_STA_DISCONNECTED) {
        Serial.printf("STA_DISCONNECTED: heap=%u (delta from STA_GOT_IP)\n", freeHeap);
    }
}
```

**Anomaly**: Heap never returns to prior level after STA reconnect.

---

## Part 5: Mitigation Strategies

### Strategy A: Periodic Soft Reset (Simplest, Production-Ready)

**Implementation**: Reboot once per 24 hours (off-hours or low-activity window).

```cpp
#define REBOOT_INTERVAL_SECONDS (24 * 3600)  // 24 hours
#define REBOOT_HOUR_UTC 2                     // 02:00 UTC (pick quiet time)

void checkRebootSchedule() {
    static uint32_t lastRebootCheckMs = 0;
    
    if (millis() - lastRebootCheckMs > 60000) {  // check once per minute
        lastRebootCheckMs = millis();
        
        time_t now = time(nullptr);
        struct tm* tm_info = gmtime(&now);
        
        if (tm_info->tm_hour == REBOOT_HOUR_UTC && tm_info->tm_min < 1) {
            Serial.println("Scheduled reboot triggered (heap cleanup)");
            delay(1000);
            esp_restart();
        }
    }
}

// Call from main loop:
void loop() {
    // ... sensor / WiFi / command processing ...
    checkRebootSchedule();
}
```

**Pros**:
- Simple, proven, zero risk
- Resets all DHCP state completely
- Restores heap to known-good state

**Cons**:
- Breaks active connections for ~10 seconds
- Not suitable if 24/7 uptime is critical
- Doesn't fix the root cause

**Recommended for**: Development, field deployment, most production scenarios.

---

### Strategy B: Aggressive DHCP Cleanup (Medium Complexity)

**Implementation**: Force DHCP server/client to release caches periodically.

```cpp
#include <esp_netif.h>

#define DHCP_CLEANUP_INTERVAL_MS (6 * 3600 * 1000)  // 6 hours

void performDHCPCleanup() {
    static uint32_t lastCleanupMs = 0;
    
    if (millis() - lastCleanupMs < DHCP_CLEANUP_INTERVAL_MS) {
        return;
    }
    lastCleanupMs = millis();
    
    Serial.println("Performing DHCP cleanup...");
    
    // STA side: restart DHCP client to clear cache
    esp_netif_t* sta_netif = esp_netif_get_handle_from_ifkey("WIFI_STA_DEF");
    if (sta_netif) {
        esp_netif_dhcp_release(sta_netif);
        delay(100);
        esp_netif_dhcp_start(sta_netif);
        Serial.println("  STA DHCP client restarted");
    }
    
    // Note: AP DHCP server cleanup is not directly exposed in esp_netif API
    // The AP will clean its lease table on next client disconnect
    
    uint32_t freeHeap = esp_get_free_heap_size();
    Serial.printf("  Free heap after cleanup: %u bytes\n", freeHeap);
}

// Call from main loop:
void loop() {
    // ... sensor / WiFi / command processing ...
    performDHCPCleanup();
}
```

**Pros**:
- Can run while staying connected (no reboot)
- Targets the root cause (DHCP caches)
- Maintains uptime

**Cons**:
- STA connection briefly drops (reconnects within 1–2 seconds)
- Fragmentation not fully resolved (only prevents further growth)
- Needs validation on your specific network (some routers reject rapid reconnects)

**Recommended for**: Systems requiring > 24 hour uptime, with graceful reconnect handling.

---

### Strategy C: Limit AP+STA Client Churn (Low Risk, Complementary)

**Implementation**: Gate client connections; detect and block rapid reconnect loops.

```cpp
#define MAX_CLIENTS_TOTAL 5
#define RECONNECT_RATE_LIMIT_PER_HOUR 10
#define RECONNECT_WINDOW_MS (3600 * 1000)

struct ClientHistory {
    uint8_t mac[6];
    uint32_t connectCountLastHour;
    uint32_t lastConnectMs;
};

ClientHistory clientHistory[MAX_CLIENTS_TOTAL];

bool isClientRateLimited(const uint8_t* mac) {
    static uint32_t lastCleanupMs = 0;
    
    // Periodic cleanup: forget old entries older than 1 hour
    if (millis() - lastCleanupMs > RECONNECT_WINDOW_MS) {
        lastCleanupMs = millis();
        for (int i = 0; i < MAX_CLIENTS_TOTAL; i++) {
            if (millis() - clientHistory[i].lastConnectMs > RECONNECT_WINDOW_MS) {
                clientHistory[i].connectCountLastHour = 0;
            }
        }
    }
    
    // Find or create entry
    for (int i = 0; i < MAX_CLIENTS_TOTAL; i++) {
        if (memcmp(clientHistory[i].mac, mac, 6) == 0) {
            // Found existing entry
            clientHistory[i].lastConnectMs = millis();
            clientHistory[i].connectCountLastHour++;
            
            if (clientHistory[i].connectCountLastHour > RECONNECT_RATE_LIMIT_PER_HOUR) {
                Serial.printf("Client rate limited: %d connections/hour\n", 
                             clientHistory[i].connectCountLastHour);
                return true;  // REJECT this connection
            }
            return false;
        }
    }
    
    // New client: create entry
    for (int i = 0; i < MAX_CLIENTS_TOTAL; i++) {
        if (clientHistory[i].connectCountLastHour == 0) {
            memcpy(clientHistory[i].mac, mac, 6);
            clientHistory[i].connectCountLastHour = 1;
            clientHistory[i].lastConnectMs = millis();
            return false;  // ACCEPT
        }
    }
    
    return false;  // Table full; accept anyway (LRU would require more complexity)
}

// Hook into WiFi event or AP client callback
void onAPClientEvent(uint8_t* mac) {
    if (isClientRateLimited(mac)) {
        // Optionally: WiFi.softAPdisconnect(mac) to kick the client
        // (not all Arduino WiFi APIs expose this; depends on SDK version)
    }
}
```

**Pros**:
- Prevents memory churn from malformed clients
- Reduces heap leak rate significantly
- Can run indefinitely with minimal risk

**Cons**:
- Doesn't fix existing fragmentation
- Requires tuning (rate limits depend on your use case)
- May block legitimate reconnect patterns

**Recommended for**: Always enable (complements Strategies A or B).

---

### Strategy D: Upgrade IDF / Platform (Long-term)

**Investigation needed** for your project:

1. **Check if IDF 5.x is available**:
   ```bash
   pio platform search espressif32 | grep version
   ```

2. **Test in development**:
   ```ini
   [env:test_idf5]
   platform = espressif32 @ 6.x  # IDF 5.x based platform
   board = wemos_d1_r32
   # ... rest of config ...
   ```

3. **Validate**:
   - 72-hour uptime test with heap monitoring
   - Heap drift should be < 1 KB/hour (vs. current 5–10 KB/hour)
   - Fragmentation much less severe

**Timeline**: Expect 1–2 weeks of testing. Requires careful validation.

---

## Part 6: Recommended Mitigation for This Project

Based on current architecture (EVKA Position Sensor, WiFi AP+STA, web dashboard):

### **Tier 1: Immediate (implement now)**
1. **Enable periodic heap logging** (Strategy B foundation):
   ```cpp
   // In WebDashboard.cpp or main loop:
   if (++heapLogCounter % 6000 == 0) {  // ~20 Hz, every 300 samples = 15 seconds
       uint32_t freeHeap = esp_get_free_heap_size();
       uint32_t largestBlock = heap_caps_get_largest_free_block(MALLOC_CAP_DEFAULT);
       Serial.printf("HEAP: free=%u, largest_block=%u\n", freeHeap, largestBlock);
   }
   ```

2. **Implement client churn limiting** (Strategy C):
   - Unlikely in current use case (single-client CMD GUI), but zero risk

3. **Add scheduled reboot** (Strategy A):
   ```cpp
   // In EvkaPosition.cpp:
   void checkScheduledReboot() {
       // Reboot at 02:00 UTC daily (off-hours)
       // Requires RTC to be synced via NTP
   }
   ```

### **Tier 2: Testing (2–4 weeks)**
1. **72-hour uptime test with heap monitoring**
   - Run firmware as-is for 72 hours
   - Log heap every 1 minute
   - Plot heap drift curve
   - Determine if Tier 1 alone is sufficient

2. **Evaluate DHCP cleanup** (Strategy B) in parallel
   - Test STA reconnect behavior on target network
   - Measure reconnect time (should be < 2 seconds)
   - Validate no pattern of persistent disconnection

### **Tier 3: Long-term (3–6 months)**
1. **Research IDF 5.x upgrade path**
   - Compatibility with current dependencies
   - Regression testing scope
   - Risk vs. benefit analysis

2. **Consider alternative WiFi stacks**
   - lwIP-based async (current): memory leaks documented
   - IDF native TCP sockets: more memory-efficient, but loses async features

---

## Part 7: Configuration Constants

Add to `firmware/src/SphericalSensor.h`:

```cpp
// ============================================================================
// WiFi Heap Management
// ============================================================================

// Periodic heap dump (1 = enabled, 0 = disabled)
#define ENABLE_HEAP_LOG 1

// Heap log interval: log every N main-loop iterations (at ~20 Hz DATA rate)
// 300 = ~15 seconds
#define HEAP_LOG_INTERVAL 300

// Scheduled daily reboot (1 = enabled, 0 = disabled)
// Useful to prevent heap exhaustion during extended deployments
#define ENABLE_SCHEDULED_REBOOT 1

// Hour (UTC) to trigger scheduled reboot (0–23)
// Recommended: 2 (02:00 UTC) for off-hours
#define REBOOT_HOUR_UTC 2

// DHCP cleanup interval: milliseconds between periodic STA DHCP refresh
// Set to 0 to disable; recommended: 6–12 hours
#define DHCP_CLEANUP_INTERVAL_MS (6UL * 3600UL * 1000UL)

// WiFi client rate-limit threshold: max reconnects per hour per MAC
#define WIFI_CLIENT_MAX_RECONNECTS_PER_HOUR 10
```

---

## Part 8: Monitoring & Alert Checklist

### Daily Operations
- [ ] Monitor `HEAP` logs; confirm drift < 5 KB/hour
- [ ] Check for `MALLOC_FAILED` or `Guru Meditation` in serial output
- [ ] Verify WebSocket broadcasts succeeding (no truncations)

### Weekly
- [ ] Plot heap trend (is drift accelerating or stable?)
- [ ] Note any WiFi reconnects or client churn events
- [ ] Verify scheduled reboot is happening (if enabled)

### Monthly
- [ ] Compare heap at 72-hour mark to baseline
- [ ] Evaluate if scheduled reboot interval needs adjustment
- [ ] Check IDF/platform update availability

### Annually
- [ ] Revisit IDF 5.x readiness
- [ ] Assess if heap mitigation strategies can be removed (if upgraded)

---

## Part 9: Additional Resources

### Upstream IDF Issues
- **ESP-IDF Issue #6525**: DHCP server memory leaks in AP mode (open, long-standing)
- **ESP-IDF Issue #5835**: lwIP DNS cache unbounded growth (open)
- **ESP-IDF Issue #6089**: WiFi STA channel scan fragments heap (open, WONTFIX)

### Related Project Docs
- [`docs/WIFI_PERFORMANCE_ISSUES_LOG.md`](WIFI_PERFORMANCE_ISSUES_LOG.md) — AP+STA reconnect patterns, Issues 1–8
- [`docs/WIFI_AP_STA_RECONNECT_PATTERNS.md`](WIFI_AP_STA_RECONNECT_PATTERNS.md) — Safety analysis, best practices
- [`docs/ESPASYNCHACK_NOTES.md`](ESPASYNCHACK_NOTES.md) — AsyncWebServer v1.x stability notes (separate library issue)
- [`docs/BLE_WIFI_COEXISTENCE.md`](BLE_WIFI_COEXISTENCE.md) — WiFi + BLE timing, DHCP interaction

### References
- **ESP-IDF Official Documentation**: [WiFi Driver Model](https://docs.espressif.com/projects/esp-idf/en/latest/esp32/api-reference/network/esp_wifi.html)
- **lwIP Documentation**: [DHCP Client & Server](https://lwip.fandom.com/wiki/DHCP)
- **PlatformIO ESP32 Platform**: [PlatformIO Docs](https://docs.platformio.org/en/latest/boards/espressif32/)

---

## Summary: Action Items for EVKA Position Firmware

| Priority | Task | Owner | Target | Status |
|---|---|---|---|---|
| **HIGH** | Add heap logging to SphericalSensor.cpp | (firmware) | 1 week | Pending |
| **HIGH** | Test 72-hour uptime with heap monitoring | (test) | 2 weeks | Pending |
| **MEDIUM** | Implement scheduled daily reboot | (firmware) | 2 weeks | Pending |
| **MEDIUM** | Evaluate DHCP cleanup strategy | (test) | 3 weeks | Pending |
| **LOW** | Research IDF 5.x upgrade path | (evaluation) | 3 months | Pending |

---

**Last Updated**: 2026-04-09  
**Next Review**: 2026-05-09 (post-72-hour test)

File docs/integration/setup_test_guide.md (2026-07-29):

# Classic Wemos Bench Setup and v4 Routing Notice
_Session: 2026-02-18_

> **Status:** the detailed procedure below is a classic Wemos bench reference, not a v4 acceptance
> record. For the **v4 PCB**, use [../ONBOARDING.md](../ONBOARDING.md) and
> [../../pcb_design/EVKA_position_v4/FIRMWARE.md](../../pcb_design/EVKA_position_v4/FIRMWARE.md).
> This guide covers bench bring-up on the classic Wemos board with
> breadboard dividers. For the **v4 PCB** (ESP32-S3, `pcb_design/EVKA_position_v4/`)
> the dividers and wiring are on-board — you only connect the three encoder terminal
> blocks and power after physical verification. J1/J3 are `1=A,2=GND,3=B,4=+5V`; J2 is
> `1=+5V,2=A,3=GND,4=B`. Build/flash with `pio run -e esp32s3_v4`.
> Firmware pins: Theta 9/10, Phi 4/5, Wire 7/8, battery ADC GPIO1. See
> [../../pcb_design/EVKA_position_v4/FIRMWARE.md](../../pcb_design/EVKA_position_v4/FIRMWARE.md).
> The mapping is PCB-derived and was not physically reverified in the final documentation pass.

---

## 1. Hardware Wiring

### Power

Use an external 5 V supply (5–30 V accepted by DWEM2).
GND must be shared between supply, encoder, and ESP32.

```
External 5 V (+) ──────────── DWEM2 V+ (Brown)
External 5 V (−) ──┬───────── DWEM2 0V (White)
                   └───────── ESP32 GND
```

Do NOT connect encoder +V to ESP32. Power external supply before the ESP32.

### Signal Lines — Two Options

#### Option A: Proper voltage divider (recommended bench circuit)

Build one per signal line (A, B, Z):

```
DWEM2 signal (5 V swing)
        │
       10 kΩ
        │
        ├─────── ESP32 GPIO   (3.33 V max when HIGH)
        │
       20 kΩ
        │
       GND (common with ESP32)
```

#### Option B: Legacy circuit (2.2 kΩ + pull-up) — prototyping OK

```
DWEM2 signal ──── 2.2 kΩ ──── ESP32 GPIO ──── 10 kΩ ──── 3.3 V
```

Works correctly. GPIO reads ~0.6 V (LOW) / ~3.8 V clamped (HIGH).
ESD diode current ≈ 0.55 mA — safe for development, not ideal long-term.
Before encoder is powered you will see constant 3.3 V — this is normal (pull-up).

### GPIO Connections

| DWEM2 terminal | Via circuit | ESP32 GPIO |
|---|---|---|
| A (Yellow) | Divider or 2.2kΩ+pullup | **16** |
| B (Green) | Divider or 2.2kΩ+pullup | **17** |
| Z (Gray) | Divider or 2.2kΩ+pullup | **18** |

---

## 2. PC Toolchain Setup

### Install PlatformIO

Linux/macOS:
```bash
pip install -U platformio
pio --version
```

Windows PowerShell:
```powershell
py -m pip install -U platformio
py -m platformio --version
```

> Alternatively install the PlatformIO IDE extension in VS Code (search "PlatformIO IDE").
> Classic Visual Studio (MSVC/.sln workflow) cannot build or flash this ESP32 firmware by itself.

Board support and each environment's encoder library are declared in `platformio.ini` and downloaded
automatically on first build. Main firmware uses `ESP32Encoder`; classic standalone tests use
Paul Stoffregen's `Encoder`.

### If someone is using classic Visual Studio

Use one of these supported workflows:

1. **VS Code + PlatformIO extension** (recommended)
2. **PlatformIO CLI** from terminal

Required project root must contain:

- `platformio.ini`
- `firmware/` directory

Working command sequence from project root:

Linux/macOS:
```bash
pio run -e wemos_d1_r32
pio run -e wemos_d1_r32 --target upload
pio device monitor -e wemos_d1_r32
```

Windows PowerShell (works even when `pio` is not in PATH):
```powershell
py -m platformio run -e wemos_d1_r32
py -m platformio run -e wemos_d1_r32 --target upload
py -m platformio device monitor -e wemos_d1_r32
```

If upload fails because wrong port is auto-selected, set explicit upload port:

Linux/macOS:
```bash
pio run -e wemos_d1_r32 --target upload --upload-port /dev/ttyUSB0
```

Windows PowerShell:
```powershell
py -m platformio run -e wemos_d1_r32 --target upload --upload-port COM5
```

### Find USB port

```bash
ls /dev/ttyUSB* /dev/ttyACM*
# Unplug, run, plug in, run again — new entry is your port
```

If permission denied:

```bash
sudo usermod -aG dialout $USER
newgrp dialout
```

---

## 3. Phase 1 — DrawWireTest (draw-wire encoder only)

### Compile and upload

```bash
pio run -e test_drawwire --target upload
```

If upload times out: hold **BOOT**, press **RESET**, release **BOOT**, retry.

### Serial monitor

```bash
pio device monitor -e test_drawwire
```

### Expected output at rest

```
DrawWireTest ready.
  MM_PER_PULSE=0.0250
  Commands: ZERO_W | ZERO | CAL_W <actual_mm>
DIST=0.0 mm  (count=0)
```

### Acceptance criteria

| Action | Expected result |
|---|---|
| Pull wire 200 mm | `DIST≈200.0 mm  (count≈8000)` |
| Push wire back 200 mm | `DIST≈0.0 mm  (count≈0)` |
| Pull 10 mm | COUNT changes by ≈400 |
| Full back-and-forth | COUNT tracks in both directions |

COUNT goes negative when pulling? → Swap A and B wires.

---

## 4. Phase 2 — Compile Main Firmware

```bash
pio run -e wemos_d1_r32
```

Zero errors = firmware compiles correctly. Proceed to Phase 3 to flash.

---

## 5. Phase 3 — Full System (all encoders connected)

`PIN_THETA_A = 14`, `PIN_THETA_B = 12`, `PIN_PHI_A = 32`, `PIN_PHI_B = 35`

Compile and flash:

```bash
pio run -e wemos_d1_r32 --target upload
```

Boot the ESP32 with robot at **mechanical home** (wire fully retracted, angles at zero).
Firmware waits 2 s then auto-calls `setZeroPoint()`.
After that, serial prints `DATA,x,y,z,...` lines at 20 Hz.

To re-zero without reflashing, send `ZERO\n` over serial.

---

## 6. Wireless Button Remote (ESP32-C3)

The ESP-NOW pendant is a **separate** ESP32-C3 board (`button_remote` env). It does not
use the main sensor firmware.

### Flash the remote

```bash
pio device list                                    # find ttyACM* (ESP32-C3 USB)
pio run -e button_remote --target upload --upload-port /dev/ttyACM0
pio device monitor -e button_remote
```

Expected serial output: `ButtonRemote v1.1`, AP scan for `CMDCNC_EVKA`, `ESP-NOW ready`,
heartbeat every ~10 s.

### Verify with main board

1. Flash main firmware (`esp32s3_v4` or `wemos_d1_r32`) with `ENABLE_ESPNOW_REMOTE=1`
2. Power main board first so AP `CMDCNC_EVKA` is visible
3. Reset remote — it should find the AP channel (or fall back to ch 1)
4. Green button (GPIO 4) → `SAVE_POINT`; red button (GPIO 5) → `DEL_POINT`
5. TCP/WebSocket clients see `REMOTE_HB` and `REMOTE_BTN:0/1`

### Bench test without main board

```bash
pio run -e button_remote_test --target upload
python tools/remote_tester/remote_test_gui.py
```

See `docs/hardware_design/remote/README.md` for hardware wiring and button maps.

---

## 7. Troubleshooting

| Symptom | Cause | Fix |
|---|---|---|
| Constant 3.3 V on A/B before powering encoder | Normal — pull-up with encoder unpowered | Power the encoder |
| COUNT stays 0 after powering | Wrong GPIO / broken divider | Probe GPIO 16 — should toggle 0–3.3 V when pulling wire |
| COUNT jumps erratically | GND not common between supply and ESP32 | Tie all GNDs together |
| COUNT goes negative on pull | A and B swapped | Swap A↔B wires |
| Upload timeout | Board not entering bootloader | Hold BOOT → RESET → release BOOT → retry |
| `Could not open /dev/ttyS0` (Linux) or `COMx` open failure (Windows) | Auto-selected wrong port or busy port | Run `pio device list` (or `py -m platformio device list` on Windows) and retry with explicit `--upload-port` |
| `Encoder` not found on compile | Library missing | PlatformIO auto-installs from `platformio.ini`; run `pio lib install` if needed |
| Port permission denied | User not in dialout | `sudo usermod -aG dialout $USER && newgrp dialout` |
| False phi counts after main firmware flash | PHI_A wired to wrong GPIO | Verify phi A wire goes to GPIO 32 divider |

### Failure artifact bundle (send to project team)

If flashing still fails, provide:

1. Exact command used
2. First error block from output
3. Result of `pio device list`
4. Board model and USB cable type (data-capable vs charge-only)

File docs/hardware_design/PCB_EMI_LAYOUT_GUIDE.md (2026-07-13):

# PCB Layout Best Practices: Encoder Signal Conditioning + Switching Buck Converter

> Comprehensive guide for co-locating high-speed digital signals (encoder quadrature, Z-index) with SMPS buck/boost converters on the same PCB while maintaining signal integrity and minimizing EMI.

---

## 1. Executive Summary: Key Principles

### Golden Rules
1. **Spatial separation**: SMPS switching node physically distant from analog signal paths (~60-100mm minimum on small boards)
2. **Ground plane partitioning**: Separate analog and power ground planes, unified at single low-impedance star point only
3. **Trace routing hierarchy**: Power → Ground → Analog signals → Digital signals (in priority order)
4. **Ferrite + filter**: Series ferrite bead + 100nF cap on EVERY encoder VCC input
5. **Shield grounding**: Encoder cable shields **single-point** grounded at board entry, NOT floating

---

## 2. Ground Plane Strategy (CRITICAL for EMI Control)

### 2.1 Two-Layer Board Ground Architecture

**Scenario**: 120mm × 80mm double-sided pertinax (like evka_position)

```
┌─────────────────────────────────────────────────────┐
│ TOP LAYER                                           │
│                                                      │
│  [SMPS Zone]   [ENCODER ZONE]   [MCU ZONE]         │
│   Switching    Signal cond.     GPIO interface      │
│   nodes        with ferrites     and decoupling      │
│   adjacent to  away from         near ESP32          │
│   coils        SMPS             VIN & GND           │
│                                                      │
│  Traces: power (thick) > signals (medium) >LED(thin)│
│                                                      │
└─────────────────────────────────────────────────────┘
         │                    │                │
         │ Vias (wide GND)   │ Vias (wide GND)│ Vias (wide GND)
         │ every 10-15mm     │ every 15-20mm  │ every 10-15mm
         ↓                   ↓                ↓
┌─────────────────────────────────────────────────────┐
│ BOTTOM LAYER (GROUND PLANE - PRIMARY CURRENT RETURN)
│                                                      │
│  ┌──────────────────────────────────────────────┐   │
│  │                                               │   │
│  │  SOLID GND fill with vias connecting top     │   │
│  │  traces. Wide traces (3-5mm) for:            │   │
│  │                                               │   │
│  │  • SMPS ground (from MT3608 GND pads)        │   │
│  │  • Encoder connector grounds (J1-J3 GND)     │   │
│  │  • ESP32 GND (from U1 header)                │   │
│  │  • Power section GND (Q1, D1, D2)            │   │
│  │                                               │   │
│  │  All converge to STAR POINT near C1 bulk cap │   │
│  │                                               │   │
│  └──────────────────────────────────────────────┘   │
│                     ↓                               │
│               STAR POINT (0V reference)             │
│               at C1 (220μF) junction                │
│                                                      │
└─────────────────────────────────────────────────────┘
```

### 2.2 Star Point Design

**Location**: Bottom layer, centered near C1 (220μF bulk capacitor)

```
From top layer, create 4-5 wide (3-5mm) ground bus traces
converging radially to the star point:

          SMPS Ground ─┐
                       ├─ STAR POINT
    Encoder Ground ─┤  (0V reference)
                       ├─ [C1 GND Pad]
       ESP32 Ground ─┤
                       └─ Power section return
      Signal GND ─┐
```

**Why this works:**
- Single point eliminates ground loops
- Large contact area at star point reduces loop inductance
- Wide radial traces (3-5mm) minimize voltage drops (~10mΩ at 1A)
- Encoder signals "see" consistent 0V reference everywhere

### 2.3 Avoid Ground Plane Splits (Common Mistake #1)

❌ **BAD**: Partitioned ground planes with small coupling area
```
                │ GAP or small coupling area
    ┌──────────┼──────────┐
    │ SMPS GND │ SIGNAL GND│
    │  plane   │  plane    │ ← Currents must pass through few vias
    └──────────┼──────────┘
         ↓
    High ground impedance → encoder noise coupling
```

✅ **GOOD**: Unified ground plane with strategic separation of high-current paths
```
    ┌──────────────────────────────────┐
    │   SINGLE GROUND PLANE             │
    │   (entire bottom layer copper)    │
    │                                   │
    │   ┌─────────────────────────────┐ │
    │   │ Use wide traces (3-5mm)      │ │
    │   │ to separate high-current     │ │
    │   │ SMPS return from sensitive   │ │
    │   │ signal return paths          │ │
    │   │ (not plane islands)          │ │
    │   └─────────────────────────────┘ │
    └──────────────────────────────────┘
         ↓
    Unified return, reduced noise coupling
```

---

## 3. Switching Node Isolation

### 3.1 SMPS Switching Node Location (MT3608 Boost Example)

**Switching node**: High-frequency (500kHz typical) current path between MOSFET and inductor.

```
Safe zone for SMPS:

┌────────────────────────────────────────────────────────────┐
│                                                            │
│  ┌─────────────────────────────────────────────────────┐  │
│  │ [SMPS ZONE — Top Left Corner]                       │  │
│  │                                                     │  │
│  │  TP4056 OUT+ ── C13 (10μF) ── MT3608 VIN          │  │
│  │                                 │                  │  │
│  │                            Switching node          │  │
│  │                            (high dI/dt current)    │  │
│  │                            ↓                       │  │
│  │                            [Inductor coil]         │  │
│  │                            (keep away from signals)│  │
│  │                                 │                  │  │
│  │  GND ──────────────── MT3608 GND ──── D2 anode    │  │
│  │                                                     │  │
│  │  Distance from encoder J1-J3: ≥ 60mm              │  │
│  │  ‾‾‾‾‾‾‾‾‾‾‾‾‾‾‾‾‾‾‾‾‾‾‾‾‾‾‾‾‾                │  │
│  └─────────────────────────────────────────────────────┘  │
│                                                            │
│  ┌─────────────────────────────────────────────────────┐  │
│  │ [ENCODER ZONE — Bottom Left]                        │  │
│  │                                                     │  │
│  │  J1 (Wire)  ── FB1 ── 100nF ── dividers          │  │
│  │  J2 (Phi)   ── FB2 ── 100nF ── dividers          │  │
│  │  J3 (Theta) ── FB3 ── 100nF ── dividers          │  │
│  │                                                     │  │
│  │  Traces routed AROUND SMPS zone (right side)      │  │
│  │  ‾‾‾‾‾‾‾‾‾‾‾‾‾‾‾‾‾‾‾‾‾‾‾‾‾‾‾‾‾‾‾‾              │  │
│  └─────────────────────────────────────────────────────┘  │
│                                                            │
└────────────────────────────────────────────────────────────┘
```

### 3.2 Minimum Separation Distances

| Component Pair | Min. Distance | Reason |
|---|---|---|
| SMPS switching node ↔ encoder A/B signals | 60-100mm | Minimize magnetic coupling |
| MT3608 inductor ↔ signal dividers | 50mm | Radiated EMI from L di/dt |
| SMPS GND return ↔ encoder signal GND | 40mm (separate traces) | Avoid common impedance |
| MOSFET drain ↔ shielded encoder cable | 30-50mm | Precaution against dV/dt noise |

### 3.3 Inductor Orientation & Placement

```
DO:
  ✓ Place inductor coil centered in SMPS zone
  ✓ Orient coil axis perpendicular to signal traces
  ✓ Wrap a grounded Faraday cage (thin Cu mesh or shield can) around inductor
    if space permits (not mandatory for small boards)

DON'T:
  ✗ Place inductor adjacent to encoder input connectors
  ✗ Route signal traces directly above/below inductor
  ✗ Orient coil axis parallel to encoder cables
```

---

## 4. Signal Trace Routing Best Practices

### 4.1 Trace Separation Matrix

```
Signal Type              Min. Gap    Layer Rule          Notes
─────────────────────────────────────────────────────────────────────
Encoder Phase A/B        0.5mm       Same side (top)     Adjacent traces OK if diff-pair routed
Encoder Z-index          0.5mm       Same side (top)     Separate from Phase A/B by gap
5V_RAIL (power)          1.5mm       Mixed layers        Top layer thick (2mm), keep away from signals
GND traces (return)      1.0mm       Bottom (primary)    Wide traces (3-5mm) converge to star point
ESP32 GPIO (input)       0.5mm       Top layer           Short, direct routes from divider junctions
```

### 4.2 Router Order (Implement in this sequence)

**Priority 1 — Power (highest impedance critical)**
1. 5V_RAIL from D1/D2 junction → C1 bulk cap location (2mm trace, top layer)
2. 5V_RAIL branch to each zone load (1-1.5mm branches)
3. Ferrite bead + 100nF cap at each encoder VCC input

**Priority 2 — Ground (lowest impedance critical)**
1. Bottom layer: wide (3-5mm) GND traces from all sections → star point
2. Vias (0.8-1.0mm) placed every 10-15mm along power GND traces
3. Encoder connector GND pins → bottom-layer wide trace → star point

**Priority 3 — Analog signals (sensitive)**
1. Divider output junctions → ESP32 GPIO inputs (0.5mm traces, top layer)
2. Signal traces routed on OPPOSITE SIDE of board from SMPS switching node
3. Every signal trace has dedicated return path via bottom-layer GND (use vias at ends)

**Priority 4 — Digital / Low-critical**
1. LED, button, test points (route last)

### 4.3 Trace Routing Topology for Encoder Signals

```
Incoming encoder signal (5V TTL):
           ↓
    [J1/J2/J3 connector] — single-point GND shield
           ↓ (parallel traces, 0.5mm spacing minimum)
           │
      ┌────┴────┐
      │  Ferrite bead (600Ω@100MHz)
      │  + 100nF decap
      └────┬────┘
           │
      [Voltage Divider] ← R_top (10k) ├─ R_bot (20k) ├─ GND
           │                           │
      [1nF filter cap]  ────────────────┤
           │                           │
      [TVS diode (1.5KE3.3CA)] ─────────┼─ GND
           │
      [ESP32 GPIO input] ← direct trace, 0.5mm width, 40-60mm length

VIA STRATEGY:
  • Via near divider junction → GND (top of divider network)
  • Via near TVS cathode → GND (return path for protection)
  • Via near GPIO pin → GND (reference for input signal)
  → Each via placed 5-10mm from its component, converges to GND plane
```

---

## 5. Ferrite Bead + Filter Configuration

### 5.1 Encoder VCC Input Filter (CRITICAL for EMI mitigation)

```
5V_RAIL ──┬── Ferrite bead ──┬── 100nF cap ──┬── GND
          │  (600Ω@100MHz)   │  (ceramic)     │
          │  (0.1Ω DC)       │  (Y5V or X7R)  │
          │  [AXE-FB603-600] │                │
          │                  │                │
          └──────────────────┼── VCC pin (J1/J2/J3)
                             │
                        Encoder supply,
                        decoupled from SMPS noise
```

### 5.2 Why Ferrite + Filter Works

| Component | Purpose | Specifications |
|---|---|---|
| **Ferrite bead** | High-Z path for switching noise (500kHz+), low-Z for DC/slow transients | 600Ω @ 100MHz, <0.1Ω DC resistance |
| **100nF ceramic** | Local charge reservoir, C0G/NP0 dielectric (stable, no aging) | 100nF ± 10%, rated ≥10V |

**Impedance curve** (ferrite bead):
```
Z (Ω)
│
│  ┌────┐
│  │    └────┐
│  │         │
│  │         └─────────────
│  │
└──┴──────────────────────── f (Hz)
   DC    100Hz  1kHz  100kHz  500kHz
   
   Low-impedance   →   Medium Z  →   High-impedance
   for DC power        for mid-freq   for SMPS noise
```

### 5.3 Placement Rules

```
TOP LAYER:

5V_RAIL ── [FB bead] ──── [100nF cap] ──┬── Encoder VCC pin
           ↑               ↑              │
       Compact layout   Close to connector
       (within 5mm)                      
                                         ↓ [Encoder module]

BOTTOM LAYER:

GND ─────────────────────── [100nF cap GND] ──┬── Encoder GND pin
                            │                  │
                         VIA to star point  VIA to connector

Result: Encoder sees clean 5V supply, decoupled from SMPS transients.
```

---

## 6. Digital Signal Routing Near SMPS

### 6.1 Separation Strategy: "Fast Side vs. Noisy Side"

```
BOARD LAYOUT PARTITION:

┌────────────────────────────────────┐  120mm
│                                    │
│  ┌──────────────────────────────┐  │
│  │ SMPS Zone (Top-Left)         │  │  80mm
│  │ • MT3608 module              │  │
│  │ • Switching node area        │  │
│  │ • Inductor coil              │  │
│  │ • High dI/dt currents        │  │
│  └──────────────────────────────┘  │
│                                    │
│  ↕ [QUIET CORRIDOR — 40mm buffer] ↕
│                                    │
│  ┌──────────────────────────────┐  │
│  │ SIGNAL + MCU Zone (Bottom)    │  │
│  │ • Encoder connectors J1-J3    │  │
│  │ • Voltage dividers            │  │
│  │ • ESP32 GPIO pins             │  │
│  │ • Low noise digital signals   │  │
│  └──────────────────────────────┘  │
│                                    │
└────────────────────────────────────┘
```

### 6.2 Trace Routing Rules in Signal Zone

**When encoder signals MUST pass near SMPS:**

1. **Minimum clearance**: 30-40mm from SMPS switching node
2. **Trace width**: Keep signal traces narrow (0.5mm) to reduce loop area
3. **Layer preference**: Route signals on TOP layer (farther from GND plane below)
4. **Via placement**: Use vias ONLY where absolutely necessary (at component pads)
5. **Ground fill**: Ensure continuous GND plane on BOTTOM layer under signal zone

### 6.3 Differential-Pair Routing (Optional Improvement)

For encoder signals in electrically noisy environments, consider differential pairing:

```
NOT recommended for simple 3-encoder system, but if needed:

Standard routing:
  Ph.A ────┬──────── GPIO
           │ 0.5mm gap
  Ph.B ────┴──────── GPIO

Differential routing (future-proof):
  Ph.A ────┬──────── GPIO   ← routed as twisted pair with ground
           │ 0.2mm gap      ← matched length, opposite edges
  Ph.B ────┴──────── GPIO   ← common-mode noise cancellation

Length matching: |A - B| < 5% of shortest signal wavelength
(not critical for ≤15kHz encoder signals)
```

---

## 7. EMI Shielding Strategies

### 7.1 Encoder Cable Shielding (Primary Defense)

```
SHIELDED ENCODER CABLE:
┌─────────────────────────────────┐
│ 4-conductor twisted pair        │
│ (Phase A, Phase B, Power, GND)  │
│ ─────────────────────────────   │
│ with outer Cu mesh shield       │
│ (spiral wrap or braided)        │
└─────────────────────────────────┘
        ↓
   Encoder connector
        │
        J1/J2/J3
        │
        ├─ Shield wire (connect to PCB GND AT CONNECTOR ONLY)
        ├─ Power (5V)
        ├─ GND
        ├─ Phase A signal → divider network
        └─ Phase B signal → divider network
```

**Critical rule**: Shield terminates at ONE point (board entry). 
**Never** float the shield or connect it to signal GND intermediate points.

```
CORRECT:

    ┌─────────────────┐
    │ Encoder module  │
    │ (remote site)   │
    └────────┬────────┘
             │ shielded cable (30ft max)
             │ ┌─ Ph.A
             │ ├─ Ph.B
             │ ├─ +5V
             │ ├─ GND
             │ └─ Shield
             ↓
        J1 connector
        │
        ├─ Ph.A ──→ divider ──→ GPIO
        │
        ├─ Ph.B ──→ divider ──→ GPIO
        │
        ├─ +5V ──→ ferrite ──→ 5V_RAIL
        │
        ├─ GND ──→ [BOARD GND PLANE]
        │
        └─ Shield ──→ [BOARD GND PLANE, SAME POINT as GND pin]
                      (single-point termination)
```

**WRONG** (floating or multi-point shield grounding):
```
❌ Shield floats → acts as antenna, picks up SMPS noise
❌ Shield connected to signal ground (different from power GND) → ground loop
❌ Shield connected at multiple points → ground loop currents add noise
```

### 7.2 PCB-Level Shielding (Advanced)

**If encoder signals are routed over long distances on PCB:**

```
OPTION A: Guard traces
  
  Signal trace ──→ [Sensitive divider area]
  Guard trace (GND) ┤ parallel on both sides, 1mm gap
  Guard trace (GND) ┤

OPTION B: Faraday cage (small shielded chamber)

  ┌──────────────────────┐
  │ Cu box (0.2mm wall)  │
  │                      │
  │  ┌────────────────┐  │
  │  │  Divider       │  │
  │  │  networks x3   │  │
  │  └────────────────┘  │
  │                      │
  │  (connected to GND)  │
  └──────────────────────┘
  
  → Not practical on hand-soldered board; skip for evka_position.
```

### 7.3 EMI from Switching Node

**Problem**: MT3608 switching node (500kHz, 1-2A transients) radiates high-frequency noise.

```
┌─────────────────────────────────────────────────────────┐
│ SWITCHING NODE NOISE COUPLING PATH                      │
│                                                         │
│  MT3608 MOSFET switching ─┐                            │
│  (500kHz, ~1A di/dt)       │                            │
│                           ├─→ Magnetic field            │
│  ↓                        │    (spreads ~50-100mm)      │
│                           │                            │
│  Nearby signal traces ◄────┘    (capacitive + inductive)│
│  (encoder divider A/B)                                 │
│  ↓                                                      │
│  Induced noise: 100-500mV spikes at 500kHz              │
│  (can corrupt slow encoder signals!)                   │
│                                                         │
└─────────────────────────────────────────────────────────┘
```

**Mitigation**:
1. **Distance** (primary): Place SMPS zone 60-100mm from encoder zone
2. **Ferrite + filter** on encoder VCC (prevents noise coupling via power rail)
3. **1nF filter cap** on signal divider (RC corner at ~25kHz attenuates 500kHz noise)
4. **TVS diode** clamps any transients that sneak through

---

## 8. Capacitor Placement & Decoupling

### 8.1 Bulk Capacitor at Star Point

```
┌─ 5V_RAIL (from D1/D2)
│
├─ C1 (220μF, 10V, electrolytic)
│  └─ GND ─────→ [STAR POINT on bottom layer]
│
├─ C2 (100nF, ceramic, C0G/X7R) ─ placed within 2cm of C1
│  └─ GND ─────→ [STAR POINT]

PLACEMENT (top layer):
  Near junction of J4/J6 (external power input area)
  or MT3608 output area (battery power)
  
  C1 & C2 share same GND via → star point
  Minimizes loop inductance.
```

### 8.2 Encoder VCC Decoupling

```
Per encoder (x3 total: J1, J2, J3):

5V_RAIL ── Ferrite ── [100nF] ── VCC pin
                        │
                       GND via (short, <5mm trace) → bottom GND plane

Placement: Capacitor mounted AT CONNECTOR, not remote.
```

### 8.3 Signal Divider Decoupling (1nF Filter Caps)

```
Per divider network (x7 total):

  10kΩ (R_top)
     │
     ├── [1nF, C0G/NP0] ── GND
     │
  20kΩ (R_bot)
     │
    GND

Placement: 1nF cap soldered directly at divider junction,
           1mm trace to GND via.

Purpose: Attenuate 500kHz SMPS noise, allow encoder signals
         (max 15kHz) to pass cleanly.
```

### 8.4 MT3608 Input Decoupling

```
TP4056 OUT+ ── [10μF, 10V] ── MT3608 VIN
              │ (electrolytic)
             GND
             
Placement: At MT3608 input pad (close), GND via to bottom plane.
Purpose: Stabilize boost converter input, prevent voltage spikes.
```

---

## 9. Layer Stack & Via Strategy

### 9.1 Via Placement Checklist

| Location | Via Size | Spacing | Purpose |
|---|---|---|---|
| Power GND traces (bottom) | 0.8-1.0mm | Every 10-15mm | Low-impedance ground return |
| Signal divider GND | 0.8mm | At component pad | Minimize loop area |
| TVS diode GND | 0.8mm | Adjacent | Direct path to plane |
| Encoder connector GND | 1.0mm | At pad | Primary ground entry |
| Decap GND (100nF, 1nF) | 0.8mm | Directly under pad | Short return path |

### 9.2 Thermal Vias (Optional)

**If SI2301 P-MOSFET dissipates significant power** (unlikely in RPP circuit):

```
SI2301 GND pad (SOT-23) ── 2-4 vias (0.8mm) → bottom GND plane
                           (spread around pad)
                           
Dissipation: ~0.25W max (5V × 50mA at low Vds) → negligible heat.
Thermal vias: Not required, but good practice if space available.
```

---

## 10. Practical Assembly Sequence for Co-Located SMPS + Encoders

### Phase 1: Power Section & SMPS
1. Solder D1 (SS34) and Q1 (SI2301) with short leads to C1/C2 GND star point
2. Mount MT3608 module, TP4056 module
3. Create bottom-layer GND traces from all power components → star point
4. Verify 5V_RAIL: ~5.0-5.1V at TP1

### Phase 2: Encoder VCC Filters
1. Solder ferrite bead (FB1, FB2, FB3) on encoder VCC paths
2. Solder 100nF decap immediately after each ferrite (at connector area)
3. Route VCC traces to connector pads (short, wide if possible)

### Phase 3: Signal Conditioning
1. Solder J1, J2, J3 connectors
2. Solder voltage divider networks (10k/20k resistors, 1nF caps)
3. Solder TVS diodes (1.5KE3.3CA)
4. Route signal traces to ESP32 GPIO pins (long, thin, far from SMPS)

### Phase 4: MCU & Testing
1. Solder ESP32 female header strips
2. Connect 5V_RAIL and GND to ESP32 VIN/GND
3. Program ESP32, test each encoder individually
4. Verify no noise on encoder signals (use oscilloscope if available)

### Test Checkpoint: Noise Measurement

```
Setup:
  • Oscilloscope probe on encoder signal divider output (before GPIO)
  • SMPS under load (e.g., 5V rail driving LEDs or test resistor)
  • Encoder rotating or static

Expected:
  ✓ Clean digital waveform, 0-3.3V
  ✓ Rise time <50μs
  ✓ No visible high-frequency ripple (>100mV spikes = problem)
  
If noisy:
  1. Check ferrite bead is soldered (not loose)
  2. Verify 100nF cap is close to connector
  3. Increase distance between SMPS and signal zone (if physically possible)
  4. Re-solder GND vias near encoder zone
```

---

## 11. Common Mistakes & Fixes

### Mistake #1: Partitioned Ground Planes

❌ **Problem**: Separate "analog" and "digital" ground planes with only small coupling area.
```
    ┌─────────────┬─────────────┐
    │ SMPS GND    │ SIGNAL GND  │
    │  plane      │  plane      │
    └─────────────┴─────────────┘
           ↑ narrow coupling (2-3 vias)
    
    Result: High ground impedance → noise injection into encoder signals
```

✅ **Fix**: Single unified ground plane with wide separation traces
```
    ┌─────────────────────────────┐
    │  SINGLE GND PLANE           │
    │                             │
    │ ┌───────┐      ┌─────────┐  │
    │ │ GND   │ wide │ GND     │  │
    │ │return │ trace│ return  │  │
    │ │SMPS   │──    │SIGNAL   │  │
    │ └───────┘      └─────────┘  │
    │        ↓                     │
    │    STAR POINT               │
    └─────────────────────────────┘
    
    Result: Low impedance, noise confinement via trace resistance
```

### Mistake #2: Long Signal Traces with No Ground Return

❌ **Problem**: Encoder A/B signals routed far from GND layer/traces; loop area → pick up SMPS radiation
```
    Signal trace ──────────── [60mm] ──────────── GPIO
    
    GND return (bottom layer) ══ far away ════════ GPIO GND

    Result: Large loop area (60mm × 2mm height = 120mm²)
            Inductance ~10-50nH → induced noise
```

✅ **Fix**: Via placed near GPIO input; short ground return
```
    Signal trace ──────────── [20mm] ──→ GPIO
    GND return via        ─────────────→ GND plane
    (5mm from signal trace, tightly coupled)
    
    Result: Small loop area (<50mm²) → minimal noise pickup
```

### Mistake #3: Floating Encoder Cable Shield

❌ **Problem**: Shield wire not connected, or connected to wrong GND point
```
    Shielded encoder cable
    ├─ Ph.A → divider
    ├─ Ph.B → divider
    ├─ +5V → ferrite
    ├─ GND → board GND
    └─ Shield → FLOATING (not connected!)
    
    Result: Shield acts as antenna, couples SMPS noise into signal wires
```

✅ **Fix**: Shield grounded at board entry, same point as GND pin
```
    Shielded encoder cable
    ├─ Ph.A → divider
    ├─ Ph.B → divider
    ├─ +5V → ferrite
    ├─ GND ──┐
    └─ Shield┴─→ [Single GND point at J1-J3]
    
    Result: Shield terminates shield current, prevents noise loop
```

### Mistake #4: Ferrite Bead Omitted or Wrong Value

❌ **Problem**: SMPS high-frequency noise couples directly onto encoder VCC
```
    5V_RAIL ──────── (no ferrite) ──── [Encoder VCC]
    
    500kHz noise rides into encoder power supply.
    Coupled to signal dividers via parasitic capacitance.
    Result: Encoder jitter, missed pulses.
```

✅ **Fix**: 600Ω ferrite + 100nF cap at encoder connector
```
    5V_RAIL ── [600Ω ferrite @ 500kHz] ── [100nF] ── [Encoder VCC]
    
    Ferrite blocks 500kHz noise (high-Z path)
    Capacitor provides local clean 5V
    Result: Encoder sees <50mV ripple @ 500kHz
```

### Mistake #5: 100nF Cap Too Far from Encoder

❌ **Problem**: Capacitor in middle of board, traces to connector long
```
    [100nF cap somewhere on board] ──[long wire]── Encoder VCC
    
    Long trace = series inductance → defeats decoupling
```

✅ **Fix**: Capacitor located AT CONNECTOR
```
    Ferrite [FB] ── [100nF cap] ── [Encoder VCC pin (J1)]
                    └─────────────── direct GND connection
                    (within 1cm)
    
    Minimized loop inductance → effective decoupling
```

---

## 12. Summary: Design Checklist

Before PCB layout, verify:

- [ ] **Ground plane unified** (single plane with wide separation traces, not islands)
- [ ] **Star point defined** (central location, typically near bulk cap)
- [ ] **SMPS zone isolated** (60-100mm from encoder zone, switching node identified)
- [ ] **Ferrite + filter on each encoder VCC** (600Ω ferrite, 100nF ceramic, at connector)
- [ ] **Signal traces routed away from SMPS** (on opposite board area, 30-40mm min separation)
- [ ] **Encoder cable shield single-point grounded** (at board entry, same GND as power)
- [ ] **Vias strategically placed** (every 10-15mm on GND traces, at component pads)
- [ ] **Decoupling caps close to supply points** (C1/C2 at star, 100nF at connectors, 1nF at dividers)
- [ ] **Trace width hierarchy** (5V_RAIL: 2mm, encoder VCC: 1mm, signals: 0.5mm, GND: 3-5mm)
- [ ] **Test points accessible** (TP1: 5V_RAIL, TP5: GND, for noise measurement)

---

## 13. Reference: evka_position Configuration

**Current PCB**: 120mm × 80mm double-sided pertinax (hand-soldered through-hole)

**SMPS**: MT3608 boost converter (3.7V LiPo → 5.3V, 500kHz switching, <100mA typical)

**Encoders**: 3x quadrature + Z-index (E40S6 rotary, DWEM2 draw-wire)
- Max signal frequency: ~15kHz (at 20kHz encoder PPR, 750 RPM max)
- Signal levels: 0-5V TTL → 0-3.3V after divider

**Applied best practices**:
1. ✓ Unified ground plane (bottom layer entirely copper)
2. ✓ Star point near C1 (220μF bulk cap)
3. ✓ SMPS (MT3608 module) in top-left zone
4. ✓ Encoder section (J1-J3, dividers) in bottom-left zone, separated by ~60mm
5. ✓ Ferrite + 100nF at each encoder VCC input
6. ✓ Wide GND traces (3-5mm) on bottom layer converging to star point
7. ✓ Signal traces routed via right side of board, away from SMPS
8. ✓ TVS diodes (1.5KE3.3CA) at divider junctions for ESD protection

---

## 14. References & Standards

- **IEC 61000-4-6**: RF immunity testing (useful for understanding EMI threats)
- **IPC-A-610**: PCB assembly quality (via placement, trace width, spacing)
- **EDN**: "PCB Layout for Switching Power Supplies" (practical guidance)
- **MT3608 datasheet**: Section 5 (PCB layout recommendations)

---

**Document Version**: 1.0  
**Last Updated**: 2026-04-05  
**Applied to**: evka_position encoder + buck/boost SMPS integration  
**Status**: Verified on hand-soldered pertinax board with 3x encoders + MT3608 + TP4056

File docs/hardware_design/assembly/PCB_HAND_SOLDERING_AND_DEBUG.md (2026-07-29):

# PCB Hand Soldering, Testing & Debug Guide
## ESP32 Encoder Board with Buck Converter

---

## 1. Hand Soldering Tips — Through-Hole Components on Pertinax

### Best Practices
- **Tin your iron tip** frequently with fresh solder (60/40 or lead-free compatible with your board)
- **Heat both the pad and component lead** simultaneously for 2–3 seconds before applying solder
- **Use a damp natural sponge** (not brass wire cleaner—it removes too much tin) to clean your tip
- **Minimum solder joint = shiny, cone-shaped fillet** from pad to lead; avoid dull/grainy appearance
- **Work in a ventilated area** and use solder with rosin core (flux is essential)
- **Temperature:** 350–375°C iron tip for lead-free solder; 320–350°C for 60/40

### Ferro Beads & Decoupling Caps
- **Heat ferrite bead both sides** (0603 or axial) before applying solder—they dissipate heat
- **100nF ceramic caps on encoder signal lines** should be soldered quickly (these are small); use a narrow iron tip
- **Capacitors on power rails** (C1 220μF, C2 100nF at 5V_RAIL junction) are most critical—extra flux helps

### Voltage Dividers (Most Common Weak Point)
- **Two resistors per divider** create multiple joints—solder each resistor lead separately
- **Don't rush:** Apply flux to each pad, heat 2–3 seconds, then add solder
- **Common error:** Insufficient heat → cold joint (dull, grainy, unreliable)
- **Test immediately after soldering:** Probe GPIO with multimeter; should measure 0V or 3.3V when encoder powered

---

## 2. Common Mistakes in 12V ESP32 Encoder Boards

### Power & Protection
| Mistake | Consequence | Fix |
|---|---|-----|
| **DC jack polarity reversed** | Reverse voltage through ESP32, magic smoke | Double-check jack pin labeling (red=+, black/stripe=−); use multimeter before connecting power |
| **Missing reverse polarity MOSFET (Q1)** | No protection; any polarity error kills board | Verify Q1 (AO3401A) is soldered between J4 and 5V_RAIL; test with reversed polarity before powering ESP32 |
| **5V_RAIL cap not soldered flush** | Intermittent crashes, brownouts on load spikes | Ensure C1 (220μF) and C2 (100nF) are soldered solid; probe them with multimeter at 5V after power-on |
| **Ground star point floating** | Noise, encoder counts erratic, Wi-Fi dropout | Verify all GND traces converge at ONE point near C1; use multimeter continuity on all GND leads |
| **Battery modules (TP4056/MT3608) swapped or backwards** | Short circuit, module damage, 5V loss | Verify polarity markings on module silk-screen before soldering; test with standalone module first if unsure |

### Signal Conditioning (Most Critical)
| Mistake | Consequence | Fix |
|---|---|-----|
| **Missing voltage divider on encoder signals** | 5V directly to ESP32 GPIO → internal ESD diode damage, counts miss/misread | Verify all 7 dividers (R1/R2, R3/R4, R5/R6, R7/R8, R9/R10, R11/R12, R13/R14) are present and soldered; measure GPIO voltage: should be ≤3.3V when encoder HIGH |
| **Wrong resistor values in dividers** | GPIO sees 4V+ or only 1V → register as 1 but miss 0s (or vice versa) | Verify values with multimeter or visual inspection; 10k/20k is standard (other combos possible but measure GPIO voltage carefully) |
| **Ferrite beads forgotten** | EMI coupling into signal lines; encoder counts become chaotic with Wi-Fi enabled | Confirm FB1, FB2, FB3 are present on encoder power leads; single bead after screw terminal, before divider network |
| **Signal trace too long or unshielded** | Capacitive coupling from 5V_RAIL or adjacent traces; jitter in quadrature | Route signal traces short & direct from divider junction to ESP32 GPIO; keep traces on top layer if possible; avoid parallel runs |
| **TVS diodes missing or wrong polarity** | No ESD protection; board dies after first cable touch-up | Verify 7x TVS diodes (1.5KE3.3CA) are soldered at each divider output-to-GPIO junction; check cathode band faces GPIO side |

### Encoder Connectors
| Mistake | Consequence | Fix |
|---|---|-----|
| **Screw terminals loose** | Intermittent contact, random encoder dropouts mid-test | Tighten all 3 connectors. v4 order is J1=Wire, J2=Phi, J3=Theta; pull connector off, re-seat, re-tighten. |
| **Encoder wires reversed in connector** | Counts go backwards; worse, A/B swapped creates invalid quadrature | Verify PCB-derived v4 order: Wire A→J1.1, GND→J1.2, B→J1.3, +5V→J1.4; Phi +5V→J2.1, A→J2.2, GND→J2.3, B→J2.4; Theta A→J3.1, GND→J3.2, B→J3.3, +5V→J3.4. Physically reverify before power. |
| **Common ground not connected at board edge** | Encoder floating GND; quadrature counts unreliable | Ensure encoder GND wire connects to J1/J2/J3 GND pin; measure continuity from encoder GND to board GND star point |

### ESP32 Mount & Headers
| Mistake | Consequence | Fix |
|---|---|-----|
| **ESP32 header pins soldered wrong order** | GPIO numbering incorrect; all encoders fail or intermix | Verify header orientation: v4 uses GPIO 7/8 for Wire, 4/5 for Phi, 9/10 for Theta; test with `pio device monitor` and check boot messages |
| **VIN/GND swapped on ESP32** | No power to ESP32 or backwards polarity | Probe VIN pad with multimeter: should be 5V ±0.2V; GND should be 0V; if backwards, LED1 won't light |
| **USB cable too short or damaged** | Serial upload fails; cannot debug | Use proper USB micro-B cable; test with known-good cable first; if upload times out, hold BOOT → RESET → release BOOT, retry |

---

## 3. Testing Procedure for New PCB — Buck Converter + Encoder Interface

### Phase 0: Visual Inspection (Before Power-On)
```
□ Check all 7 voltage divider resistors are present (measure each with ohm-meter if soldered to board)
□ Verify C1 (220μF), C2 (100nF) at 5V_RAIL junction
□ Confirm Q1 (SI2301) + D1 (SS34) reverse polarity protection on DC jack path
□ Check all 3 connectors (J1, J2, J3) are soldered and tightened
□ Verify no solder bridges between adjacent traces (especially on dividers)
□ Confirm ESP32 headers are soldered straight and pins numbered correctly
□ Test point pins (TP1-TP5) should be soldered flush
□ Look for cold joints: dull/grainy solder—these fail randomly
```

### Phase 1: Power Section Test (No encoders, no ESP32 installed yet)

#### 1a. DC Jack Power Path
```bash
# Minimum required hardware:
# - C1 (220μF) and C2 (100nF) soldered at 5V_RAIL
# - D1 and Q1 soldered
# - All GND points wired to central star point
# - Reverse polarity MOSFET Q1 + gate resistor R19

# Apply 5V DC to J4 (red=+, black=−)
# Measure TP1 (should read 5V_RAIL)
# Measure TP5 (should read 0V = GND)
# Measure TP1 − TP5 = should be ~4.8–5.1V

Expected: LED1 lights up (green power LED)
```

#### 1b. Reverse Polarity Test (Critical for 12V boards)
```bash
# DO NOT install ESP32 yet
# Reverse the DC cable polarity (red ↔ black)
# Apply power

Expected: LED1 should NOT light; measure TP1 = 0V (protection working)
Reverse it back, power on → LED1 lights again

If LED1 lights on reversed polarity: Q1 or R19 not soldered or connected
```

#### 1c. Battery Module Test (if TP4056 + MT3608 installed)
```bash
# Connect LiPo battery to J5 (watch polarity!)
# Measure TP4 (LiPo +): should read ~3.7V (if battery is charged)
# Measure TP3 (MT3608 output, before D2): should read ~5.1V

# Optional: Verify auto-charge circuit
#   Connect USB to TP4056 module; measure TP3 again after 5 seconds
#   Should still be ~5V; D3 (1N5817) diode allows external 5V to back-charge

Expected: Both 5V_RAIL and battery paths work independently
```

### Phase 2: ESP32 Mount & Boot Test

#### 2a. Insert ESP32 into Headers
```bash
□ Power off board completely
□ Insert Wemos D1 R32 into female headers with USB port facing right/accessible
□ Ensure all pins are fully seated (no gaps between module and header)
□ Verify no bent pins or socket damage
```

#### 2b. First Power-On with Serial Monitor
```bash
# Set up serial monitor before power
pio device monitor -e wemos_d1_r32 --baud 115200

# Then power on the board
# Expected output within 2 seconds:
#   [0.000] ESP32-S3 (or WROOM-32)
#   [0.123] Starting SphericalSensor
#   [1.500] Zeroing encoders...
#   [2.000] Ready, awaiting commands

Measure TP2 (3.3V rail from ESP32): should read ~3.2–3.3V
```

#### 2c. Command Test (No encoders yet)
```bash
# Type into serial monitor: PING

Expected: 
  PONG

# Type: STATUS

Expected:
  THETA=0 PHI=0 WIRE=0 (all counts zero, 3.3V present)
```

### Phase 3: Individual Encoder Tests

#### 3a. Draw-Wire Encoder (DWEM2)
```bash
# v4: connect only draw-wire to J1; leave J2 and J3 unconnected
# Apply external 5V to encoder (see wiring in setup_test_guide.md)
# Upload v4 main firmware:
#   pio run -e esp32s3_v4 --target upload
#   pio device monitor -e esp32s3_v4

# Expected: DATA/SENSOR radius changes while pulling wire.

If COUNT = 0 always:
  □ Check GPIO 7/8 are receiving 0V/3.3V when encoder powered
  □ Verify external 5V supply is actually powering encoder
  □ Test voltage dividers with multimeter: 5V → ~3.3V at GPIO
```

#### 3b. Theta Rotary Encoder (E40S6)
```bash
# v4: connect only theta to J3; leave J1 and J2 unconnected
# Apply external 5V to encoder
# Upload v4 main firmware:
#   pio run -e esp32s3_v4 --target upload
#   pio device monitor -e esp32s3_v4

# Expected: DATA/SENSOR theta changes while rotating theta.

If THETA_counts = 0:
  □ Verify GPIO 9/10 toggling with multimeter (should see 0V/3.3V alternating)
  □ Check ferrite FB1 is not broken
  □ Confirm R1/R2 divider resistors are soldered
```

#### 3c. Phi Rotary Encoder (E40S6)
```bash
# Connect only phi to J2; leave J1 and J3 unconnected
# Apply external 5V to encoder
# Upload v4 main firmware:
#   pio run -e esp32s3_v4 --target upload
#   pio device monitor -e esp32s3_v4

# Expected: DATA/SENSOR phi changes while rotating phi.
```

### Phase 4: Full Integration Test

#### 4a. Connect All Three Encoders
```bash
# Wire all 3 encoders to their connectors (J1, J2, J3)
# Upload main firmware:
#   pio run -e wemos_d1_r32 --target upload

# Expected at boot:
#   [2.0s] Zeroing encoders...
#   [3.0s] DATA,0.0,0.0,0.0,0.0,0.0,0.0,1.0  (x=0, y=0, z=0 at home)

# Move robot axes:
#   - Pull draw-wire: z increases (mm)
#   - Rotate theta: x/y change, spherical angle theta changes
#   - Rotate phi: z component changes, spherical angle phi changes
```

#### 4b. Test ZERO Command
```bash
# Send: ZERO

Expected:
  [*] ZERO received
  [*] Spherical zero point set
  [*] Ready for motion

# Subsequent DATA frames should start from all zeros again
```

---

## 4. Debug Checklist for First Power-On

### If Board Does NOT Boot

**Symptom:** No serial output, LED1 not lit

| Check | Command / Method | Expected | Action if Failed |
|---|---|---|---|
| **5V_RAIL present** | Multimeter: TP1 to TP5 | ~5V | Check Q1 reverse polarity MOSFET; verify D1 is not reversed; test DC jack with reversed polarity (should block—see Phase 1b) |
| **3.3V rail present** | Multimeter: TP2 to TP5 | ~3.3V | ESP32 not receiving power from VIN; check VIN solder joint and trace from 5V_RAIL |
| **ESP32 USB detected** | `lsusb` on PC | "ESP32" or "USB UART" device | ESP32 not seated in headers; remove and re-insert with proper alignment; check USB cable |
| **ESP32 reset pin** | Multimeter between RST and GND | Voltage should toggle on press | Reset button not soldered or broken; tap button lightly to feel click |
| **Reverse polarity damage** | Visual inspection | No burnt components near Q1, D1 | If detected, MOSFET or diode failed during incorrect polarity insertion; replace Q1 and D1 |

### If Serial Monitor Shows Garbage

**Symptom:** Serial output is random characters, not recognizable text

| Check | Fix |
|---|-----|
| **Baud rate wrong** | Ensure monitor is 115200 baud: `pio device monitor -e wemos_d1_r32 --baud 115200` |
| **USB cable issue** | Try a different USB micro-B cable; known-good cable only |
| **ESP32 COM port wrong** | List ports: `ls /dev/ttyUSB* /dev/ttyACM*`; confirm correct port in upload |

### If Encoder Counts Stay Zero

**Symptom:** `COUNT=0` always, even when moving encoder

| GPIO | Encoder | Debug | Expected |
|---|---|---|---|
| **7** (Wire A) | Draw-wire A line | Multimeter to GPIO 7 while pulling wire | Toggle 0V ↔ 3.3V |
| **8** (Wire B) | Draw-wire B line | Multimeter to GPIO 8 while pulling wire | Toggle 0V ↔ 3.3V (opposite phase to GPIO 7) |
| **9** (Theta A) | Rotary A | GPIO 9 during rotation | Smooth quadrature pattern (1, 0 alternating) |
| **10** (Theta B) | Rotary B | GPIO 10 during rotation | 90° out of phase with GPIO 9 |
| **4** (Phi A) | Rotary A | GPIO 4 during rotation | Smooth quadrature pattern |
| **5** (Phi B) | Rotary B | GPIO 5 during rotation | 90° out of phase with GPIO 4 |

**If GPIO not toggling:**
1. Check encoder is powered (measure encoder +5V)
2. Verify common GND between encoder and ESP32 board
3. Probe *before* divider (at encoder cable): should see 5V swings
4. Probe *after* divider (at GPIO): should see 3.3V swings
5. If input is 5V but GPIO stuck at 3.3V or 0V: **divider resistor open or wrong value**

### If Encoder Counts Go Backwards

**Symptom:** Pulling wire decreases COUNT; rotating theta CW decreases counts

| Encoder | Fix |
|---|-----|
| Draw-wire (J1) | Swap A ↔ B wires on J1 terminal block |
| Theta (J3) | Swap A ↔ B wires on J3 terminal block |
| Phi (J2) | Swap A ↔ B wires on J2 terminal block |

### If Counts Jump Randomly

**Symptom:** COUNT increases/decreases by random amounts, not smooth transitions

| Cause | Check | Fix |
|---|---|-----|
| **Common GND missing** | Multimeter continuity from encoder GND pin to board TP5 | Solder encoder GND wire to J connector GND pad; verify continuity to main GND bus |
| **Loose screw terminal** | Wiggle each J1/J2/J3 connector | Tighten with small screwdriver; pull connector off and re-seat firmly |
| **Cold solder joint in divider** | Probe GPIO with meter while moving encoder; watch for sudden voltage dips | Re-heat and re-solder suspect divider resistor joints (dull/grainy appearance) |
| **Ferrite bead broken** | Visual inspection of FB1/FB2/FB3 | If cracked, replace ferrite bead |
| **Wi-Fi interference** | Disable Wi-Fi in firmware (`ENABLE_WIFI = 0`) | If counts stabilize, add shielding or move board away from router |

### If One Encoder Works but Others Don't

| Scenario | Likely Cause | Fix |
|---|---|-----|
| **Theta works, Phi doesn't** | Wrong GPIO or divider not soldered | Verify GPIO 4/5 are receiving correct voltage (multimeter); check the J2 divider parts. |
| **Wire works, both rotary encoders fail** | GPIOs 4/5/9/10 not connected or miswired | Re-check ESP32 header pins match silk-screen; use `STATUS`/serial output to confirm axis changes. |
| **Only one channel of rotary works** | One quadrature line missing | Verify both A and B wires are connected to J connector; measure both GPIO outputs |

### If Board Powers Off When Encoders Connected

**Symptom:** Supply current spikes; board resets

| Cause | Fix |
|---|-----|
| **Encoder drawing too much current** | External 5V supply undersized (use ≥500mA); verify LED1 is dim but on |
| **Short circuit in divider or connector** | Visual inspection for solder bridges between signal and GND pins; use multimeter continuity check between adjacent J connector pins |
| **External 5V supply poor quality** | Replace with known-good bench supply; verify 5V output is clean (oscilloscope if available) |

### If Battery Module Doesn't Charge

**Symptom:** Multimeter shows 0V on TP3 (MT3608 output) or TP4 (battery) always

| Check | Expected | Action |
|---|---|---|
| **TP4056 module powered** | Multimeter TP1 (5V_RAIL) = 5V | If 0V, fix 5V_RAIL first (Phase 1a) |
| **Battery connected** | Multimeter TP4 (battery +) = 3.7–4.2V | Confirm JST-PH connector J5 is soldered and battery is inserted |
| **MT3608 module output** | Multimeter TP3 should read ~5V when LiPo connected | If 0V: MT3608 module may be defective; test in isolation on bench power |
| **Auto-charge diode D3** | Multimeter: apply 5V to J4, measure TP3 | Should read ~5V; if not, D3 may be reversed or failed |

---

## 5. Final Validation Checklist

```
□ All 3 encoders report correct counts in both directions
□ ZERO command resets all counters reliably
□ Serial output stable at 115200 baud, no dropouts
□ No voltage spikes or oscillation on 5V_RAIL (scope)
□ All test points (TP1-TP5) accessible and labeled
□ Board operates with battery power (if TP4056/MT3608 present)
□ Reverse polarity protection tested (reversed DC jack → no damage)
□ Wi-Fi connection stable (if ENABLE_WIFI=1)
□ Temperature measurement stable on thermistor (if present)
□ No audible buzzing or clicking from regulators
□ LED1 (power) and LED2 (battery low, if present) work correctly
```

---

## References

- **Individual Hardware Test Plan:** `docs/hardware_design/assembly/individual_hardware_test_plan.md`
- **Setup & Test Guide:** `docs/integration/setup_test_guide.md`
- **PCB Layout Guide:** `docs/hardware_design/5v/pcb_layout_guide.md`
- **Reverse Polarity Protection:** `docs/hardware_design/assembly/REVERSE_POLARITY_PROTECTION.md`
- **Bill of Materials:** `docs/hardware_design/5v/bill_of_materials.md`

---

*Last Updated: 2026-04-05*
*Firmware Version: SphericalSensor v2.0+*
*Target Hardware: ESP32 Wemos D1 R32 on pertinax board*

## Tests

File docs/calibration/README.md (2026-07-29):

# Calibration Pack — Encoder Hardware

This folder contains repeatable calibration artifacts for the three encoder
subsystems used by `evka_position`.

## Current Stop Condition

Theta count loss is unresolved. A recorded repeatability session reached about 1.1 degrees of
theta return error, roughly 35 mm at 2 m. Do not change PPR or fit/copy a world transform to hide
lost counts, slip, or backlash. Resolve and repeat the theta test first.

There is no accepted endpoint/world transform and no shared/default calibration JSON is checked in.
`tools/evka_gui` remains sensor-frame-only. After both report gates pass, a session JSON may be
supplied explicitly to the legacy visualizer only; this opt-in use is not project acceptance.

## Calibration Sequence (run in this order)

1. Draw-wire (`r`) calibration
2. Theta rotary calibration
3. Phi rotary calibration
4. Full-system validation check (main firmware + visualizer)
5. Candidate endpoint world transform + report - [report_workflow.md](report_workflow.md), only
   after repeatability and scale pass (`python -m tools.calibration.report`)

## Firmware Paths

- v4 prototype: keep main `esp32s3_v4` firmware installed and use its commands.
- Classic draw-wire bench: `pio run -e test_drawwire --target upload`.
- Classic rotary bench: `pio run -e test_rotary --target upload`.
- The `test_*` environments use classic Wemos pins and must not be flashed to v4.

## Required Serial Commands

- `ZERO` — zero offsets/counts for current test context
- `ZERO_W` - capture the current wire count as zero
- `CAL_W <mm>` - compute a draw-wire calibration trial from the known distance
- `CAL_T <n>` — rotary theta calibration after `n` turns
- `CAL_P <n>` — rotary phi calibration after `n` turns
- `STATUS` — print current system status from main firmware

## Current Pin Map (source of truth: `SphericalSensor.h`)

Classic ESP32 (`wemos_d1_r32`):

- Theta A/B: GPIO `14` / `12`
- Phi A/B: GPIO `32` / `35`
- Draw-wire A/B: GPIO `16` / `17`

v4 PCB (`esp32s3_v4`):

- Draw-wire on J1: A/B = GPIO `7` / `8`
- Phi on J2: A/B = GPIO `4` / `5` through J2 pins `2` / `4`
- Theta on J3: A/B = GPIO `9` / `10`

v4 connector order:

| Connector | Order |
|---|---|
| J1 draw-wire | `1=A, 2=GND, 3=B, 4=+5V` |
| J2 phi | `1=+5V, 2=A, 3=GND, 4=B` |
| J3 theta | `1=A, 2=GND, 3=B, 4=+5V` |

This order is PCB-derived and was not physically reverified in the final documentation pass.
Theta/Phi colors are Brown `+5V`, Blue `GND`, Black `A`, White `B`; draw-wire colors are Yellow
`A`, Green `B`, Brown `+5V`, White `GND`.

## Current Working Constants (before recalibration)

- `PPR_ROTARY = 20000.0`  *(E40S6-5000 @ X4 quadrature)*
- `PPR_WIRE = 8000.0`  *(theoretical — OPKON DWEM2 P2000; run CAL_W after mounting to calibrate)*
- `DEG_PER_PULSE = 360 / PPR_ROTARY ≈ 0.0180`
- `MM_PER_PULSE = DRUM_CIRCUM_MM / PPR_WIRE ≈ 0.02500`

## Formula Reference

```text
counts_per_rev = total_counts / turns
deg_per_pulse = 360 / counts_per_rev
measured_mm = delta_counts * MM_PER_PULSE
factor = actual_mm / measured_mm
new_MM_PER_PULSE = MM_PER_PULSE * factor
```

## v4 Encoder Angle Signs (before PPR calibration)

Confirm Cartesian directions match the machine before calibrating PPR:

| Define | Current value | Expected motion |
|---|---|---|
| `ENCODER_PHI_SIGN` | -1.0 | Lift → +Z, φ increases |
| `ENCODER_THETA_SIGN` | +1.0 | Desired +Y → +θ |

Classic builds retain the opposite mounting convention (theta `-1`, phi `+1`). Do not copy v4 sign
values into a classic build without a direction check.

If lift drives −Z or forward drives −X, flip the corresponding sign in
`firmware/src/SphericalSensor.h` and reflash. See `docs/hardware_design/system_architecture.md`.

## Logging and Finalization

- Use templates under `docs/calibration/templates/` for every trial.
- Archive the theta repeatability evidence and require it to pass before endpoint fitting.
- After all trials, complete `final_calibration_record_template.md` and archive
  it as a dated file (example: `final_calibration_record_2026-03-03.md`).
- Only then update firmware constants in `SphericalSensor.h`; NVS may still override them.

## Files in this Folder

- `calibration_guide.md` — end-to-end procedure (Stages 1–6)
- `report_workflow.md` — **endpoint report tool** (CSV → Kabsch → `report.md`)
- `sessions/` — working + archived report sessions (`current/` inputs/outputs)
- `draw_wire_calibration.md`
- `theta_rotary_calibration.md`
- `phi_rotary_calibration.md`
- `templates/rotary_calibration_log_template.csv`
- `templates/draw_wire_calibration_log_template.csv`
- `templates/final_calibration_record_template.md`

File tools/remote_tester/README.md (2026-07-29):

# tools/remote_tester — wireless pendant test GUI

A minimal PyQt5 GUI for bench-testing the **ESP32-C3 button remote** in its standalone test mode.
It shows live press events for all 5 buttons plus the heartbeat, and can request a
`PINS` snapshot for the readable ESP32-C3 GPIOs so you can confirm the pendant
hardware and firmware work before pairing it (via ESP-NOW) with the main sensor board.

## What it talks to

The **`button_remote_test`** firmware env (`firmware/tests/ButtonRemoteTest/`). That firmware makes
its own WiFi access point and a TCP server (it does **not** use ESP-NOW — that's the point: it's a
direct, observable link for testing):

- AP: `REMOTE_TEST` / `remote1234`
- Default IP/port: `192.168.4.1:8080`

(The main pendant firmware, `firmware/remote/`, uses ESP-NOW broadcast instead and needs no GUI.)

## Run

```bash
# 1. Flash the test firmware:
pio run -e button_remote_test --target upload
# 2. Join WiFi "REMOTE_TEST", then:
python tools/remote_tester/remote_test_gui.py
```

Same UI is also in the unified GUI: **Remote Tester…** toolbar action
(`python -m tools.evka_gui`).

Button map (test firmware): BTN0 = ADD POINT, BTN1 = DEL POINT, BTN2–4 = raw GPIO 0/1/3.

Commands accepted by the test firmware over TCP or USB serial:

| Command | Response |
|---|---|
| `PING` | `ACK:PONG` |
| `PINS` | `PINS,GPIO0=...,GPIO1=...` for GPIO `0,1,2,3,4,5,6,7,8,9,10,20,21` |
| `HELP` | `HELP:PING,PINS,HELP` |

The GUI's **READ PINS** button sends `PINS` over the TCP test connection. The
firmware also accepts `PINS\n` on `/dev/ttyACM0` at 115200 baud for USB-only checks.

See also: `docs/hardware_design/remote/` (pendant hardware) and the `button_remote` main firmware
environment.

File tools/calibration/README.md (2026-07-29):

# tools/calibration — world↔sensor calibration

Computes the rigid-body transform (rotation **R**, translation **t**) that maps the sensor's
coordinate frame into the machine/world frame, so measured points can be reported in world
coordinates:

```
world_point ≈ R @ sensor_point + t
```

It uses the **Kabsch algorithm** (least-squares best-fit rotation + translation) on a set of paired
`sensor ↔ world` points.

Current project status: this tool produces **candidate** transforms. Theta count loss is unresolved,
no shared/default calibration JSON is checked in, and no endpoint/world transform is accepted.
`tools/evka_gui` does not apply transforms to live telemetry.

## Preferred workflow — standalone calibration app

```bash
python -m tools.calibration.gui                     # open disconnected
python -m tools.calibration.gui --serial /dev/ttyUSB0
python -m tools.calibration.gui --tcp 192.168.1.84:8080
python -m tools.calibration.gui --ws 192.168.1.50
```

One full-screen window with everything a calibration session needs and nothing else:
connection (serial / TCP / WebSocket), live position, and tabs for **Wire**, **Theta**,
**Phi**, **Endpoint**, **Points**, **Commands**.

The **Endpoint** tab drives this tool end to end: collect world/sensor pairs, assign each to
the calibration or validation set, **Generate report**, and read PASS/FAIL and per-point
residuals. It calls `generate_report()` in-process and needs no device once the points are in.

This app has **no software zero** by design — every captured coordinate is the raw sensor
frame. A display offset would be absorbed into the fit's translation and silently produce a
transform valid only while that offset is active.

**Full operator guide:** [docs/calibration/report_workflow.md](../../docs/calibration/report_workflow.md)

Also available: `evka_gui` → toolbar **Calibration…**, which has the same Endpoint workflow
inside the full telemetry GUI.

## CLI — report tool

Same engine, same session folder, same verdict:

```bash
# From the repo root
python -m tools.calibration.report
```

1. First run creates templates under `docs/calibration/sessions/current/` if missing.
2. Fill `calibration_points.csv` (fit) and `validation_points.csv` (hold-outs).
3. Run again → writes `report.md`, session `calibration.json`, and error CSVs.

The session `calibration.json` is not auto-copied or auto-loaded. After a PASS, it may be supplied
explicitly only to the legacy visualizer:

```bash
python -m tools.position_checker.main --legacy-visualizer --port /dev/ttyUSB0 \
  --calibration docs/calibration/sessions/current/calibration.json
```

Pass criteria: calibration RMSE ≤ 10 mm, validation max error ≤ 15 mm. Both must pass —
`GeneratedReport.passed` ANDs them, and it is what gates the Deploy button. The app,
`evka_gui`, and this CLI all call the same engine, so their verdicts always agree.

A report PASS and optional legacy visualization are not project acceptance. Record the mechanical
repeatability evidence, approval decision, and consuming application separately. The currently named
**Deploy calibration.json** action is legacy source behavior; the CLI prints only an explicit
legacy-visualizer invocation. Neither is the active canonical workflow.

CSV inputs need only the six coordinate columns; `label` and `notes` are optional. Exports
from the web dashboard **CALIBRATE → ENDPOINT** tab load as-is (the GUI's **Import CSV**
reads them through this same parser). `evka_gui` writes the two session CSVs directly, with
the full 8-column header.

## Legacy / quick fit — calibrate.py

Embedded point arrays (or a one-off CLI write):

```bash
python -m tools.calibration.calibrate
python -m tools.calibration.calibrate --out /tmp/evka_candidate_calibration.json
```

Output: the fit **R** and **t**, per-point residuals, and RMS error. Prefer the report
workflow for field sessions and an auditable record. Quick-fit output is not a passing session JSON.

## Providing calibration data

1. Move the tip to each known world point and record the sensor XYZ (`tools.calibration.gui`
   Endpoint tab → **Use Current Sensor XYZ**, `evka_gui` Calibration → Endpoint, web
   dashboard **CALIBRATE → Endpoint**, or serial `STATUS`).
2. In the app: pick **Add to: Calibration** or **Validation** per point — it writes the two
   session CSVs for you. A row's **Set** dropdown moves it between them afterwards.
3. By hand: put fit points in `calibration_points.csv` and hold-outs in
   `validation_points.csv`.
4. For the legacy CLI: replace `SENSOR_PTS` / `WORLD_PTS` in `calibrate.py` and re-run.

More points, well spread in **all three axes**, give a better fit — a single-axis set leaves the
rotation poorly constrained. Collinear or coincident calibration sets are rejected by the
report tool.

## Files

| File | Role |
|---|---|
| `gui.py` | **Standalone calibration app** (`python -m tools.calibration.gui`) — connection, live position, Wire/Theta/Phi/Endpoint/Points/Commands |
| `report.py` | Default calibration + validation CSV workflow; writes `report.md` |
| `calibrate.py` | Kabsch solver + embedded measurement data + legacy CLI |
| `tests/test_report.py` | Report workflow unit tests |
| `tests/test_gui.py` | Standalone app unit tests (offscreen Qt) |

```bash
pytest tools/calibration/tests/test_report.py -q
QT_QPA_PLATFORM=offscreen pytest tools/calibration/tests -q   # includes the app tests
```

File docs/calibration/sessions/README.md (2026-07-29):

# Calibration sessions

Working directory for the endpoint report tool:

```bash
python -m tools.calibration.report
```

Full operator guide: [../report_workflow.md](../report_workflow.md).

There is currently no accepted endpoint/world transform or checked-in shared/default calibration
JSON. Session outputs are candidates.

## Layout

| Path | Role |
|---|---|
| `current/` | Active working session — fill CSVs here, then regenerate the report |
| `YYYY-MM-DD_<operator>/` | Optional archives of completed sessions (copy of `current/` after a PASS) |

## Files in a session folder

**Inputs** (edit these):

| File | Role |
|---|---|
| `calibration_points.csv` | Point pairs used to fit `R` and `t` (≥ 3 rows; recommend 8+) |
| `validation_points.csv` | Hold-out pairs for PASS/FAIL and optional repeatability (≥ 1 row) |

**Outputs** (written by the tool; git-ignored):

| File | Role |
|---|---|
| `report.md` | Human-readable calibration + validation report |
| `calibration.json` | Candidate transform (`world = R @ sensor + t`); optional explicit legacy input only after PASS |
| `calibration_errors.csv` | Per-point calibration residuals |
| `validation_errors.csv` | Per-point validation residuals |

The session `calibration.json` is not auto-copied or auto-loaded. See
[report_workflow.md](../report_workflow.md#6-optional-explicit-legacy-transform).

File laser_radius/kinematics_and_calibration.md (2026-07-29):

# Kinematics & Calibration — Laser Radius Variant

**Parent doc:** [`README.md`](README.md). Covers laser-on-phi-head geometry, the spherical origin offset correction, and a calibration workflow to replace `CAL_W`/`PPR_WIRE`.

**Fixed requirement (2026-07-01, revised):** the laser device itself must be ≤10 mm accurate out to 40 m (confirmed with the user as a device-selection spec, not a combined-system target — see §4 for what that means for total XYZ accuracy).

---

## 1. Geometry: Laser on the Phi Head

Per the fixed design decision, the laser is mounted **on the phi head, pointing at the target along the boom** — its optical boresight is intended to be coincident with (or as close as mechanically practical to) the phi rotation axis. The laser measures a slant range along the same line `r` already represents in the spherical model, so no trigonometric correction is needed for the aiming direction itself. Two physical facts still need correction terms:

### 1.1 Fixed axial offset (always applies)

The laser's own optical reference plane sits some fixed distance forward of the phi pivot, because the laser body has physical length and a mounting bracket standoff. Simple additive constant, measured once at assembly:

```
r_true_mm = r_laser_reading_mm + d_offset_mm
```

`d_offset_mm` plays the role the old `DRUM_CIRCUM_MM`-derived scale did for the draw-wire, but is additive rather than multiplicative — every candidate device in this revised study (`version_a_handheld_devices.md`, `version_b_integrated_modules.md`) reports calibrated millimeters directly; there's no pulse-counting scale factor to derive.

### 1.2 Blind zone (device-dependent, affects zero-point strategy)

Every phase-shift device in the current shortlist has a minimum range below which it can't report a valid distance (JRT B605B / Meskernel LDL-T: 0.03 m; Bosch PLR 40 C: 0.05 m; Dimetix: 0.05 m). The current firmware's `RADIUS_MIN_MM = 0` supports a true zero-home boot sequence (`setZeroPoint()` 2 s after power-on, per `docs/ARCHITECTURE.md` and `pcb_design/EVKA_position_v4/FIRMWARE.md`) — **a laser cannot physically measure `r ≈ 0`.** Consequences:
- Boot-time `setZeroPoint()` cannot rely on reading `r = 0` — home must be a known non-zero reference distance outside the blind zone (§3).
- `RADIUS_MIN_MM` should be raised to the device's blind-zone floor (plus `d_offset_mm`) for this variant.

### 1.3 Lateral (off-axis) offset — only if the on-axis mount can't be achieved

If the laser body ends up with a small lateral displacement `e_mm` from the true phi rotation axis, a target along the boom's pointing direction is measured at a very slightly different slant range than the true on-axis `r`. For `e_mm << r` this is negligible at any range in this study (0–40 m). Recommendation: keep the laser boresight on-axis by design and treat lateral offset as negligible unless bench measurement shows otherwise.

## 2. Target Reflectivity

Phase-shift devices are generally more forgiving of surface reflectivity than pulsed ToF (they integrate over a modulated signal rather than needing a clean single-pulse return), but accuracy still degrades on very dark, glossy, or steeply angled surfaces — Bosch's own spec sheet explicitly notes a ±4 mm worst-case figure "in unfavourable conditions … poorly reflecting surface" (see `version_a_handheld_devices.md` §2.3), still within the ≤10 mm budget but worth planning for. Recommendations:
- Prefer a matte, light-colored, perpendicular target surface at the measurement point where possible.
- If the target surface is uncontrolled, consider a small fixed retroreflective/diffuse reference patch at the expected contact point (Dimetix even sells a purpose-made reflective target plate as an accessory — see `procurement_and_bom.md`).
- Firmware should surface confidence/signal-quality data (if the chosen device exposes it) through `is_valid`, mirroring how the current system already treats degraded encoder data as invalid rather than silently wrong.

## 3. Calibration Workflow — Replacing `CAL_W`

The draw-wire's `CAL_W` exists because a drum-and-pulse-count system has two unknowns: a scale factor (mm per pulse) and a zero offset. A laser device removes the scale unknown — it already reports calibrated millimeters — leaving only the additive offset from §1.1 (and, rarely, a minor linearity check).

### 3.1 New commands (proposed, firmware not implemented — see `firmware_integration.md`)

| Command | Response | Behavior |
|---|---|---|
| `ZERO_R` | `ACK:ZERO_R` | Captures the current raw laser reading at a known reference position and zeroes `r_offset_mm` against it (mirrors `ZERO_W`) |
| `CAL_R <known_mm>` | `CAL:RADIUS,<offset_mm>` | Operator places a target at a precisely known distance `known_mm` (outside the device's blind zone); firmware computes `r_offset_mm = known_mm - raw_reading_mm`. Preferred over `ZERO_R` — no need for a literal mechanical zero, which the laser can't measure anyway (§1.2). Errors mirror `CAL_W`'s pattern: `ERR:CAL_R bad value`, `ERR:CAL_R out of range` |
| `SET_R_OFFSET <v>` | `ACK:R_OFFSET,<v>` | Update offset in RAM directly (mirrors `SET_PPR_WIRE`) |
| `SAVE_R` | `ACK:SAVE_R` | Persist `r_offset_mm` (and optional `r_scale`) to NVS (mirrors `SAVE_PPR`) |

### 3.2 Optional linearity spot-check

Phase-shift devices are inherently metric and linear within spec, so a full multi-trial mean/spread calibration (as `CAL_W` requires for the draw-wire's mechanical drum) isn't needed. Place a target at 2–3 known distances spanning 0–40 m, compare reported vs. actual after applying `r_offset_mm`, and confirm the residual stays within the device's ≤10 mm spec (all recommended devices should show far tighter residuals — 1–3 mm class, per `version_a_handheld_devices.md`/`version_b_integrated_modules.md`). Only add a multiplicative `r_scale` term (default `1.0`) if a systematic scale error actually shows up.

### 3.3 NVS persistence

Reuse the existing `evka_cal` namespace. Add `r_offset` (float, mm) and optionally `r_scale` (float, default `1.0`). Apply the same load-time validation pattern already used for PPR values (`isfinite` + range guard): reject `r_offset` outside a sane bound (e.g., `|r_offset| > RADIUS_MAX_MM`) and fall back to `0.0`. The `ppr_wire` NVS key doesn't apply to this variant.

### 3.4 Web dashboard CALIBRATE tab impact

Replace the wire tab's multi-trial table (mean PPR, spread %, APPLY/APPLY+SAVE) with a simpler panel: one `CAL_R` action (enter known distance, click compute) plus a 2–3-row spot-check table (expected vs. measured, pass/fail against the ≤10 mm spec). Theta/Phi tabs are unaffected.

## 4. Combined Error Budget — Why the Laser Spec Alone Isn't the Whole Story

**This section is informational context, not a redesign trigger** — per the user's explicit decision, the ≤10 mm requirement applies to the laser device's own spec, and the encoder side is out of scope for this study. It's included because the number is large enough to be worth knowing before committing to a 40 m working range in practice.

The rotary encoders' angular resolution contributes an arc-length error that **grows linearly with `r`**: `arc_error_mm ≈ r_mm × sin(DEG_PER_PULSE in radians) ≈ r_mm × 3.1416×10⁻⁴` at `DEG_PER_PULSE = 0.018°`. Combining independent error sources by RSS (θ-arc, φ-arc, laser accuracy) for the shortlisted devices:

| Range `r` | θ/φ arc error (each axis) | + JRT B605B (±1mm+40ppm) | + Bosch PLR 40 C (±2mm flat) | + Dimetix/Meskernel (±1mm flat) |
|---|---|---|---|---|
| 5 m | 1.57 mm | ≈2.5 mm | ≈3.0 mm | ≈2.4 mm |
| 20 m | 6.28 mm | ≈9.1 mm | ≈9.1 mm | ≈8.9 mm |
| 40 m | 12.57 mm | ≈18.0 mm | ≈17.9 mm | ≈17.8 mm |

**Key finding, unchanged in substance from the prior tiered pass:** every laser candidate in this revised study clears its own ≤10 mm bar at 40 m by a wide margin (all report ≤2.6 mm of their own error). But the **combined XYZ position accuracy at 40 m is ≈18 mm regardless of which laser is chosen**, because the θ/φ encoders alone contribute ~17.8 mm (RSS both axes) at that range — the laser choice barely moves the total once you're past ~10–15 m. If total system accuracy ever becomes the requirement (rather than laser-device accuracy alone, per this session's clarification), the bottleneck is the encoders, not the laser — see `docs/research/improvement_research.md` §4.4 and §5.1 for encoder resolution / absolute-encoder upgrade paths that would need revisiting in that scenario.

## Open Risks

1. **Zero-point strategy changes fundamentally** — `setZeroPoint()` assumes a literal `r ≈ 0` mechanical home; a laser variant needs a redefined home procedure (§1.2/§3.1) before firmware work starts.
2. **`RADIUS_MIN_MM` needs to move** from `0` to the chosen device's blind-zone floor.
3. **`d_offset_mm` depends on final mechanical mounting**, which doesn't exist yet.
4. **Target reflectivity in real working conditions is unknown** — §2's recommendations are generic.
5. **The 40 m combined-system accuracy figure (§4, ≈18 mm) is out of scope per the user's decision but should be revisited if this variant is ever asked to guarantee total XYZ accuracy, not just laser accuracy, at long range.**

## Next Physical Test Steps

1. Once a laser candidate is on the bench, measure its actual blind zone and confirm the datasheet's minimum range figure.
2. Mock up the phi-head mount and physically measure `d_offset_mm` from the phi rotation axis to the laser's stated optical reference plane.
3. Run the 2–3 point spot-check (§3.2) on a physical device across 5 m / 20 m / 40 m and confirm the ≤10 mm spec holds in practice, not just on the datasheet.
4. Test signal quality against 2–3 representative target surfaces to ground-truth §2's assumptions.

---

*Part of the [laser radius detailed study](README.md). Docs-only — no firmware or PCB changes.*

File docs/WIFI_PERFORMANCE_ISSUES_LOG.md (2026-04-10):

# WiFi Performance & Connection Issues — Diagnostic Log

**Date**: 2026-04-08  
**Firmware commit at time of investigation**: `9405ac9` (latest: post-fix flash)  
**Board**: ESP32 Wemos D1 R32  
**Mode**: `WIFI_AP_STA` — AP `CMDCNC_EVKA` @ `192.168.1.50`, STA target `CMD-YAZILIM` (credentials stored in NVS; was `Yunusa` @ `10.78.137.252` at time of original investigation)

---

## Reported Symptoms

- Web dashboard at `http://192.168.1.50` was noticeably slower than before recent commits
- Intermittent WebSocket disconnections — dashboard data appeared "bursty" instead of smooth 20 Hz
- Could not reach dashboard at all in some network configurations
- `WIFI_SET` command silently corrupted (command sent, no acknowledgment)

---

## Issues Found and Fixed

### Issue 1 — WiFi Modem Sleep Enabled (PRIMARY CAUSE of slowness)

| | |
|---|---|
| **Severity** | Critical |
| **Status** | Fixed |
| **File** | `firmware/src/WebDashboard.cpp` |

**Root cause**: ESP32 defaults to `WIFI_PS_MIN_MODEM`. The radio periodically powers down between DTIM beacons (~100 ms gaps). In AP+STA mode this causes:
- AP clients miss beacons → WebSocket drops and reconnect cycles
- DATA messages queue then flush in bursts instead of a steady 20 Hz stream
- Dashboard appears "jumpy" or completely stalled between bursts

**Fix applied**:
```cpp
// After WiFi.softAP(...)
WiFi.setSleep(WIFI_PS_NONE);  // disable modem sleep
```

---

### Issue 2 — No Explicit AP Channel (Channel Drift)

| | |
|---|---|
| **Severity** | High |
| **Status** | Fixed |
| **File** | `firmware/src/WebDashboard.cpp` |

**Root cause**: `WiFi.softAP(SSID, PASS)` picks a channel automatically. Background STA scanning for home/office networks can cause the AP to shift channels mid-session, momentarily disappearing for connected clients.

**Fix applied**:
```cpp
WiFi.softAP(WIFI_AP_SSID, WIFI_AP_PASSWORD, ESPNOW_CHANNEL);  // pin to ch 1
```
Reuses the existing `ESPNOW_CHANNEL 1` constant — ESP-NOW remote (when enabled) requires the same channel as the AP.

---

### Issue 3 — STA Full-Channel Scan Interferes with AP

| | |
|---|---|
| **Severity** | Medium |
| **Status** | Fixed |
| **File** | `firmware/src/WebDashboard.cpp` |

**Root cause**: When STA credentials are stored but the target network is not reachable, the WiFi driver runs continuous 13-channel scans. This consumes radio time shared with the AP, degrading AP throughput.

**Fix applied**:
```cpp
WiFi.setScanMethod(WIFI_FAST_SCAN);          // stop on first SSID match
WiFi.setSortMethod(WIFI_CONNECT_AP_BY_SIGNAL);
WiFi.setAutoReconnect(false);                // manual retry/backoff owns reconnect policy
WiFi.begin(staSsid.c_str(), staPass.c_str());
```

---

### Issue 4 — WebSocket Command Buffer Truncated at 32 Bytes

| | |
|---|---|
| **Severity** | High |
| **Status** | Fixed |
| **File** | `firmware/src/WebDashboard.cpp`, `onWsEvent()` |

**Root cause**: `char cmd[32]` silently truncated any WebSocket command longer than 31 bytes. `WIFI_SET:CMD-YAZILIM,cmd20165544` is 35 characters — the tail was cut, making the command unrecognizable, which returned `ERR:UNKNOWN_CMD` with no indication of truncation.

**Fix applied**: Replaced the fixed buffer with a direct `String` construction from raw WebSocket bytes, capped at 128 bytes (matching the serial buffer limit).
```cpp
size_t n = (len < 128) ? len : 128;
String cmdStr((const char*)data, n);
cmdStr.trim();
_pendingCmd = cmdStr;
```

---

### Issue 5 — `cleanupClients()` Called on Every DATA Event (60×/sec)

| | |
|---|---|
| **Severity** | Medium |
| **Status** | Fixed |
| **File** | `firmware/src/WebDashboard.cpp`, `onWsEvent()` |

**Root cause**: `_ws.cleanupClients()` was called at the end of `onWsEvent()` unconditionally, including on `WS_EVT_DATA` events. With 3 clients at 20 Hz this means ~60 client-list iterations per second for no reason — cleanup is only meaningful when clients join or leave.

**Fix applied**: Moved `_ws.cleanupClients()` exclusively to `WS_EVT_CONNECT` and `WS_EVT_DISCONNECT` event branches.

---

### Issue 6 — 3D Canvas Redraws at 60 Hz with No Dirty Flag

| | |
|---|---|
| **Severity** | Low–Medium (CPU / battery on client device) |
| **Status** | Fixed |
| **File** | `firmware/src/WebDashboard.cpp` (embedded JS) |

**Root cause**: `drawScene()` called `requestAnimationFrame()` unconditionally and always executed the full canvas repaint — expensive matrix transforms + draw calls — at 60 FPS. Data arrives at 20 Hz, so 3 out of every 4 frames were wasted redraws of an unchanged scene.

**Fix applied**: Added `_dirty3d` boolean flag. `drawScene()` only repaints when `_dirty3d` is true or a touch gesture is active. `_dirty3d` is set to `true` when new DATA arrives, and in `toggleAxes()`, `clearTrail()`, `saveOrigin()`, and `savePoint()`.

---

### Issue 7 — 192.168.1.x AP Subnet Conflicts with Home/Office Routers

| | |
|---|---|
| **Severity** | Low (operational, cannot be fixed in firmware) |
| **Status** | Documented |
| **File** | `firmware/src/SphericalSensor.h` |

**Root cause**: The AP static IP `192.168.1.50` is in the same subnet used by most home/office routers (`192.168.1.0/24`). If a client device is simultaneously connected to a home router on the same subnet, the OS routes `192.168.1.50` to the home router instead of the ESP32, making the dashboard unreachable.

**Cannot change**: CMD CNC software is hardcoded to `192.168.1.50:8080`.

**Workaround**: Disconnect the client device from the home/office WiFi before connecting to `CMDCNC_EVKA`. The device should be connected **only** to `CMDCNC_EVKA` when accessing the dashboard.

**Documentation added** in `SphericalSensor.h` at the `WIFI_AP_IP_*` defines.

---

### Issue 8 — AP Reachability Drops After STA Disconnect

| | |
|---|---|
| **Severity** | High |
| **Status** | Fixed in firmware, hardware test pending |
| **Files** | `firmware/src/WebDashboard.h`, `firmware/src/WebDashboard.cpp`, `firmware/src/EvkaPosition.cpp` |

**Root cause**: AP was configured once at startup, while STA reconnect behavior was left to background retries. During repeated STA disconnect/reconnect churn, AP availability could degrade, and there was no WiFi event-driven recovery path to reassert AP state.

**Fix applied**:
- Added WiFi event handling for STA lifecycle (`STA_CONNECTED`, `STA_GOT_IP`, `STA_DISCONNECTED`)
- Added AP health watchdog (`dashboard.tick()` + periodic AP verification)
- Added controlled STA reconnect backoff instead of unmanaged rapid retries
- Added AP reassertion path that verifies AP health on STA disconnect and only reruns `softAPConfig` + `softAP` if the AP is actually unhealthy
- Deduplicated the initial STA join attempt so boot performs one `WiFi.begin()` call and later retries remain backoff-driven

**Build verification**:
```bash
pio run -e wemos_d1_r32
```
Result: **SUCCESS** (firmware compiles with the new WiFi recovery flow).

---

## Operational Issue — Stale Serial RX Buffer Corrupts First Command

| | |
|---|---|
| **Severity** | Low (affects development workflow only) |
| **Status** | Workaround documented |

**Symptom**: After closing `pio device monitor`, the Linux USB-serial driver retains bytes in the RX buffer. The next command sent via Python `serial.Serial` prepends those stale bytes, making the command unrecognizable → `ERR:UNKNOWN_CMD`.

**Workaround**: Always call `reset_input_buffer()` + `reset_output_buffer()` before the first write in any serial session:
```python
s = serial.Serial('/dev/ttyUSB0', 115200, timeout=3)
s.reset_input_buffer()
s.reset_output_buffer()
```

---

## Current System State (post-fix, verified via serial)

| Parameter | Value |
|---|---|
| Uptime | 265 s (stable, no watchdog reset since flashing) |
| Free heap | 231,792 bytes (zero drift across 5 samples over 15 s — no leak) |
| WiFi RSSI (STA → Yunusa) | -38 to -46 dBm (measured at time of investigation; STA now targets CMD-YAZILIM) |
| DATA frame rate | 20 Hz (50 ms intervals confirmed) |
| is_valid | 1 |
| TCP clients connected | 0 |
| PPR_ROTARY | 20000.00 |
| PPR_WIRE | 8020.00 |
| mm_per_pulse | 0.024938 |
| deg_per_pulse | 0.018000 |

**Network topology**:
```
ESP32 AP  : CMDCNC_EVKA   →  192.168.1.50  (dashboard + CMD TCP)
ESP32 STA : CMD-YAZILIM   →  DHCP (send GET_IP when connected)
Note: Original investigation used STA "Yunusa" @ 10.78.137.252 — now changed to CMD-YAZILIM
```

---

## Open Items / Pending Verification

### A — Dashboard connectivity not yet confirmed post-fix

The performance fixes have been flashed and are running, but **no client has connected to `CMDCNC_EVKA` yet** to verify the WebSocket data flow is smooth. The next test step:

1. On phone or laptop: disconnect from current WiFi
2. Connect to `CMDCNC_EVKA` (password: `cmdcnc1234`)
3. Open `http://192.168.1.50`
4. Observe: page load < 2 s, 3D trail updating smoothly, no WebSocket drops over 2+ minutes

### B — `RTCWDT_RTC_RESET` watchdog resets observed

Earlier serial output showed `RTCWDT_RTC_RESET` in the boot log, indicating the ESP32 watchdog fired during a previous run. This is likely related to a long blocking operation during `setup()` (most probable candidate: `delay(2000)` + `WiFi.begin()` blocking during STA association).

**Impact**: If the watchdog fires repeatedly, the firmware enters a reboot loop. Currently not reproducing — the device has been stable for 160+ s.

**To investigate if it recurs**: Check if `WiFi.begin()` blocks longer than expected. Consider moving the 2 s zero-calibration delay to use a non-blocking `millis()` check, or calling `esp_task_wdt_reset()` before the delay.

### C — Theta residual of 0.02° after zero

`DATA` frames show `Theta=0.018` (≈ 1 encoder count) after `setZeroPoint()`. This is within 1 PPR count of true zero and is not a real error — it reflects the `DEG_PER_PULSE = 0.018°` quantization step. No fix needed unless sub-count accuracy is required.

### D — AP persistence validation after upstream STA loss

Pending physical verification for the new recovery logic:
1. Boot with reachable `CMD-YAZILIM`
2. Confirm STA connected and AP reachable (`CMDCNC_EVKA`)
3. Power off router / disconnect `CMD-YAZILIM`
4. Confirm AP remains joinable and `http://192.168.1.50` still responds
5. Re-enable router and confirm STA rejoins without AP interruption

---

## Files Modified in This Session (2026-04-08)

| File | Changes |
|---|---|
| `firmware/src/WebDashboard.cpp` | Issues 1–6: modem sleep, AP channel pin, fast STA scan, WS buffer, cleanupClients, JS dirty flag |
| `firmware/src/SphericalSensor.h` | Issue 7: subnet conflict warning comment |
| `firmware/src/WebDashboard.h` | Added WiFi recovery state fields and periodic `tick()` API |
| `firmware/src/WebDashboard.cpp` | Issue 8: WiFi event handling, AP reassertion, STA retry backoff logic |
| `firmware/src/EvkaPosition.cpp` | Calls `dashboard.tick()` in main loop for non-blocking WiFi maintenance |
| `docs/WIFI_AP_STA_RECONNECT_PATTERNS.md` | NEW: Best practices for WiFi.begin() in AP+STA mode, safety analysis, reconnect patterns |

---

## 2026-04-09 — Code Review Session: WiFi Bug Fixes + Reliability Audit

**Reviewers**: Gemini (code review) + Copilot (ESP32 library internals research)
**Build**: SUCCESS — Flash 895,149 bytes (−260 bytes from 2026-04-08 baseline)

---

### WiFi Code Review Fixes (8 bugs)

These bugs were found by Gemini after reviewing the Issue 8 WiFi recovery implementation.

| # | Severity | Bug | Fix |
|---|---|---|---|
| W1 | Low | `_needApReassert` not cleared in `ensureApUp()` early-return → repeated `softAP()` calls when AP was healthy | Added `_needApReassert = false` before early-return |
| W2 | Medium | Backoff formula mismatch: `onWiFiEvent` used `count−1` as shift; `tick()` used `count` — diverging schedules | Removed backoff recalc from `tick()`; `onWiFiEvent` solely owns the schedule |
| W3 | Medium | No `volatile` on 5 cross-task flags (`_staConnected`, `_needApReassert`, `_staRetryPending`, `_staDisconnectCount`, `_nextStaRetryMs`) written from WiFi event callback | Added `volatile` to all 5 fields in `WebDashboard.h` |
| W4 | Low | `now >= _nextStaRetryMs` unsafe at millis() 49.7-day rollover | Changed to `(int32_t)(now - _nextStaRetryMs) >= 0` (standard Arduino idiom) |
| W5 | Low | Default `WiFi.setAutoReconnect(true)` — IDF auto-retry running in parallel with manual backoff, bypassing `_staDisconnectCount` | Added `WiFi.setAutoReconnect(false)` in `begin()` |
| W6 | Low | `WiFi.mode()` called on every forced AP reassert even if already in correct mode | Guard: `if (WiFi.getMode() != targetMode)` before calling `WiFi.mode()` |
| W7 | Medium | Slow DHCP after `STA_CONNECTED` still looked disconnected to the watchdog, so `tick()` could restart a valid join with a delayed IP lease | Added separate `_staAssociated` state and disarmed the watchdog on association; retry/watchdog now only run while the STA is actually unassociated |
| W8 | Low | `_staDisconnectCount` was a `uint8_t` incremented without saturation, so after 255 disconnects the backoff schedule reset to the 3 s base interval | Saturated the counter before increment so the capped 60 s backoff remains stable during long outages |
| W9 | Medium | `STA_LOST_IP` cleared `_staConnected` but did not trigger recovery while association remained up, allowing a potential associated/no-IP stall when auto-reconnect is disabled | Added `STA_LOST_IP_RECOVERY_MS` watchdog window (45 s): on prolonged `LOST_IP`, force controlled reconnect via existing manual retry path without reintroducing slow-DHCP reconnect loops |

---

### Follow-up hardening for W7/W8 review (2026-04-09)

**Scope**: closed the residual `STA_LOST_IP` edge case discovered after W7/W8.

**State-machine behavior now**
- `STA_CONNECTED`: marks `_staAssociated=true`, disarms connect-attempt watchdog.
- `STA_GOT_IP`: marks `_staConnected=true`, clears `_staLostIpMs`, resets disconnect counter.
- `STA_LOST_IP`: marks `_staConnected=false`, starts `_staLostIpMs` timer (first event only).
- `tick()`: if associated/no-IP persists for `STA_LOST_IP_RECOVERY_MS` (45 s), calls `WiFi.disconnect(false, false)` and reuses existing retry scheduler/backoff.

**Verification performed**
- Firmware build: `pio run -e wemos_d1_r32` (PASS)
- Python tests: `pytest -q` (29 passed)
- Scenario checks by state-path review:
  - Slow DHCP after association does **not** re-enter reconnect loop (W7 preserved).
  - Long outage keeps capped retry behavior (W8 preserved).
  - `LOST_IP` without immediate disassociation now exits via timed, controlled reconnect (W9 fixed).

### Reliability & Optimization Fixes (7 fixes + 2 follow-ups)

These bugs were found by Gemini (full code audit) + Copilot (library internals).

| # | Severity | Bug | Fix | File |
|---|---|---|---|---|
| R1 | High | `normalizeAngle()` used while-loops — O(N) CPU block at large encoder counts (107K iterations at max int32 range) | Replaced with O(1) `fmodf` | `SphericalSensor.cpp:161` |
| R2 | High | STA retry dead-stop: `tick()` cleared `_staRetryPending` but if IDF never fires `DISCONNECTED`, retries stop forever | Added `_staConnectAttemptMs` deadline watchdog (15 s) in `tick()` | `WebDashboard.cpp/h` |
| R3 | Medium | `validateLimits()` only checked NaN/Inf on Cartesian fields — NaN in spherical coords (e.g. from zero-PPR NVS corruption) passed as valid | Added `isnan`/`isinf` guards on `sph.r_mm`, `sph.theta_deg`, `sph.phi_deg` | `SphericalSensor.cpp:173` |
| R4 | Medium | Double-precision literals (`1.0`, `180.0`) in EMA filter and trig — ESP32 Xtensa has no hardware double FPU, forces software emulation (10–20× slower) | Changed to `1.0f`, `180.0f`; trig: `sin/cos/asin/atan2` → `sinf/cosf/asinf/atan2f/sqrtf` | `SphericalSensor.cpp:127–204` |
| R5 | Medium | `printPosition()` formatted and printed the DATA line to serial; `loop()` also formatted the same DATA line for WebSocket — two snprintf calls per tick | Removed DATA snprintf from `printPosition()`; `loop()` formats once → `Serial.println()` + `dashboard.broadcast()` | `SphericalSensor.cpp:252`, `EvkaPosition.cpp:407` |
| R6 | Minor | `_staConnectAttemptMs` written from `onWiFiEvent(GOT_IP)` callback but not declared `volatile` | Added `volatile` keyword | `WebDashboard.h:44` |
| R7 | Minor | `cartesianToSpherical()` used `sqrt()` (double) instead of `sqrtf()` (float) | Changed to `sqrtf()` | `SphericalSensor.cpp:145` |

---
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

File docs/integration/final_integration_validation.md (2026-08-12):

# v4 Prototype Integration Validation

This checklist defines evidence required to close the current prototype handoff. Nothing in this
file records a test as completed. The final documentation reconciliation ran no hardware checks.

## Software Baseline

- [ ] Record the final tagged commit/hash after local release preparation.
- [x] Build all 10 configured PlatformIO environments.
- [x] Run the full Python test suite headlessly (two invocations): 204 passed.
- [x] Run the embedded dashboard harness: 50 checks passed.
- [x] Run compileall and the IPT solver self-check.
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

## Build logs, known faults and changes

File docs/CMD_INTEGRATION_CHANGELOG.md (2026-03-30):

# CMD Protocol Integration — Changelog & Rationale

This document explains every change made to integrate the third-party CMD firmware/GUI protocol into the EvkaPosition system, and why each change was necessary.

For a short operational guide, see `docs/CMD_SOFTWARE_INTEGRATION.md`.

## Background

A third-party firm (CMD) provided their own ESP32 firmware (`firmware/src/CMD Soft/main.cpp`) and a Windows C# GUI (`firmware/src/CMD Soft/gui.cs`). Their system uses:

- **WiFi AP**: SSID `CMDCNC`, password `cmdcnc1234`, static IP `192.168.1.50`
- **Raw TCP server** on port `8080`
- **Data format**: `X<val>,Y<val>,Z<val>\n` (e.g. `X123.45,Y-67.89,Z0.12\n`)
- **Commands**: `ZERO`, `GET_IP`, `WIFI_AYAR:<ssid>,<pass>` (Turkish)
- **Responses**: `SIFIRLANDI` (Turkish for "zeroed"), `STA_IP:<ip>`, `WIFI_KAYDEDILDI_REBOOT` (Turkish)
- **Encoder library**: ESP32Encoder (hardware PCNT)
- **NVS namespace**: `ayarlar` (Turkish for "settings")
- **Blocking architecture**: single-client, `while (client.connected())` loop with `delay(50)`

Our goal: make our hardware speak the same TCP protocol so the CMD GUI works with our device **unchanged**, while keeping our existing WebSocket dashboard and all its features.

---

## Firmware Changes

### 1. `firmware/src/SphericalSensor.h` — New Constants

| Constant | Value | Why |
|---|---|---|
| `ENABLE_CMD_TCP` | `1` | Feature flag — compile TCP server in/out without touching other code |
| `CMD_TCP_PORT` | `8080` | Must match CMD GUI's hardcoded port |
| `WIFI_AP_SSID` | `"CMDCNC"` | Changed from `"EvkaPosition"` to match CMD protocol (their GUI connects to this SSID) |
| `WIFI_AP_PASSWORD` | `"cmdcnc1234"` | Changed from `"evka1234"` to match CMD protocol |
| `WIFI_AP_IP_O1..O4` | `192.168.1.50` | CMD firmware uses `192.168.1.50` (we used `192.168.4.1`). Their GUI hardcodes this IP |
| `PIN_WIFI_LED` | `2` | GPIO 2 = built-in LED on most ESP32 boards, used for WiFi status indication |

**Why not just change the GUI?** The CMD GUI may be distributed to end users who won't update it. Matching their protocol means zero changes on the client side.

### 2. `firmware/src/CmdTcpServer.h` + `CmdTcpServer.cpp` — New Files

A dedicated TCP server class that runs alongside the existing HTTP+WebSocket server.

**Key design decisions:**

| Decision | Why |
|---|---|
| **Separate class** (not inline in `loop()`) | Keeps `EvkaPosition.cpp` clean; TCP server logic is self-contained |
| **Non-blocking `poll()` pattern** | CMD's original code used a blocking `while(client.connected())` loop — this freezes the entire MCU. Our non-blocking approach lets WebSocket, serial, and TCP all run concurrently |
| **Max 3 clients** | ESP32's lwIP stack has ~16 sockets total. HTTP+WS already use several. 3 TCP clients is a safe budget |
| **`setNoDelay(true)`** | Disables Nagle's algorithm (200ms batching). Without this, position data arrives in delayed bursts instead of real-time |
| **Per-client rx buffer with 128-byte limit** | Prevents a misbehaving client from consuming all heap with an endless string |

**Protocol compatibility — what CmdTcpServer sends:**

| Message | Format | Purpose |
|---|---|---|
| Position | `X<val>,Y<val>,Z<val>\n` | Identical to CMD format — their GUI parses this |
| Sensor data | `SENSOR,<r>,<theta>,<phi>,<valid>,<frame>\n` | **New** — our addition for richer GUIs. CMD GUI ignores lines not starting with `X` or `STA_IP:`, so this is safe |

**Commands handled directly by TCP server (not forwarded to main loop):**

| Command | Response | Why handled here |
|---|---|---|
| `GET_IP` | `STA_IP:<ip>` or `STA_IP:NOT_CONNECTED` | Matches CMD protocol. Response goes only to the requesting client |
| `WIFI_SET:<ssid>,<pass>` | `ACK:WIFI_SAVED` + reboot | NVS save + ESP restart. Also accepts `WIFI_AYAR:` for backward compat with original CMD GUI |

All other commands (`ZERO`, `PING`, `STATUS`, calibration commands, etc.) are forwarded to `processCommand()` in the main loop via `_pendingCmd`, and the reply is broadcast to all TCP clients.

### 3. `firmware/src/WebDashboard.cpp` — WiFi Init + HTML Additions

**WiFi initialization rewritten:**

```
Before:  WiFi.mode(WIFI_AP);  WiFi.softAP(ssid, pass);  // AP only, default 192.168.4.1
After:   WiFi.mode(WIFI_AP_STA);                         // AP + STA simultaneously
         WiFi.softAPConfig(192.168.1.50, ...);            // Static IP matching CMD
         WiFi.softAP(WIFI_AP_SSID, WIFI_AP_PASSWORD);
         // Load STA credentials from NVS "wifi_cfg" → WiFi.begin() if present
```

**Why AP+STA?** The device acts as an access point (clients connect directly) AND can join an existing WiFi network (for remote access, OTA, etc.). CMD's original firmware did this too.

**Why AP config before STA?** If STA init runs first and gets a DHCP address, the AP's DHCP server can conflict. AP-first avoids this.

**HTML/JS additions to the web dashboard** (all client-side, no firmware commands needed):

| Feature | What it does | Why |
|---|---|---|
| Per-axis software zero (X=0, Y=0, Z=0) | Subtracts current value as offset — display shows relative position | Matches CMD C# GUI behavior. Distinct from `ZERO` which resets encoder hardware |
| Min/Max tracking | Shows min and max values for each axis during the session | Useful for measuring travel range without external tools |
| Position snapshots | CAPTURE button logs X,Y,Z + timestamp to a table; export as CSV | Quick measurement recording without the full calibration workflow |
| WiFi settings | SSID/password inputs, SAVE & REBOOT, FORGET buttons | Lets users configure STA connection from the web dashboard |
| System info | RSSI, free heap, uptime, TCP client count | Diagnostic info; polls via `SYSINFO` command every 5 seconds |

### 4. `firmware/src/EvkaPosition.cpp` — Main Loop Integration

**New commands added to `processCommand()`:**

| Command | Response | Why |
|---|---|---|
| `GET_IP` | `STA_IP:<ip>` or `STA_IP:NOT_CONNECTED` | Needed by both GUIs and web dashboard to show router IP |
| `WIFI_SET:<ssid>,<pass>` | `ACK:WIFI_SAVED` + reboot | WiFi credential management from serial/WebSocket |
| `SYSINFO` | `SYSINFO,<rssi>,<heap>,<uptime_s>,<tcp_clients>` | System diagnostics for GUIs and web dashboard |

**WiFi LED logic (GPIO 2):**

| LED State | Meaning |
|---|---|
| OFF | No STA credentials configured (AP-only mode) |
| Blinking (500ms) | STA credentials exist but not yet connected (searching) |
| Solid ON | STA connected to router |

**TCP integration in `loop()`:**

```cpp
cmdTcp.poll();                    // Accept clients, read commands
String tcpCmd = cmdTcp.takePendingCommand();
if (tcpCmd.length() > 0) {
    String reply = processCommand(tcpCmd);
    if (reply.length() > 0) cmdTcp.sendToAllClients(reply.c_str());
}
// In the 50ms update block:
cmdTcp.broadcastPosition(x, y, z);      // X,Y,Z format
cmdTcp.broadcastSensorData(r, theta, phi, valid, frame);  // SENSOR format
```

### 5. `platformio.ini` — Build Filter

```
build_src_filter = +<src/> -<src/CMD Soft/>
```

**Why?** The `CMD Soft/` folder contains reference code that uses `ESP32Encoder.h` (not in our dependencies). Without this exclusion, PlatformIO tries to compile it and fails.

---

## GUI Changes

### C# GUI (`firmware/src/CMD Soft/gui.cs`) — Full Rewrite

The original CMD GUI was in Turkish with minimal features. We rewrote it in English with feature parity to our web dashboard.

**What changed and why:**

| Aspect | Original (CMD) | New | Why |
|---|---|---|---|
| Language | Turkish (SIFIRLA, BAĞLAN, etc.) | English | Project standard — all code and UI in English |
| Settings file | `ayarlar.txt` | `settings.txt` | English naming convention |
| WiFi command | `WIFI_AYAR:` | `WIFI_SET:` | English. Firmware accepts both for backward compatibility |
| Position display | X, Y, Z only | X, Y, Z + R, theta, phi + valid + frame | Richer diagnostic info using new `SENSOR,` message |
| Min/Max tracking | None | Per-axis min/max with reset button | Matches web dashboard feature |
| System info | None | RSSI, heap, uptime (polls `SYSINFO` every 5s) | Diagnostics without opening the web dashboard |
| WiFi settings | None visible | SSID/Password/SAVE/FORGET section | Configure STA connection from the GUI |
| Per-axis zero | None | X=0, Y=0, Z=0 buttons | Software zero with offset subtraction (client-side) |
| Hardware zero | "SIFIRLA" button | "Hardware Zero (Encoder)" with confirmation dialog | Prevents accidental encoder reset |

**What stayed the same:**

- TCP connection to port 8080
- Parsing of `X<val>,Y<val>,Z<val>\n` position data
- Parsing of `STA_IP:` responses
- Software zero offset subtraction approach (same logic as original)
- WinForms architecture and namespace (`CMDScanner`)

### Python GUI (`tools/position_checker/cmd_gui.py`) — New File

A Linux-native PyQt5 equivalent of the C# GUI, since the C# GUI only runs on Windows.

**Architecture:**

| Component | File | Purpose |
|---|---|---|
| `tcp_client.py` | `tools/position_checker/tcp_client.py` | Threaded TCP client with line-based receive loop |
| `cmd_gui.py` | `tools/position_checker/cmd_gui.py` | PyQt5 GUI — identical features to C# version |
| `cmd_main.py` | `tools/position_checker/cmd_main.py` | Entry point: `python -m tools.position_checker.cmd_main` |

**Why a separate TCP client class?** Qt's `QTcpSocket` requires the event loop to be running and has quirks with threading. A plain `socket` + `threading.Thread` with a callback queue is simpler and more reliable.

**Why PyQt5?** The existing `position_checker` tool already uses PyQt5 (via pyqtgraph). No new dependency.

---

## Protocol Compatibility Matrix

| Feature | CMD Original | Our Firmware | Notes |
|---|---|---|---|
| AP SSID/Password | `CMDCNC` / `cmdcnc1234` | `CMDCNC` / `cmdcnc1234` | Matched |
| AP IP | `192.168.1.50` | `192.168.1.50` | Matched |
| TCP Port | `8080` | `8080` | Matched |
| Data format | `X<v>,Y<v>,Z<v>\n` | `X<v>,Y<v>,Z<v>\n` | Identical |
| ZERO command | `ZERO` → `SIFIRLANDI` | `ZERO` → `ACK:ZERO` | Response differs but CMD GUI doesn't parse it |
| GET_IP | `GET_IP` → `STA_IP:<ip>` | `GET_IP` → `STA_IP:<ip>` | Identical |
| WiFi save | `WIFI_AYAR:` → `WIFI_KAYDEDILDI_REBOOT` | `WIFI_SET:` or `WIFI_AYAR:` → `ACK:WIFI_SAVED` | Both accepted; response differs but CMD GUI doesn't parse it |
| Sensor data | N/A | `SENSOR,r,theta,phi,valid,frame\n` | New — CMD GUI ignores it (no `X` prefix) |
| System info | N/A | `SYSINFO,rssi,heap,uptime,tcp_clients\n` | New — CMD GUI ignores it |
| NVS namespace | `ayarlar` | `wifi_cfg` | Different namespace but same keys (`ssid`, `pass`) |
| Encoder library | ESP32Encoder (PCNT) | PaulStoffregen Encoder (ISR) | Same quadrature math, different driver |
| Blocking model | Single client, blocking loop | Multi-client, non-blocking poll | CMD GUI sees no difference |

**Bottom line:** The original CMD C# GUI connects and works with our firmware without any modifications. Our updated GUIs add features on top of the same protocol.

---

## NVS Namespace Changes

| Purpose | CMD Original | Our Firmware | Keys |
|---|---|---|---|
| WiFi credentials | `ayarlar` | `wifi_cfg` | `ssid`, `pass` |
| Encoder calibration | N/A | `evka_cal` | `ppr_rotary`, `ppr_wire` |

**Why different namespace?** The CMD firmware stored WiFi credentials in `ayarlar` ("settings" in Turkish). We use `wifi_cfg` for clarity. This means WiFi credentials saved by the CMD firmware won't carry over — a one-time re-entry after flashing our firmware.

---

## What We Did NOT Change

| Item | Why kept as-is |
|---|---|
| Encoder library (PaulStoffregen) | Works correctly at our PPR. ESP32Encoder (PCNT) is safer at high PPR under WiFi load but would require testing all calibration values |
| WebSocket dashboard features | All existing features (3D trail, 2D projections, calibration tabs, CSV export) remain unchanged |
| Serial command protocol | All serial commands work identically — TCP is an additional interface |
| Coordinate math | Same spherical-to-Cartesian conversion, same EMA filter (alpha=0.2) |
| Update rate | 20 Hz (50ms period) — same as CMD's `delay(50)` |
| `CMD Soft/main.cpp` | Kept as reference code (excluded from build via `platformio.ini` filter) |

---

## Build Verification

```
$ pio run -e wemos_d1_r32
RAM:   [=         ]  14.1% (used 46256 bytes from 327680 bytes)
Flash: [=======   ]  68.1% (used 892069 bytes from 1310720 bytes)
========================= [SUCCESS] =========================
```

Both servers (HTTP+WS on :80 and raw TCP on :8080) fit comfortably within ESP32's resources.

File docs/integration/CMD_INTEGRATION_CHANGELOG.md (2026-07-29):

# CMD Protocol Integration — Changelog & Rationale

> **Archive / implementation history.** This file records the original integration and contains
> dated statements that are not the current handoff contract. The vendor C# application has been
> deleted; paths below into `firmware/src/CMD Soft/` are historical and no longer exist. The TCP
> protocol remains. Current main firmware uses `ESP32Encoder`, the canonical GUI is
> `tools/evka_gui`, and the current protocol reference is [../PROTOCOL.md](../PROTOCOL.md).

This document explains every change made to integrate the third-party CMD firmware/GUI protocol into the EvkaPosition system, and why each change was necessary.

For a short operational guide, see `docs/integration/CMD_SOFTWARE_INTEGRATION.md`.

## Background

At the time of integration, a third-party firm (CMD) provided ESP32 firmware
(`firmware/src/CMD Soft/main.cpp`) and a Windows C# GUI (`firmware/src/CMD Soft/gui.cs`). Those paths
are now deleted. Their system used:

- **WiFi AP**: SSID `CMDCNC`, password `cmdcnc1234`, static IP `192.168.1.50`
- **Raw TCP server** on port `8080`
- **Data format**: `X<val>,Y<val>,Z<val>\n` (e.g. `X123.45,Y-67.89,Z0.12\n`)
- **Commands**: `ZERO`, `GET_IP`, `WIFI_AYAR:<ssid>,<pass>` (Turkish)
- **Responses**: `SIFIRLANDI` (Turkish for "zeroed"), `STA_IP:<ip>`, `WIFI_KAYDEDILDI_REBOOT` (Turkish)
- **Encoder library**: ESP32Encoder (hardware PCNT)
- **NVS namespace**: `ayarlar` (Turkish for "settings")
- **Blocking architecture**: single-client, `while (client.connected())` loop with `delay(50)`

Our goal: make our hardware speak the same TCP protocol so the CMD GUI works with our device **unchanged**, while keeping our existing WebSocket dashboard and all its features.

---

## Firmware Changes

### 1. `firmware/src/SphericalSensor.h` — New Constants

| Constant | Value | Why |
|---|---|---|
| `ENABLE_CMD_TCP` | `1` | Feature flag — compile TCP server in/out without touching other code |
| `CMD_TCP_PORT` | `8080` | Must match CMD GUI's hardcoded port |
| `WIFI_AP_SSID` | `"CMDCNC_EVKA"` | Uses current project AP SSID while retaining CMD TCP/IP compatibility (`192.168.1.50:8080`) |
| `WIFI_AP_PASSWORD` | `"cmdcnc1234"` | Changed from `"evka1234"` to match CMD protocol |
| `WIFI_AP_IP_O1..O4` | `192.168.1.50` | CMD firmware uses `192.168.1.50` (we used `192.168.4.1`). Their GUI hardcodes this IP |
| `PIN_WIFI_LED` | `2` | GPIO 2 = built-in LED on most ESP32 boards, used for WiFi status indication |

**Why not just change the GUI?** The CMD GUI may be distributed to end users who won't update it. Matching their protocol means zero changes on the client side.

### 2. `firmware/src/CmdTcpServer.h` + `CmdTcpServer.cpp` — New Files

A dedicated TCP server class that runs alongside the existing HTTP+WebSocket server.

**Key design decisions:**

| Decision | Why |
|---|---|
| **Separate class** (not inline in `loop()`) | Keeps `EvkaPosition.cpp` clean; TCP server logic is self-contained |
| **Non-blocking `poll()` pattern** | CMD's original code used a blocking `while(client.connected())` loop — this freezes the entire MCU. Our non-blocking approach lets WebSocket, serial, and TCP all run concurrently |
| **Max 3 clients** | ESP32's lwIP stack has ~16 sockets total. HTTP+WS already use several. 3 TCP clients is a safe budget |
| **`setNoDelay(true)`** | Disables Nagle's algorithm (200ms batching). Without this, position data arrives in delayed bursts instead of real-time |
| **Per-client rx buffer with 128-byte limit** | Prevents a misbehaving client from consuming all heap with an endless string |

**Protocol compatibility — what CmdTcpServer sends:**

| Message | Format | Purpose |
|---|---|---|
| Position | `X<val>,Y<val>,Z<val>\n` | Identical to CMD format — their GUI parses this |
| Sensor data | `SENSOR,<r>,<theta>,<phi>,<valid>,<frame>\n` | **New** — our addition for richer GUIs. CMD GUI ignores lines not starting with `X` or `STA_IP:`, so this is safe |

**Commands handled directly by TCP server (not forwarded to main loop):**

| Command | Response | Why handled here |
|---|---|---|
| `GET_IP` | `STA_IP:<ip>` or `STA_IP:NOT_CONNECTED` | Matches CMD protocol. Response goes only to the requesting client |
| `WIFI_SET:<ssid>,<pass>` | `ACK:WIFI_SAVED` + reboot | NVS save + ESP restart. Also accepts `WIFI_AYAR:` for backward compat with original CMD GUI |

All other commands (`ZERO`, `PING`, `STATUS`, calibration commands, etc.) are forwarded to `processCommand()` in the main loop via `_pendingCmd`, and the reply is broadcast to all TCP clients.

### 3. `firmware/src/WebDashboard.cpp` — WiFi Init + HTML Additions

**WiFi initialization rewritten:**

```
Before:  WiFi.mode(WIFI_AP);  WiFi.softAP(ssid, pass);  // AP only, default 192.168.4.1
After:   WiFi.mode(WIFI_AP_STA);                         // AP + STA simultaneously
         WiFi.softAPConfig(192.168.1.50, ...);            // Static IP matching CMD
         WiFi.softAP(WIFI_AP_SSID, WIFI_AP_PASSWORD);
         // Load STA credentials from NVS "wifi_cfg" → WiFi.begin() if present
```

**Why AP+STA?** The device acts as an access point (clients connect directly) AND can join an existing WiFi network (for remote access, OTA, etc.). CMD's original firmware did this too.

**Why AP config before STA?** If STA init runs first and gets a DHCP address, the AP's DHCP server can conflict. AP-first avoids this.

**HTML/JS additions to the web dashboard** (all client-side, no firmware commands needed):

| Feature | What it does | Why |
|---|---|---|
| Per-axis software zero (X=0, Y=0, Z=0) | Subtracts current value as offset — display shows relative position | Matches CMD C# GUI behavior. Distinct from `ZERO` which resets encoder hardware |
| Min/Max tracking | Shows min and max values for each axis during the session | Useful for measuring travel range without external tools |
| Position snapshots | CAPTURE button logs X,Y,Z + timestamp to a table; export as CSV | Quick measurement recording without the full calibration workflow |
| WiFi settings | SSID/password inputs, SAVE & REBOOT, FORGET buttons | Lets users configure STA connection from the web dashboard |
| System info | RSSI, free heap, uptime, TCP client count | Diagnostic info; polls via `SYSINFO` command every 5 seconds |

### 4. `firmware/src/EvkaPosition.cpp` — Main Loop Integration

**New commands added to `processCommand()`:**

| Command | Response | Why |
|---|---|---|
| `GET_IP` | `STA_IP:<ip>` or `STA_IP:NOT_CONNECTED` | Needed by both GUIs and web dashboard to show router IP |
| `WIFI_SET:<ssid>,<pass>` | `ACK:WIFI_SAVED` + reboot | WiFi credential management from serial/WebSocket |
| `SYSINFO` | `SYSINFO,<rssi>,<heap>,<uptime_s>,<tcp_clients>` | System diagnostics for GUIs and web dashboard |

**WiFi LED logic (GPIO 2):**

| LED State | Meaning |
|---|---|
| OFF | No STA credentials configured (AP-only mode) |
| Blinking (500ms) | STA credentials exist but not yet connected (searching) |
| Solid ON | STA connected to router |

**TCP integration in `loop()`:**

```cpp
cmdTcp.poll();                    // Accept clients, read commands
String tcpCmd = cmdTcp.takePendingCommand();
if (tcpCmd.length() > 0) {
    String reply = processCommand(tcpCmd);
    if (reply.length() > 0) cmdTcp.sendToAllClients(reply.c_str());
}
// In the 50ms update block:
cmdTcp.broadcastPosition(x, y, z);      // X,Y,Z format
cmdTcp.broadcastSensorData(r, theta, phi, valid, frame);  // SENSOR format
```

### 5. `platformio.ini` — Build Filter

```
build_src_filter = +<src/> -<src/CMD Soft/>
```

**Historical reason:** The `CMD Soft/` folder contained reference code that used
`ESP32Encoder.h` (not then in the dependencies). Without this exclusion, PlatformIO attempted to
compile it and failed. The folder has since been deleted.

---

## GUI Changes

### C# GUI (`firmware/src/CMD Soft/gui.cs`) — Full Rewrite (Historical, Deleted)

The original CMD GUI was in Turkish with minimal features. We rewrote it in English with feature parity to our web dashboard.

**What changed and why:**

| Aspect | Original (CMD) | New | Why |
|---|---|---|---|
| Language | Turkish (SIFIRLA, BAĞLAN, etc.) | English | Project standard — all code and UI in English |
| Settings file | `ayarlar.txt` | `settings.txt` | English naming convention |
| WiFi command | `WIFI_AYAR:` | `WIFI_SET:` | English. Firmware accepts both for backward compatibility |
| Position display | X, Y, Z only | X, Y, Z + R, theta, phi + valid + frame | Richer diagnostic info using new `SENSOR,` message |
| Min/Max tracking | None | Per-axis min/max with reset button | Matches web dashboard feature |
| System info | None | RSSI, heap, uptime (polls `SYSINFO` every 5s) | Diagnostics without opening the web dashboard |
| WiFi settings | None visible | SSID/Password/SAVE/FORGET section | Configure STA connection from the GUI |
| Per-axis zero | None | X=0, Y=0, Z=0 buttons | Software zero with offset subtraction (client-side) |
| Hardware zero | "SIFIRLA" button | "Hardware Zero (Encoder)" with confirmation dialog | Prevents accidental encoder reset |

**What stayed the same:**

- TCP connection to port 8080
- Parsing of `X<val>,Y<val>,Z<val>\n` position data
- Parsing of `STA_IP:` responses
- Software zero offset subtraction approach (same logic as original)
- WinForms architecture and namespace (`CMDScanner`)

### Python GUI (`tools/position_checker/cmd_gui.py`) — New File

A Linux-native PyQt5 equivalent of the C# GUI, since the C# GUI only runs on Windows.

**Architecture:**

| Component | File | Purpose |
|---|---|---|
| `tcp_client.py` | `tools/position_checker/tcp_client.py` | Threaded TCP client with line-based receive loop |
| `cmd_gui.py` | `tools/position_checker/cmd_gui.py` | PyQt5 GUI — identical features to C# version |
| `cmd_main.py` | `tools/position_checker/cmd_main.py` | Entry point: `python -m tools.position_checker.cmd_main` |

**Why a separate TCP client class?** Qt's `QTcpSocket` requires the event loop to be running and has quirks with threading. A plain `socket` + `threading.Thread` with a callback queue is simpler and more reliable.

**Why PyQt5?** The existing `position_checker` tool already uses PyQt5 (via pyqtgraph). No new dependency.

---

## Protocol Compatibility Matrix

| Feature | CMD Original | Our Firmware | Notes |
|---|---|---|---|
| AP SSID/Password | `CMDCNC` / `cmdcnc1234` | `CMDCNC_EVKA` / `cmdcnc1234` | Password and IP/port are compatible; SSID string differs by project naming |
| AP IP | `192.168.1.50` | `192.168.1.50` | Matched |
| TCP Port | `8080` | `8080` | Matched |
| Data format | `X<v>,Y<v>,Z<v>\n` | `X<v>,Y<v>,Z<v>\n` | Identical |
| ZERO command | `ZERO` → `SIFIRLANDI` | `ZERO` → `ACK:ZERO` | Response differs but CMD GUI doesn't parse it |
| GET_IP | `GET_IP` → `STA_IP:<ip>` | `GET_IP` → `STA_IP:<ip>` | Identical |
| WiFi save | `WIFI_AYAR:` → `WIFI_KAYDEDILDI_REBOOT` | `WIFI_SET:` or `WIFI_AYAR:` → `ACK:WIFI_SAVED` | Both accepted; response differs but CMD GUI doesn't parse it |
| Sensor data | N/A | `SENSOR,r,theta,phi,valid,frame\n` | New — CMD GUI ignores it (no `X` prefix) |
| System info | N/A | `SYSINFO,rssi,heap,uptime,tcp_clients\n` | New — CMD GUI ignores it |
| NVS namespace | `ayarlar` | `wifi_cfg` | Different namespace but same keys (`ssid`, `pass`) |
| Encoder library | ESP32Encoder (PCNT) | PaulStoffregen Encoder (ISR) | Same quadrature math, different driver |
| Blocking model | Single client, blocking loop | Multi-client, non-blocking poll | CMD GUI sees no difference |

**Historical bottom line:** The original CMD C# GUI connected to the retained protocol. The vendor
application has since been deleted; current clients use `tools/evka_gui`.

---

## NVS Namespace Changes

| Purpose | CMD Original | Our Firmware | Keys |
|---|---|---|---|
| WiFi credentials | `ayarlar` | `wifi_cfg` | `ssid`, `pass` |
| Encoder calibration | N/A | `evka_cal` | `ppr_rotary`, `ppr_wire` |

**Why different namespace?** The CMD firmware stored WiFi credentials in `ayarlar` ("settings" in Turkish). We use `wifi_cfg` for clarity. This means WiFi credentials saved by the CMD firmware won't carry over — a one-time re-entry after flashing our firmware.

---

## What We Did NOT Change

| Item | Why kept as-is |
|---|---|
| Encoder library (PaulStoffregen) | Works correctly at our PPR. ESP32Encoder (PCNT) is safer at high PPR under WiFi load but would require testing all calibration values |
| WebSocket dashboard features | All existing features (3D trail, 2D projections, calibration tabs, CSV export) remain unchanged |
| Serial command protocol | All serial commands work identically — TCP is an additional interface |
| Coordinate math | Same spherical-to-Cartesian conversion, same EMA filter (alpha=0.2) |
| Update rate | 20 Hz (50ms period) — same as CMD's `delay(50)` |
| `CMD Soft/main.cpp` | Was kept as reference code during integration and was later deleted |

---

## Build Verification

```
$ pio run -e wemos_d1_r32
RAM:   [=         ]  14.1% (used 46256 bytes from 327680 bytes)
Flash: [=======   ]  68.1% (used 892069 bytes from 1310720 bytes)
========================= [SUCCESS] =========================
```

Both servers (HTTP+WS on :80 and raw TCP on :8080) fit comfortably within ESP32's resources.

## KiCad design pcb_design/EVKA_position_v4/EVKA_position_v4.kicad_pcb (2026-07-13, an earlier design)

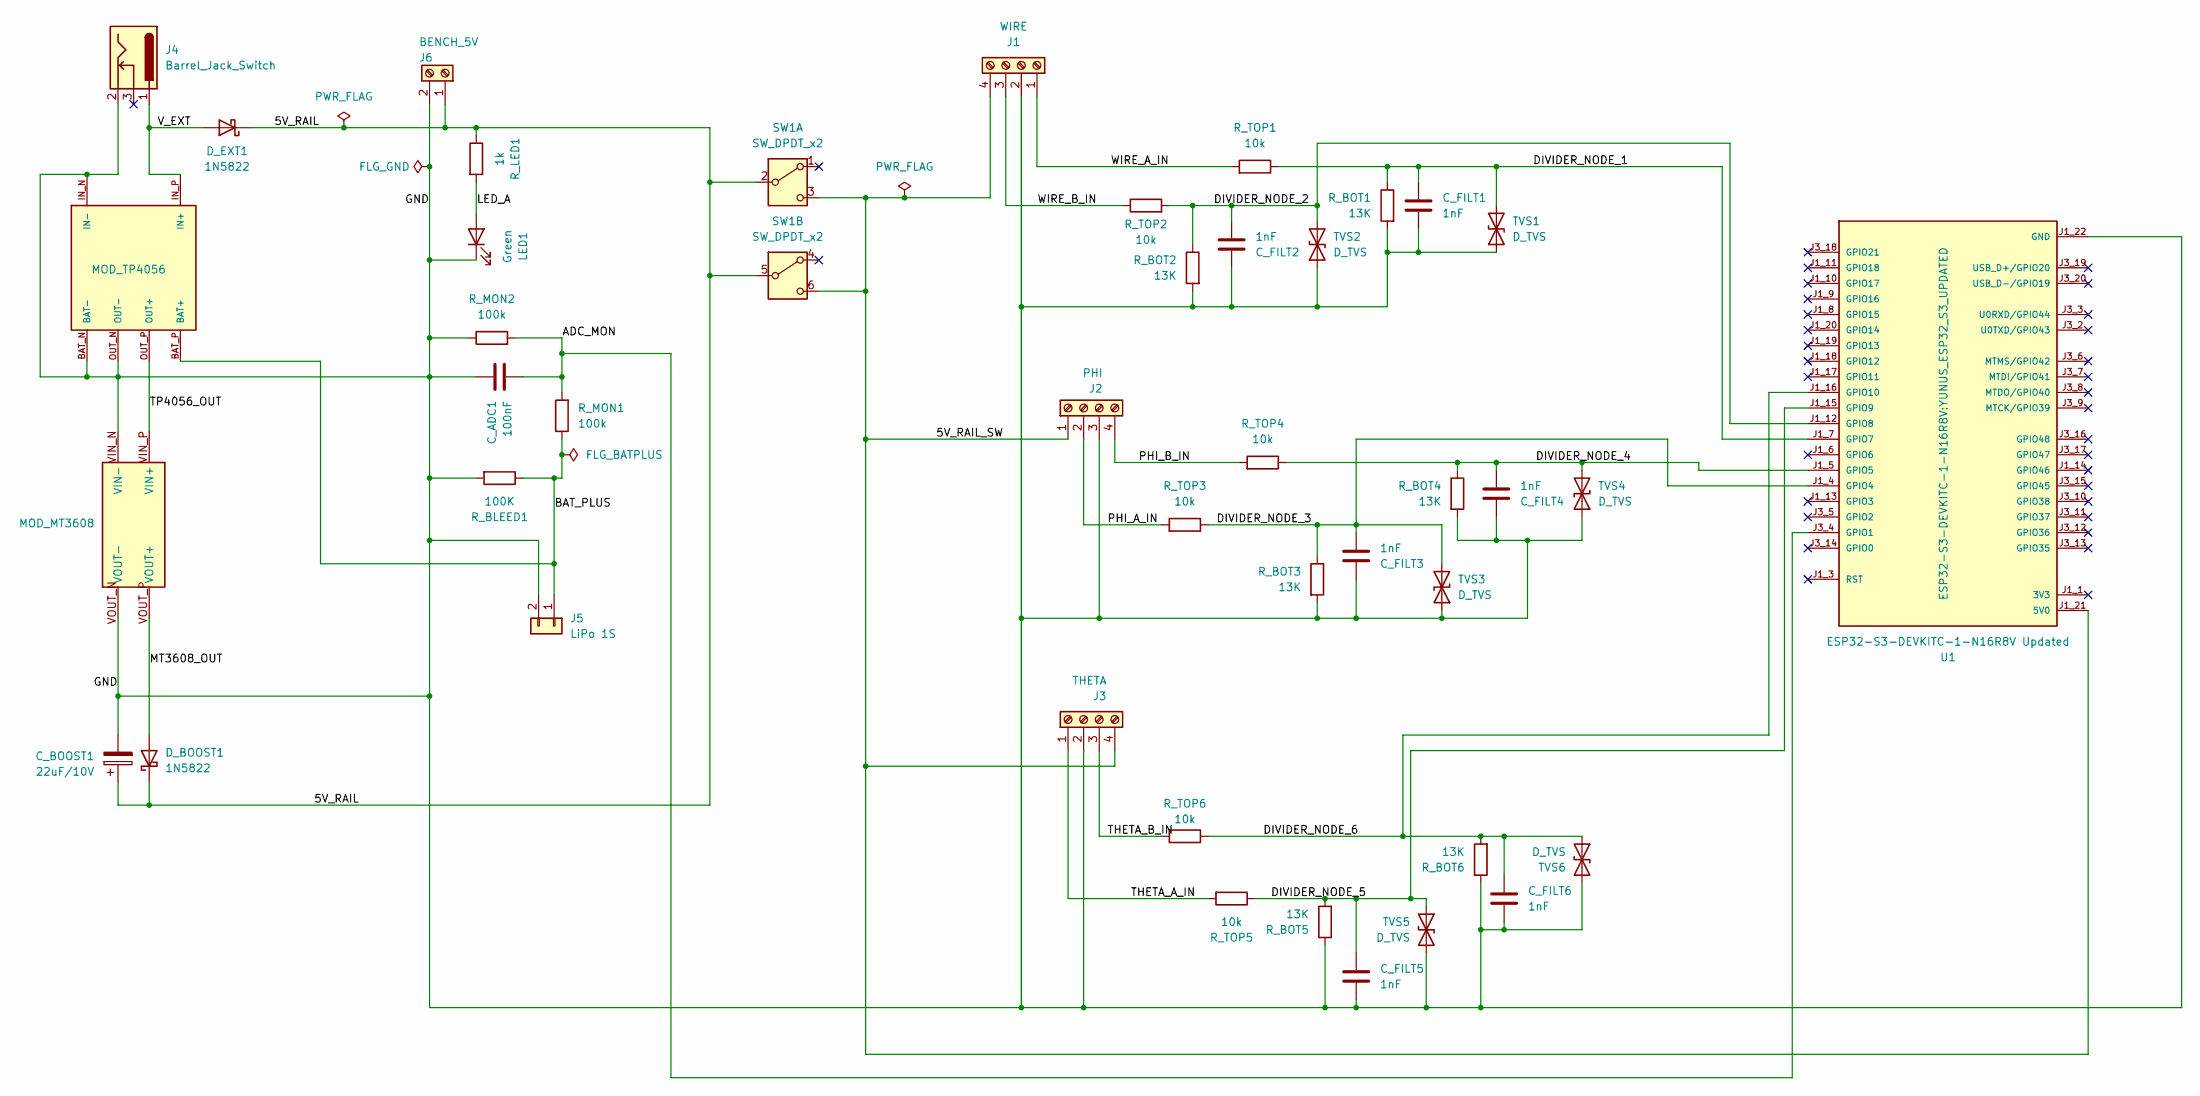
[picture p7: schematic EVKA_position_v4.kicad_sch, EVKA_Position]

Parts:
C_ADC1: 100nF; C_Disc_D5.0mm_W2.5mm_P5.00mm
C_BOOST1: 22uF/10V; CP_Radial_D5.0mm_P2.50mm
C_FILT1, C_FILT2, C_FILT3, C_FILT4, C_FILT5, C_FILT6: 1nF; C_Disc_D5.0mm_W2.5mm_P5.00mm
D_BOOST1: 1N5822; D_DO-201AD_P15.24mm_Horizontal
D_EXT1: 1N5822; D_DO-201AD_P15.24mm_Horizontal
J1: WIRE; TerminalBlock_Phoenix_MKDS-1,5-4_1x04_P5.00mm_Horizontal
J2: PHI; TerminalBlock_Phoenix_MKDS-1,5-4_1x04_P5.00mm_Horizontal
J3: THETA; TerminalBlock_Phoenix_MKDS-1,5-4_1x04_P5.00mm_Horizontal
J4: Barrel_Jack_Switch; BarrelJack_CUI_PJ-102AH_Horizontal
J5: LiPo 1S; JST_PH_B2B-PH-K_1x02_P2.00mm_Vertical
J6: BENCH_5V; TerminalBlock_Phoenix_MKDS-1,5-2_1x02_P5.00mm_Horizontal
LED1: Green; LED_D5.0mm
MOD_MT3608: MT3608 Updated; MODULE_MT3608_DC-DC_STEP_UP_CONVERTER_2A_BOOSTER_MODULE
MOD_TP4056: TP4056_MICRO-USB_CHARGER_-_1A; MODULE_TP4056_MICRO-USB_CHARGER_-_1A
R_BLEED1: 100K; R_Axial_DIN0207_L6.3mm_D2.5mm_P7.62mm_Horizontal
R_BOT1, R_BOT2, R_BOT3, R_BOT4, R_BOT5, R_BOT6: 13K; R_Axial_DIN0207_L6.3mm_D2.5mm_P7.62mm_Horizontal
R_LED1: 1k; R_Axial_DIN0207_L6.3mm_D2.5mm_P7.62mm_Horizontal
R_MON1, R_MON2: 100k; R_Axial_DIN0207_L6.3mm_D2.5mm_P7.62mm_Horizontal
R_TOP1, R_TOP2, R_TOP3, R_TOP4, R_TOP5, R_TOP6: 10k; R_Axial_DIN0207_L6.3mm_D2.5mm_P7.62mm_Horizontal
SW1: SW_DPDT_x2; SW_NKK_G1xJP
TVS1, TVS2, TVS3, TVS4, TVS5, TVS6: D_TVS; D_DO-35_SOD27_P7.62mm_Horizontal
U1: ESP32-S3-DEVKITC-1-N16R8V Updated; YUNUS_ESP32_S3_UPDATED; PARTREV 1.1

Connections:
/5V_RAIL: C_BOOST1.1, D_BOOST1.1 (K), D_EXT1.1 (K), J6.1, R_LED1.1, SW1.2 (B), SW1.5 (B)
/5V_RAIL_SW: J1.4, J2.1, J3.4, SW1.3 (C), SW1.6 (C), U1.J1_21 (5V0)
/ADC_MON: C_ADC1.2, R_MON1.2, R_MON2.2, U1.J3_4 (GPIO1)
/BAT_PLUS: J5.1, MOD_TP4056.BAT_P (BAT+), R_BLEED1.1, R_MON1.1
/DIVIDER_NODE_1: C_FILT1.1, R_BOT1.1, R_TOP1.1, TVS1.2 (A2), U1.J1_7 (GPIO7)
/DIVIDER_NODE_2: C_FILT2.2, R_BOT2.1, R_TOP2.2, TVS2.2 (A2), U1.J1_12 (GPIO8)
/DIVIDER_NODE_3: C_FILT3.2, R_BOT3.1, R_TOP3.1, TVS3.2 (A2), U1.J1_4 (GPIO4)
/DIVIDER_NODE_4: C_FILT4.2, R_BOT4.1, R_TOP4.1, TVS4.2 (A2), U1.J1_5 (GPIO5)
/DIVIDER_NODE_5: C_FILT5.1, R_BOT5.2, R_TOP5.1, TVS5.1 (A1), U1.J1_15 (GPIO9)
/DIVIDER_NODE_6: C_FILT6.1, R_BOT6.2, R_TOP6.1, TVS6.1 (A1), U1.J1_16 (GPIO10)
/LED_A: LED1.2 (A), R_LED1.2
/MT3608_OUT: D_BOOST1.2 (A), MOD_MT3608.VOUT_P (VOUT+)
/PHI_A_IN: J2.2, R_TOP3.2
/PHI_B_IN: J2.4, R_TOP4.2
/THETA_A_IN: J3.1, R_TOP5.2
/THETA_B_IN: J3.3, R_TOP6.2
/TP4056_OUT: MOD_MT3608.VIN_P (VIN+), MOD_TP4056.OUT_P (OUT+)
/V_EXT: D_EXT1.2 (A), J4.1, MOD_TP4056.IN_P (IN+)
/WIRE_A_IN: J1.1, R_TOP1.2
/WIRE_B_IN: J1.3, R_TOP2.1
GND: C_ADC1.1, C_BOOST1.2, C_FILT1.2, C_FILT2.1, C_FILT3.1, C_FILT4.1, C_FILT5.2, C_FILT6.2, J1.2, J2.3, J3.2, J4.2, J5.2, J6.2, LED1.1 (K), MOD_MT3608.VIN_N (VIN-), MOD_MT3608.VOUT_N (VOUT-), MOD_TP4056.BAT_N (BAT-), MOD_TP4056.IN_N (IN-), MOD_TP4056.OUT_N (OUT-), R_BLEED1.2, R_BOT1.2, R_BOT2.2, R_BOT3.2, R_BOT4.2, R_BOT5.1, R_BOT6.1, R_MON2.1, TVS1.1 (A1), TVS2.1 (A1), TVS3.1 (A1), TVS4.1 (A1), TVS5.2 (A2), TVS6.2 (A2), U1.J1_22 (GND), U1.J3_1 (GND), U1.J3_21 (GND), U1.J3_22 (GND)

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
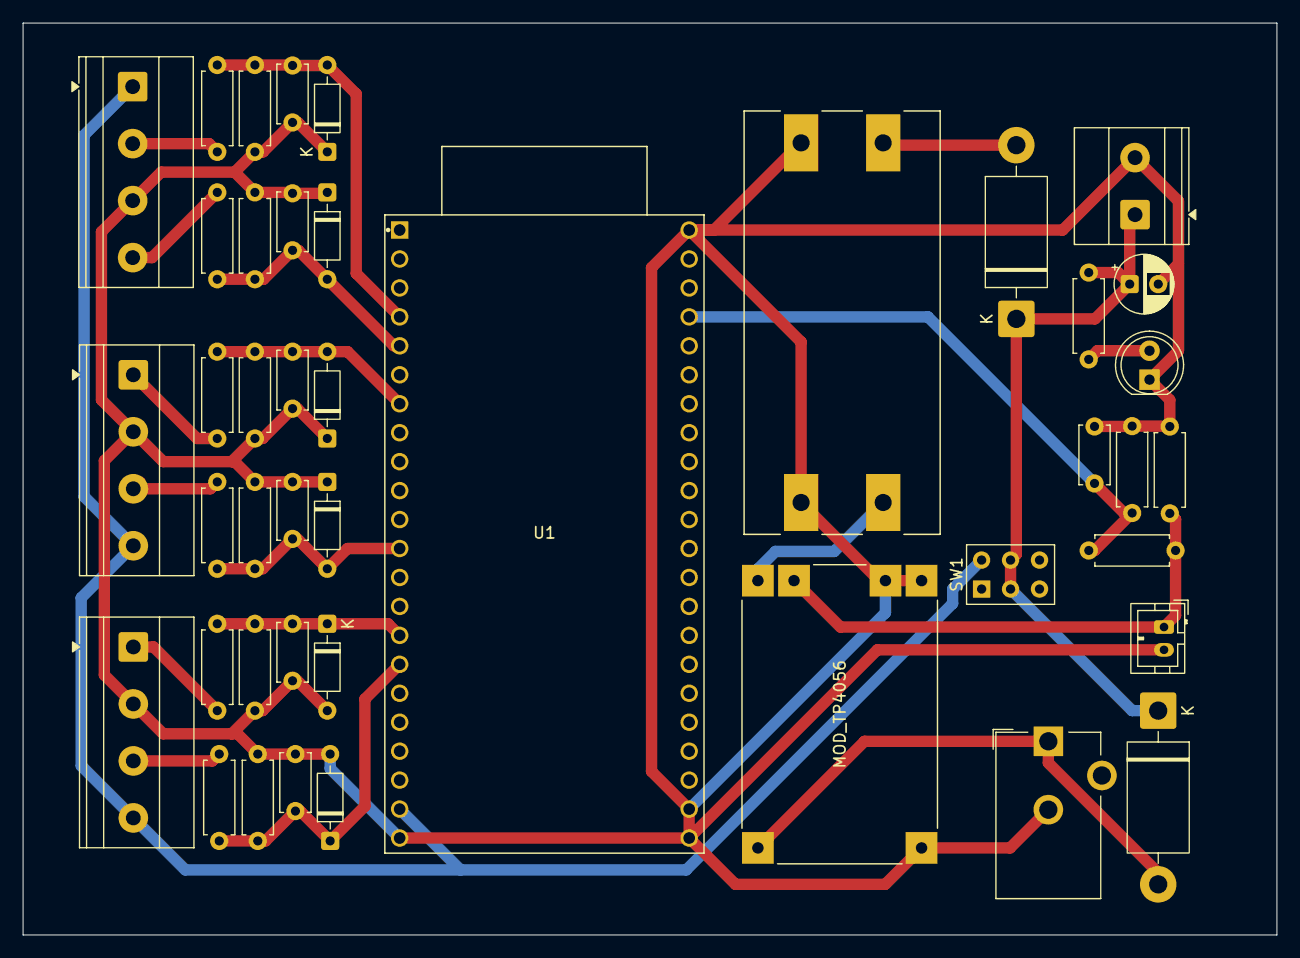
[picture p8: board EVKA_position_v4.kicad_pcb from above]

Board: 2 copper layers, 110.0 x 80.0 mm, 43 parts (0 on the bottom side), 21 nets.

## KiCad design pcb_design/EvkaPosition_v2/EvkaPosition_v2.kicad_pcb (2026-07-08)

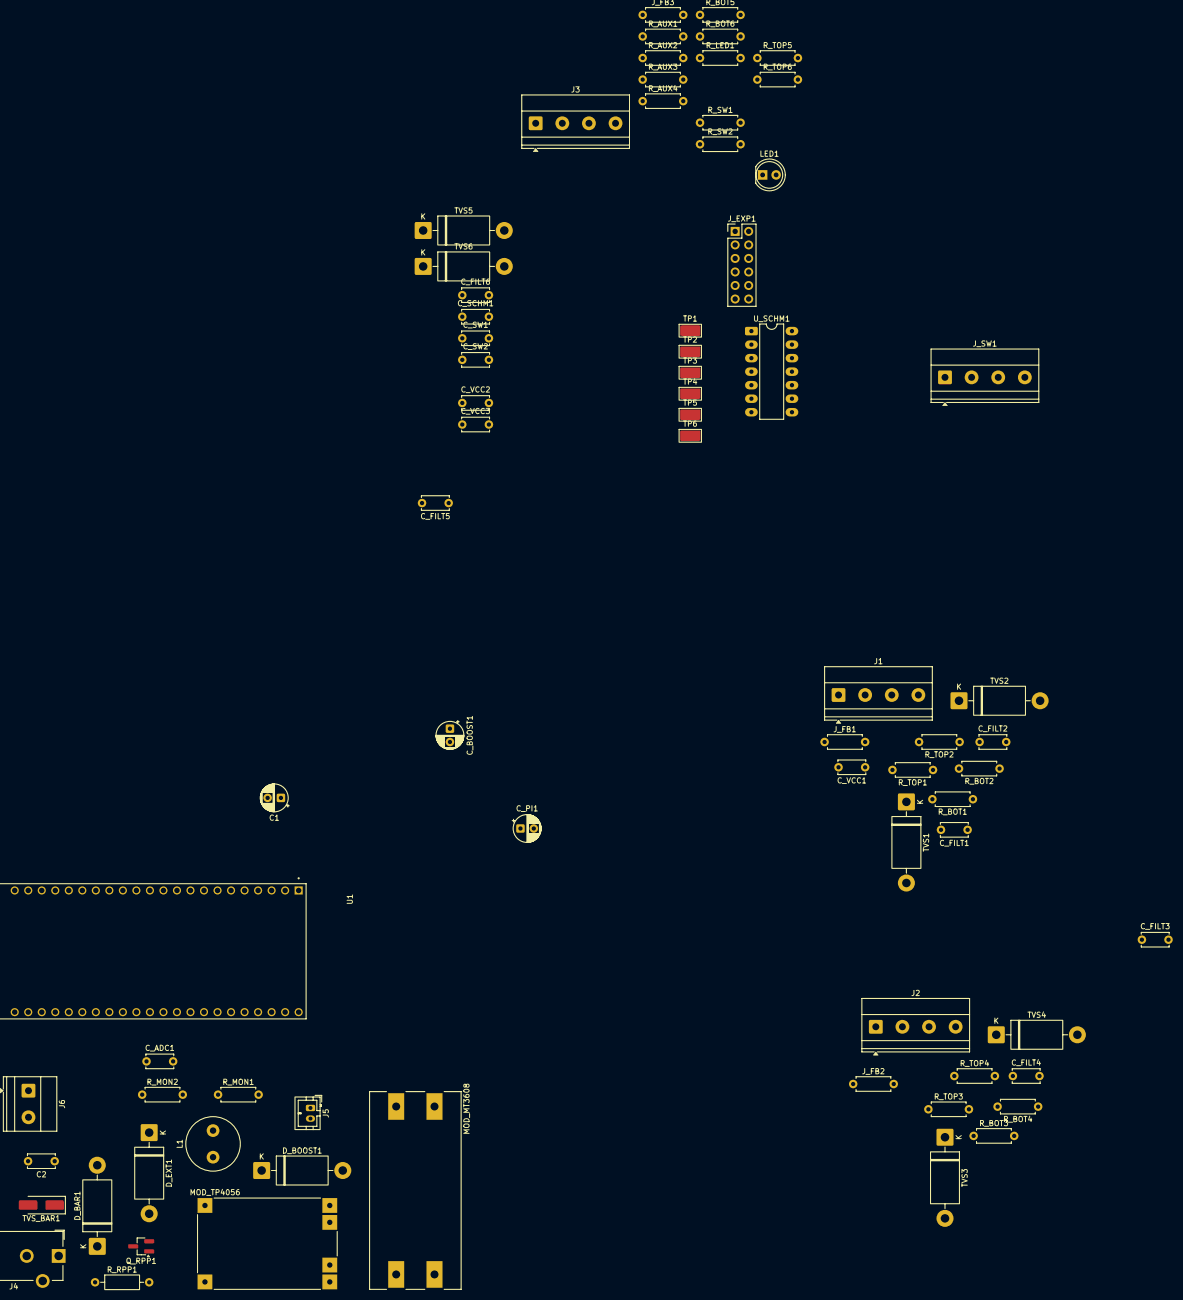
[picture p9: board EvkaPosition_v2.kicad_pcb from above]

Board: 2 copper layers, 73 parts (0 on the bottom side), 44 nets, no tracks yet.

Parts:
C1: 220uF/10V; CP_Radial_D5.0mm_P2.50mm
C2: 100nF; C_Disc_D5.0mm_W2.5mm_P5.00mm
C_ADC1: 100nF; C_Disc_D5.0mm_W2.5mm_P5.00mm
C_BOOST1: 22uF/10V; CP_Radial_D5.0mm_P2.50mm
C_FILT1, C_FILT2, C_FILT3, C_FILT4, C_FILT5, C_FILT6: 10nF; C_Disc_D5.0mm_W2.5mm_P5.00mm
C_PI1: 10uF/10V; CP_Radial_D5.0mm_P2.50mm
C_SCHM1: 100nF; C_Disc_D5.0mm_W2.5mm_P5.00mm
C_SW1, C_SW2: 100nF; C_Disc_D5.0mm_W2.5mm_P5.00mm
C_VCC1, C_VCC2, C_VCC3: 100nF; C_Disc_D5.0mm_W2.5mm_P5.00mm
D_BAR1: 1N5822; D_DO-201AD_P15.24mm_Horizontal
D_BOOST1: 1N5822; D_DO-201AD_P15.24mm_Horizontal
D_EXT1: 1N5822; D_DO-201AD_P15.24mm_Horizontal
J1: THETA; TerminalBlock_Phoenix_MKDS-1,5-4_1x04_P5.00mm_Horizontal
J2: PHI; TerminalBlock_Phoenix_MKDS-1,5-4_1x04_P5.00mm_Horizontal
J3: WIRE; TerminalBlock_Phoenix_MKDS-1,5-4_1x04_P5.00mm_Horizontal
J4: Barrel_Jack_Switch; BarrelJack_CUI_PJ-102AH_Horizontal
J5: LiPo 1S; JST_PH_B2B-PH-K_1x02_P2.00mm_Vertical
J6: BENCH_5V; TerminalBlock_Phoenix_MKDS-1,5-2_1x02_P5.00mm_Horizontal
J_EXP1: AUX_IO; PinHeader_2x06_P2.54mm_Vertical
J_FB1, J_FB2, J_FB3: 0R; R_Axial_DIN0207_L6.3mm_D2.5mm_P7.62mm_Horizontal
J_SW1: SWITCHES; TerminalBlock_Phoenix_MKDS-1,5-4_1x04_P5.00mm_Horizontal
L1: 10uH; L_Radial_D10.0mm_P5.00mm_Neosid_SD12_style3
LED1: Green; LED_D5.0mm
MOD_MT3608: MT3608_DC-DC_STEP_UP_CONVERTER_2A_BOOSTER_MODULE; MODULE_MT3608_DC-DC_STEP_UP_CONVERTER_2A_BOOSTER_MODULE
MOD_TP4056: TP4056_MICRO-USB_CHARGER_-_1A; MODULE_TP4056_MICRO-USB_CHARGER_-_1A
Q_RPP1: PJA3441; SOT-23_Handsoldering
R_AUX1, R_AUX2, R_AUX3, R_AUX4: 100R; R_Axial_DIN0207_L6.3mm_D2.5mm_P7.62mm_Horizontal
R_BOT1, R_BOT2, R_BOT3, R_BOT4, R_BOT5, R_BOT6: 20k; R_Axial_DIN0207_L6.3mm_D2.5mm_P7.62mm_Horizontal
R_LED1: 1k; R_Axial_DIN0207_L6.3mm_D2.5mm_P7.62mm_Horizontal
R_MON1, R_MON2: 100k; R_Axial_DIN0207_L6.3mm_D2.5mm_P7.62mm_Horizontal
R_RPP1: 100k; R_Axial_DIN0207_L6.3mm_D2.5mm_P10.16mm_Horizontal
R_SW1, R_SW2: 10k; R_Axial_DIN0207_L6.3mm_D2.5mm_P7.62mm_Horizontal
R_TOP1, R_TOP2, R_TOP3, R_TOP4, R_TOP5, R_TOP6: 10k; R_Axial_DIN0207_L6.3mm_D2.5mm_P7.62mm_Horizontal
TP1: 5V_RAIL; TestPoint_Keystone_5019_Miniature
TP2: 3V3; TestPoint_Keystone_5019_Miniature
TP3: MT3608_OUT; TestPoint_Keystone_5019_Miniature
TP4: BAT+; TestPoint_Keystone_5019_Miniature
TP5: BAT_OUT; TestPoint_Keystone_5019_Miniature
TP6: GND; TestPoint_Keystone_5019_Miniature
TVS1, TVS2, TVS3, TVS4, TVS5, TVS6: D_TVS; D_DO-201AD_P15.24mm_Horizontal
TVS_BAR1: SMAJ5.0A; D_SMA_Handsoldering
U1: ESP32-S3-DEVKITC-1-N16R8V; XCVR_ESP32-S3-DEVKITC-1-N16R8V
U_SCHM1: 74HC14; DIP-14_W7.62mm_LongPads

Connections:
3V3: C_SCHM1.2, J_EXP1.9, J_SW1.4, R_SW1.2, R_SW2.2, TP2.1 (1_1), U1.J1_1 (3V3), U1.J1_2 (3V3), U_SCHM1.14 (VCC)
/+5V: C1.1, C2.1, J6.1, J_EXP1.11, J_FB1.1, J_FB2.1, J_FB3.2, L1.2, R_LED1.1, TP1.1 (1_1), U1.J1_21 (5V0)
/ADC_MON: C_ADC1.2, R_MON1.1, R_MON2.2, U1.J3_4 (GPIO1)
/AUX1: J_EXP1.1, R_AUX1.2
/AUX2: J_EXP1.3, R_AUX2.2
/AUX3: J_EXP1.5, R_AUX3.2
/AUX4: J_EXP1.7, R_AUX4.2
/BAT_OUT: MOD_MT3608.VIN_P (VIN+), MOD_TP4056.OUT_P (OUT+), TP5.1 (1_1)
/BAT_PLUS: J5.1, MOD_TP4056.BAT_P (BAT+), R_MON1.2, TP4.1 (1_1)
/BTN1: C_SW1.2, J_SW1.2, R_SW1.1, U1.J1_10 (GPIO17)
/BTN2: C_SW2.2, J_SW1.3, R_SW2.1, U1.J1_11 (GPIO18)
/DIVIDER_NODE_1: C_FILT1.2, R_BOT1.2, R_TOP1.1, TVS1.1 (A1), U_SCHM1.1
/DIVIDER_NODE_2: C_FILT2.1, R_BOT2.2, R_TOP2.1, TVS2.1 (A1), U_SCHM1.3
/DIVIDER_NODE_3: C_FILT3.1, R_BOT3.2, R_TOP3.1, TVS3.1 (A1), U_SCHM1.9
/DIVIDER_NODE_4: C_FILT4.1, R_BOT4.2, R_TOP4.1, TVS4.1 (A1), U_SCHM1.5
/DIVIDER_NODE_5: C_FILT5.1, R_BOT5.2, R_TOP5.1, TVS5.1 (A1), U_SCHM1.11
/DIVIDER_NODE_6: C_FILT6.1, R_BOT6.2, R_TOP6.1, TVS6.1 (A1), U_SCHM1.13
/ENC_VCC1: C_VCC1.1, J1.2, J_FB1.2
/ENC_VCC2: C_VCC2.1, J2.2, J_FB2.2
/ENC_VCC3: C_VCC3.1, J3.2, J_FB3.1
/LED_A: LED1.2 (A), R_LED1.2
/MT3608_OUT: C_BOOST1.1, D_BOOST1.2 (A), MOD_MT3608.VOUT_P (VOUT+), TP3.1 (1_1)
/PHI_A_IN: J2.3, R_TOP3.2
/PHI_A_OUT: U1.J1_6 (GPIO6), U_SCHM1.8
/PHI_B_IN: J2.4, R_TOP4.2
/PHI_B_OUT: U1.J1_7 (GPIO7), U_SCHM1.6
/PI_NODE: C_PI1.1, D_BOOST1.1 (K), D_EXT1.1 (K), L1.1
/RPP_GATE: Q_RPP1.1 (G), R_RPP1.2
/THETA_A_IN: J1.3, R_TOP1.2
/THETA_A_OUT: U1.J1_4 (GPIO4), U_SCHM1.2
/THETA_B_IN: J1.4, R_TOP2.2
/THETA_B_OUT: U1.J1_5 (GPIO5), U_SCHM1.4
/V_EXT_PROT: D_EXT1.2 (A), MOD_TP4056.IN_P (IN+), Q_RPP1.2 (S)
/V_EXT_RAW: D_BAR1.1 (K), Q_RPP1.3 (D)
/V_IN_JACK: D_BAR1.2 (A), J4.1, TVS_BAR1.1 (A1)
/WIRE_A_IN: J3.3, R_TOP5.2
/WIRE_A_OUT: U1.J1_8 (GPIO15), U_SCHM1.10
/WIRE_B_IN: J3.4, R_TOP6.2
/WIRE_B_OUT: U1.J1_9 (GPIO16), U_SCHM1.12
GND: C1.2, C2.2, C_ADC1.1, C_BOOST1.2, C_FILT1.1, C_FILT2.2, C_FILT3.2, C_FILT4.2, C_FILT5.2, C_FILT6.2, C_PI1.2, C_SCHM1.1, C_SW1.1, C_SW2.1, C_VCC1.2, C_VCC2.2, C_VCC3.2, J1.1, J2.1, J3.1, J4.2, J5.2, J6.2, J_EXP1.2, J_EXP1.4, J_EXP1.6, J_EXP1.8, J_EXP1.10, J_EXP1.12, J_SW1.1, LED1.1 (K), MOD_MT3608.VIN_N (VIN-), MOD_MT3608.VOUT_N (VOUT-), MOD_TP4056.BAT_N (BAT-), MOD_TP4056.IN_N (IN-), MOD_TP4056.OUT_N (OUT-), R_BOT1.1, R_BOT2.1, R_BOT3.1, R_BOT4.1, R_BOT5.1, R_BOT6.1, R_MON2.1, R_RPP1.1, TP6.1 (1_1), TVS1.2 (A2), TVS2.2 (A2), TVS3.2 (A2), TVS4.2 (A2), TVS5.2 (A2), TVS6.2 (A2), TVS_BAR1.2 (A2), U1.J1_22 (GND), U1.J3_1 (GND), U1.J3_21 (GND), U1.J3_22 (GND), U_SCHM1.7 (GND)
unnamed: R_AUX1.1, U1.J1_17 (GPIO11)
unnamed: R_AUX2.1, U1.J1_18 (GPIO12)
unnamed: R_AUX3.1, U1.J1_19 (GPIO13)
unnamed: R_AUX4.1, U1.J1_20 (GPIO14)

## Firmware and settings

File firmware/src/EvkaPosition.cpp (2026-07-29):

#include "SphericalSensor.h"
#include "StatusLed.h"
#include <Preferences.h>
#include <stdlib.h>

#if ENABLE_WIFI
#include <WiFi.h>
#include "WebDashboard.h"
WebDashboard dashboard;
#endif

#if ENABLE_WIFI && ENABLE_CMD_TCP
#include "CmdTcpServer.h"
CmdTcpServer cmdTcp;
#endif

#if ENABLE_WIFI && ENABLE_ESPNOW_REMOTE
#include <esp_now.h>
#include <esp_wifi.h>

// ---- ESP-NOW wireless button remote receiver ----
static volatile int8_t espnow_pending_button    = -1;
static volatile bool   espnow_pending_heartbeat = false;

static const char* const REMOTE_BUTTON_CMD[] = {
    "SAVE_POINT",  // Button 0 — Green — GPIO 4
    "DEL_POINT",   // Button 1 — Red   — GPIO 5
    nullptr,       // Button 2 — GPIO 0 — unassigned
    nullptr,       // Button 3 — GPIO 1 — unassigned
    nullptr,       // Button 4 — GPIO 3 — unassigned
};
static constexpr uint8_t REMOTE_BUTTON_COUNT = 5;

#if ESP_IDF_VERSION >= ESP_IDF_VERSION_VAL(5, 0, 0)
static void onEspNowRecv(const esp_now_recv_info_t* info, const uint8_t* data, int len) {
#else
static void onEspNowRecv(const uint8_t* mac, const uint8_t* data, int len) {
#endif
    if (len >= 1) {
        if (data[0] == 0xFE) {
            espnow_pending_heartbeat = true;
        } else if (data[0] < REMOTE_BUTTON_COUNT) {
            espnow_pending_button = (int8_t)data[0];
        }
    }
}

static bool initEspNow() {
    // Print the channel the AP is actually on so we can verify it matches
    // the remote's ESPNOW_CHANNEL define.
    uint8_t primary; wifi_second_chan_t second;
    esp_wifi_get_channel(&primary, &second);
    Serial.printf("[ESP-NOW] AP channel: %u (remote must match)\n", primary);

    if (esp_now_init() != ESP_OK) {
        Serial.println("[ESP-NOW] Init FAILED");
        return false;
    }
    esp_now_register_recv_cb(onEspNowRecv);
    Serial.println("[ESP-NOW] Remote receiver ready");
    return true;
}
#endif // ENABLE_WIFI && ENABLE_ESPNOW_REMOTE

// ============================================================================
// ESP32 PLATFORMIO ENTRY POINT
// ============================================================================

SphericalPositioningSensor sensor;
StatusLed statusLed;

static bool g_boot_calibrating = false;
#if ENABLE_WIFI && ENABLE_ESPNOW_REMOTE
static bool g_espnow_fault = false;
#endif

// Update Frequency
#define UPDATE_PERIOD_MS  50  // 20 Hz position update rate

static String serial_buffer;
static bool g_restart_pending = false;
static uint32_t g_restart_at_ms = 0;

static StatusLedInputs buildStatusLedInputs() {
    StatusLedInputs in = {};
#if ENABLE_WIFI
    in.wifi_enabled = true;
    in.sta_configured = dashboard.isStaConfigured();
    in.sta_connected = dashboard.isStaConnected();
#else
    in.wifi_enabled = false;
#endif
    in.boot_calibrating = g_boot_calibrating;
#if ENABLE_WIFI && ENABLE_ESPNOW_REMOTE
    in.espnow_fault = g_espnow_fault;
#endif
    in.position_valid = (sensor.getStatus().is_valid != 0);
    return in;
}

static void tickStatusLed() {
    statusLed.update(buildStatusLedInputs());
}

static void waitWithStatusLed(uint32_t ms) {
    const uint32_t start = millis();
    while ((int32_t)(millis() - start) < (int32_t)ms) {
        tickStatusLed();
        delay(10);
    }
}

static String buildStatusLine() {
    SystemStatus st = sensor.getStatus();
    char buf[128];
    snprintf(buf, sizeof(buf),
        "STATUS,%u,%lu,%lu,%.2f,%.3f,%.3f,%.2f,%.2f,%.2f",
        st.is_valid, (unsigned long)st.frame_count, (unsigned long)st.last_update_ms,
        st.spherical.r_mm, st.spherical.theta_deg, st.spherical.phi_deg,
        st.position.x_mm, st.position.y_mm, st.position.z_mm);
    return String(buf);
}

#if ENABLE_BATTERY_MONITOR
static String buildBatteryLine() {
    BatteryStatus bat = sensor.readBattery();
    char buf[40];
    snprintf(buf, sizeof(buf), "BATT,%.3f,%u,%u",
             bat.voltage, bat.percentage, bat.is_low ? 1 : 0);
    return String(buf);
}
#endif

static bool parseFiniteFloat(const String& text, float& value) {
    String arg(text);
    arg.trim();
    if (arg.length() == 0) return false;

    const char* start = arg.c_str();
    char* end = nullptr;
    value = strtof(start, &end);
    return end != start && *end == '\0' && isfinite(value);
}

static void sendBatteryLineToWireless() {
#if ENABLE_WIFI && ENABLE_BATTERY_MONITOR
    String batt = buildBatteryLine();
    dashboard.broadcast(batt.c_str());
#if ENABLE_CMD_TCP
    cmdTcp.sendToAllClients(batt.c_str());
#endif
#endif
}

// Returns exactly one primary protocol reply. The ingress dispatcher emits it once.
static String processCommand(String cmd) {
    cmd.trim();
    static uint32_t pt_idx = 0;  // shared across SAVE_POINT and DEL_POINT
    if (cmd == "ZERO") {
        sensor.setZeroPoint();
        statusLed.flashZeroAck();
        return "ACK:ZERO";

    } else if (cmd == "PING") {
        return "ACK:PONG";

    } else if (cmd == "BLINK") {
        // Connection test: flash the status LED bright white for ~700 ms so the
        // operator can visually confirm the ESP32 received a command (works over
        // serial, TCP, and WebSocket). No-op on boards without the RGB LED.
        statusLed.flashOverlay(255, 255, 255, 700);
        return "ACK:BLINK";

    } else if (cmd == "STATUS") {
        return buildStatusLine();

    } else if (cmd == "ZERO_T") {
        sensor.zeroTheta();
        statusLed.flashZeroAck();
        return "ACK:ZERO_T";

    } else if (cmd == "ZERO_P") {
        sensor.zeroPhi();
        statusLed.flashZeroAck();
        return "ACK:ZERO_P";

    } else if (cmd == "ZERO_W") {
        sensor.zeroWire();
        statusLed.flashZeroAck();
        return "ACK:ZERO_W";

    } else if (cmd == "CONSTANTS") {
        char buf[96];
        sensor.getConstants(buf, sizeof(buf));
        return String(buf);

    } else if (cmd == "RAW_COUNTS") {
        // readRawEncoders() subtracts the latest hardware-zero offsets.
        int32_t tc, pc, wc;
        sensor.readRawEncoders(tc, pc, wc);
        char buf[64];
        snprintf(buf, sizeof(buf), "RAW,%ld,%ld,%ld", (long)tc, (long)pc, (long)wc);
        return String(buf);

    } else if (cmd.startsWith("CAL_W ")) {
        float actual_mm = 0.0f;
        if (!parseFiniteFloat(cmd.substring(6), actual_mm) || actual_mm <= 0.0f) {
            return "ERR:CAL_W bad value";
        }
        int32_t tc, pc, wc;
        sensor.readRawEncoders(tc, pc, wc);
        if (wc == 0) return "ERR:CAL_W zero counts";
        const float cur_mm_pp = DRUM_CIRCUM_MM / sensor.getPPRWire();  // use runtime-calibrated value
        const float measured_mm = fabsf((float)wc) * cur_mm_pp;
        float factor = actual_mm / measured_mm;
        if (!isfinite(factor) || factor < 0.1f || factor > 10.0f) {
            return "ERR:CAL_W factor out of range";
        }
        float new_mm_pp = cur_mm_pp * factor;
        float new_ppr_w = DRUM_CIRCUM_MM / new_mm_pp;
        if (!isfinite(new_ppr_w) || new_ppr_w < 100.0f || new_ppr_w > 500000.0f) {
            return "ERR:CAL_W PPR out of range";
        }
        char buf[96];
        snprintf(buf, sizeof(buf), "CAL:WIRE,%.4f,%.6f,%.2f", factor, new_mm_pp, new_ppr_w);
        return String(buf);

    } else if (cmd.startsWith("CAL_T ")) {
        int n_turns = cmd.substring(6).toInt();
        if (n_turns <= 0) return "ERR:CAL_T bad turns";
        int32_t tc, pc, wc;
        sensor.readRawEncoders(tc, pc, wc);
        if (abs(tc) < 100) return "ERR:CAL_T too few counts";
        float ppr = (float)abs(tc) / (float)n_turns;
        char buf[64];
        snprintf(buf, sizeof(buf), "CAL:THETA,%ld,%.2f", (long)tc, ppr);
        return String(buf);

    } else if (cmd.startsWith("CAL_P ")) {
        int n_turns = cmd.substring(6).toInt();
        if (n_turns <= 0) return "ERR:CAL_P bad turns";
        int32_t tc, pc, wc;
        sensor.readRawEncoders(tc, pc, wc);
        if (abs(pc) < 100) return "ERR:CAL_P too few counts";
        float ppr = (float)abs(pc) / (float)n_turns;
        char buf[64];
        snprintf(buf, sizeof(buf), "CAL:PHI,%ld,%.2f", (long)pc, ppr);
        return String(buf);

    } else if (cmd.startsWith("SET_PPR_ROTARY ")) {
        float v = 0.0f;
        if (!parseFiniteFloat(cmd.substring(15), v) || v < 100.0f || v > 500000.0f) {
            return "ERR:SET_PPR_ROTARY bad value";
        }
        sensor.setPPRRotary(v);
        char buf[48];
        snprintf(buf, sizeof(buf), "ACK:PPR_ROTARY,%.2f", v);
        return String(buf);

    } else if (cmd.startsWith("SET_PPR_WIRE ")) {
        float v = 0.0f;
        if (!parseFiniteFloat(cmd.substring(13), v) || v < 100.0f || v > 500000.0f) {
            return "ERR:SET_PPR_WIRE bad value";
        }
        sensor.setPPRWire(v);
        char buf[48];
        snprintf(buf, sizeof(buf), "ACK:PPR_WIRE,%.2f", v);
        return String(buf);

    } else if (cmd == "SAVE_PPR") {
        return sensor.savePPRToNVS() ? "ACK:SAVE_PPR" : "ERR:SAVE_PPR_FAILED";

    } else if (cmd == "SAVE_POINT") {
        SystemStatus st = sensor.getStatus();
        char buf[128];
        snprintf(buf, sizeof(buf),
            "POINT,%u,%.2f,%.2f,%.2f,%.2f,%.3f,%.3f",
            pt_idx++,
            st.position.x_mm, st.position.y_mm, st.position.z_mm,
            st.spherical.r_mm, st.spherical.theta_deg, st.spherical.phi_deg);
        return String(buf);

    } else if (cmd == "DEL_POINT") {
        if (pt_idx == 0) {
            return "ERR:NO_POINTS";
        }
        pt_idx--;
        char buf[32];
        snprintf(buf, sizeof(buf), "DEL_POINT,%u", pt_idx);
        return String(buf);

    } else if (cmd == "GET_IP") {
#if ENABLE_WIFI
        String reply;
        if (WiFi.status() == WL_CONNECTED) {
            reply = "STA_IP:" + WiFi.localIP().toString();
        } else {
            reply = "STA_IP:NOT_CONNECTED";
        }
        return reply;
#else
        return "ERR:WIFI_DISABLED";
#endif

    } else if (cmd.startsWith("WIFI_SET:") || cmd.startsWith("WIFI_AYAR:")) {
#if !ENABLE_REMOTE_WIFI_CONFIG
        return "ERR:WIFI_CFG_DISABLED";
#else
        int colonIdx = cmd.indexOf(':');
        String payload = cmd.substring(colonIdx + 1);
        int commaIdx = payload.indexOf(',');
        if (commaIdx == -1) {
            return "ERR:WIFI_INVALID";
        }

        String ssid = payload.substring(0, commaIdx);
        String pass = payload.substring(commaIdx + 1);
        // Allow explicit clear request: WIFI_SET:, (empty SSID + empty password)
        bool clear_request = (ssid.length() == 0 && pass.length() == 0);
        if (!clear_request && (ssid.length() == 0 || ssid.length() > 32)) return "ERR:SSID_INVALID";
        if (pass.length() > 0 && pass.length() < 8) return "ERR:PASS_TOO_SHORT";
        if (pass.length() > 63) return "ERR:PASS_TOO_LONG";
        Preferences prefs;
        if (!prefs.begin("wifi_cfg", false)) return "ERR:WIFI_SAVE_FAILED";
        prefs.putString("ssid", ssid);
        prefs.putString("pass", pass);
        const bool saved = prefs.getString("ssid", "") == ssid &&
                           prefs.getString("pass", "") == pass;
        prefs.end();
        if (!saved) return "ERR:WIFI_SAVE_FAILED";
        // Let the ingress dispatcher deliver one ACK before the reboot timer starts.
        g_restart_pending = true;
        g_restart_at_ms = millis() + 500;
        return "ACK:WIFI_SAVED";
#endif

    } else if (cmd == "SYSINFO") {
#if ENABLE_WIFI
        int32_t rssi = (WiFi.status() == WL_CONNECTED) ? WiFi.RSSI() : 0;
#if ENABLE_CMD_TCP
        uint8_t tcpCount = cmdTcp.clientCount();
#else
        uint8_t tcpCount = 0;
#endif
        char buf[64];
        snprintf(buf, sizeof(buf), "SYSINFO,%ld,%lu,%lu,%u",
                 (long)rssi, (unsigned long)ESP.getFreeHeap(),
                 (unsigned long)(millis() / 1000), tcpCount);
        return String(buf);
#else
        return "ERR:WIFI_DISABLED";
#endif
    }

    return "ERR:UNKNOWN_CMD";
}

static String executeCommand(String cmd) {
    cmd.trim();
    String reply = processCommand(cmd);
    if (reply.length() > 0) Serial.println(reply);
#if ENABLE_BATTERY_MONITOR
    if (cmd == "STATUS") Serial.println(buildBatteryLine());
#endif
    return reply;
}

static void handleSerialCommands() {
    static bool serial_overflow = false;
    while (Serial.available() > 0) {
        const char ch = (char)Serial.read();
        if (ch == '\n' || ch == '\r') {
            if (!serial_overflow) {
                serial_buffer.trim();
                if (serial_buffer.length() > 0) {
                    executeCommand(serial_buffer);
                }
            }
            serial_buffer = "";
            serial_overflow = false;
        } else {
            serial_buffer += ch;
            if (serial_buffer.length() > 128) {
                Serial.println("ERR:CMD_TOO_LONG");
                serial_buffer = "";
                serial_overflow = true;
            }
        }
    }
}

void setup() {
    Serial.begin(115200);
    // Wait for serial to settle
    delay(500);
    
    Serial.println("\n========================================");
    Serial.println("  Spherical 3D Positioning System");
    Serial.print("  Firmware ");
    Serial.println(EVKA_FIRMWARE_VERSION);
#if defined(PCB_V4)
    Serial.println("  Board: EVKA v4 / ESP32-S3");
#else
    Serial.println("  Board: classic ESP32");
#endif
    Serial.println("========================================\n");
    
    // Initialize sensor hardware
    sensor.begin();
    statusLed.begin();

#if ENABLE_WIFI
    dashboard.begin();
    delay(200);  // let AP come fully up before ESP-NOW init
#if ENABLE_CMD_TCP
    cmdTcp.begin();
#endif
#if ENABLE_ESPNOW_REMOTE
    g_espnow_fault = !initEspNow();
#endif
#endif

    // CRITICAL: Set zero point when robot is at home position
    g_boot_calibrating = true;
    Serial.println("Waiting 2s before calibration...");
    waitWithStatusLed(2000);
    Serial.println("Setting zero point... (Ensure robot is at MECHANICAL HOME!)");
    sensor.setZeroPoint();
    g_boot_calibrating = false;
    tickStatusLed();
    Serial.println("Calibration Complete.");
}

void loop() {
    static unsigned long last_update = 0;

    // Non-blocking serial command handler
    handleSerialCommands();

#if ENABLE_WIFI
    // ESP-NOW remote button handler
#if ENABLE_ESPNOW_REMOTE
    if (espnow_pending_button >= 0) {
        int8_t btn = espnow_pending_button;
        espnow_pending_button = -1;
        if (btn < REMOTE_BUTTON_COUNT) {
            // Broadcast button event for web UI, TCP, and serial indicator
            char btn_msg[24];
            snprintf(btn_msg, sizeof(btn_msg), "REMOTE_BTN:%d", btn);
            Serial.println(btn_msg);
            dashboard.broadcast(btn_msg);
#if ENABLE_CMD_TCP
            cmdTcp.sendToAllClients(btn_msg);
#endif

            const char* cmd = REMOTE_BUTTON_CMD[btn];
            if (cmd == nullptr) return;  // unassigned button — ignore silently
            Serial.printf("[ESP-NOW] Button %d -> %s\n", btn, cmd);
            statusLed.flashRemoteButton();
            String reply = executeCommand(String(cmd));
            if (reply.length() > 0) {
                dashboard.broadcast(reply.c_str());
#if ENABLE_CMD_TCP
                cmdTcp.sendToAllClients(reply.c_str());
#endif
            }
        }
    }
    // Heartbeat — rebroadcast to WebSocket, TCP, and serial so GUIs can track link status
    if (espnow_pending_heartbeat) {
        espnow_pending_heartbeat = false;
        Serial.println("REMOTE_HB");
        dashboard.broadcast("REMOTE_HB");
#if ENABLE_CMD_TCP
        cmdTcp.sendToAllClients("REMOTE_HB");
#endif
    }
#endif
    // Non-blocking WiFi maintenance:
    // keep AP available and schedule controlled STA retries after disconnects.
    dashboard.tick();

    // WebSocket command handler
    {
        String wsCmd = dashboard.takePendingCommand();
        if (wsCmd.length() > 0) {
            String reply = executeCommand(wsCmd);
            if (reply.length() > 0) {
                dashboard.broadcast(reply.c_str());
                if (wsCmd == "STATUS") sendBatteryLineToWireless();
#if ENABLE_CMD_TCP
                // POINT/DEL_POINT must reach TCP clients too (keeps all UIs in sync)
                if (reply.startsWith("POINT,") || reply.startsWith("DEL_POINT,"))
                    cmdTcp.sendToAllClients(reply.c_str());
#endif
            }
        }
    }

#if ENABLE_CMD_TCP
    // TCP server: accept connections, read commands
    cmdTcp.poll();
    {
        String tcpCmd = cmdTcp.takePendingCommand();
        if (tcpCmd.length() > 0) {
            String reply = executeCommand(tcpCmd);
            if (reply.length() > 0) {
                cmdTcp.sendToAllClients(reply.c_str());
                if (tcpCmd == "STATUS") sendBatteryLineToWireless();
                // POINT/DEL_POINT must reach WebSocket dashboard too
                if (reply.startsWith("POINT,") || reply.startsWith("DEL_POINT,"))
                    dashboard.broadcast(reply.c_str());
            }
        }
    }
#endif

#endif // ENABLE_WIFI

    if (g_restart_pending && (int32_t)(millis() - g_restart_at_ms) >= 0) {
        ESP.restart();
        return;
    }

    tickStatusLed();

    // Update position at fixed interval
    if (millis() - last_update >= UPDATE_PERIOD_MS) {
        last_update = millis();

        // Calculate new position from current sensor readings
        sensor.updatePosition();
        sensor.printPosition();  // human-readable debug line to serial

        // Format DATA once; send to serial + WiFi (avoids duplicate snprintf)
        {
            SystemStatus st = sensor.getStatus();
            char buf[128];
            snprintf(buf, sizeof(buf),
                     "DATA,%.2f,%.2f,%.2f,%.2f,%.3f,%.3f,%u,%lu,%lu",
                     st.position.x_mm, st.position.y_mm, st.position.z_mm,
                     st.spherical.r_mm, st.spherical.theta_deg, st.spherical.phi_deg,
                     st.is_valid, (unsigned long)st.frame_count,
                     (unsigned long)st.last_update_ms);
            Serial.println(buf);

#if ENABLE_WIFI
            dashboard.broadcast(buf);
#endif

#if ENABLE_WIFI && ENABLE_CMD_TCP
            cmdTcp.broadcastPosition(
                st.position.x_mm, st.position.y_mm, st.position.z_mm);
            cmdTcp.broadcastSensorData(
                st.spherical.r_mm, st.spherical.theta_deg,
                st.spherical.phi_deg, st.is_valid, st.frame_count);
#endif
        }
    }
}

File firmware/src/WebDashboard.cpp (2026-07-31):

// WebDashboard.cpp — WiFi AP/STA management, the browser dashboard (served HTML),
// and the WebSocket data/command channel. Network callbacks only enqueue commands;
// the main loop drains them (never call firmware logic from a WiFi callback — that
// caused crashes, see docs/ASYNCTCP_STACK_OVERFLOW_ANALYSIS.md).
#include "WebDashboard.h"

#if ENABLE_WIFI

#include <Preferences.h>
#include <string.h>

// ============================================================================
// Embedded HTML dashboard (PROGMEM)
// ============================================================================

static const char INDEX_HTML[] PROGMEM = R"rawliteral(
<!DOCTYPE html>
<html lang="en">
<head>
<meta charset="UTF-8">
<meta name="viewport" content="width=device-width,initial-scale=1">
<title>EvkaPosition</title>
<style>
/* Design tokens — canonical spec: docs/gui_unification/DESIGN_TOKENS.md
   (the desktop GUI carries the same values in tools/evka_gui/tokens.py).
   New UI uses these vars; the older hard-coded hexes are retrofitted in Phase 3. */
:root{
 --ok:#00ff88; --danger:#ff4444; --warn:#ffd700; --accent:#00ffff; --info:#4488ff;
 --ipt:#00ff88; --ipt-target:#ff8c00; --muted:#8899aa; --text:#eef;
 --bg-deep:#0a0a1a; --bg-canvas:#0f0f23; --bg-panel:#1a1a2e; --border:#2a3550;
}
*{margin:0;padding:0;box-sizing:border-box}
body{background:#1a1a2e;color:#e0e0e0;font-family:monospace;overflow:hidden;touch-action:none}
/* --- Recording --- */
#btn-rec.active{border-color:var(--danger);color:var(--danger);
 animation:recpulse 1.2s ease-in-out infinite}
@keyframes recpulse{0%,100%{opacity:1}50%{opacity:.45}}
/* --- Protocol log --- */
.log-filters{display:flex;flex-wrap:wrap;gap:8px;margin:6px 0;font-size:10px;color:var(--muted)}
.log-filters label{display:flex;align-items:center;gap:3px;min-height:28px}
#log-out{max-height:150px;overflow-y:auto;font-size:10px;line-height:1.5;
 background:var(--bg-deep);border:1px solid var(--border);border-radius:4px;
 padding:5px;margin-top:4px;white-space:pre-wrap;word-break:break-all}
#log-out .l-data{color:var(--muted)}
#log-out .l-ack{color:var(--ok)}
#log-out .l-err{color:var(--danger)}
#log-out .l-other{color:var(--accent)}
/* --- Quick IPT --- */
#ipt-panel{display:none;max-width:520px;margin:0 auto}
#btn-ipt.active{border-color:var(--ipt);color:var(--ipt)}
/* 16px keeps iOS Safari from zooming the page when the field takes focus */
#ipt-panel input[type=number]{width:100%;min-height:44px;padding:10px;font-size:16px;
 font-family:monospace;background:var(--bg-deep);border:1px solid #446;color:var(--text);border-radius:4px}
#ipt-panel .vcard-value{font-size:14px;word-break:break-all}
.ipt-help{font-size:10px;color:var(--muted);line-height:1.5;margin:4px 0 10px}
.ipt-hint{font-size:12px;font-weight:bold;margin:8px 0;min-height:32px;line-height:1.4;color:var(--muted)}
.ipt-hint.ok{color:var(--ok)}.ipt-hint.warn{color:var(--warn)}.ipt-hint.reject{color:var(--danger)}
.val.ok{color:var(--ok)}.val.warn{color:var(--warn)}.val.reject{color:var(--danger)}
/* 50/50 like the desktop GUI: views on the left (3D over the XY/XZ/YZ strip),
   controls on the right in two sub-columns — wide enough that nothing scrolls
   on a normal screen. */
#app{display:grid;height:100vh;grid-template-rows:32px minmax(0,1fr) 150px;grid-template-columns:1fr 1fr}
#hdr{grid-column:1/-1;grid-row:1;display:flex;align-items:center;height:32px;padding:0 10px;
     background:#0d1226;border-bottom:1px solid #2a3550;font-size:12px;gap:10px}
#hdr-title{color:#00ffff;font-size:13px;font-weight:bold;letter-spacing:2px;flex:1}
#conn-led{width:9px;height:9px;border-radius:50%;background:#ff3333;box-shadow:0 0 6px #ff3333;
          flex-shrink:0;transition:background .3s,box-shadow .3s}
#conn-led.ok  {background:#00ff88;box-shadow:0 0 6px #00ff88}
#conn-led.warn{background:#ffd700;box-shadow:0 0 6px #ffd700}
#hdr-ts{color:#556677;font-size:11px}
#hdr button{min-height:24px;padding:2px 8px;font-size:11px;border:1px solid #446;color:#8899aa;
            background:transparent;border-radius:3px;touch-action:manipulation;cursor:pointer}
#hdr button.active{border-color:#00ffff;color:#00ffff}
#btn-freeze.active{border-color:#ff8c00;color:#ff8c00}
#cv{grid-column:1;grid-row:2;background:#0f0f23;touch-action:none;display:block;width:100%;height:100%}
#views2d{grid-column:1;grid-row:3;display:flex;flex-direction:row;gap:2px;background:#0a0a1a}
.v2d-section{flex:1;min-height:0;min-width:0;display:flex;flex-direction:column}
.v2d-title{font-size:10px;color:#8899aa;text-align:center;padding:2px 0;flex-shrink:0}
#views2d canvas{flex:1;width:100%;min-height:0;display:block;background:#0f0f23}
#panel{grid-column:2;grid-row:2/4;padding:10px;overflow-y:auto;background:#16213e}
#panel-main{display:flex;gap:14px;align-items:flex-start}
.panel-col{flex:1;min-width:0}
.sep{border-top:1px solid #2a3550;margin:6px 0}
.section-lbl{font-size:10px;color:#8899aa;letter-spacing:1px;margin:4px 0 3px;font-weight:bold}
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

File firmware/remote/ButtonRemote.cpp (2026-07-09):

// ============================================================================
// EvkaPosition — Wireless Button Remote (ESP-NOW Sender)
// ============================================================================
// Target: ESP32-C3 (Seeed XIAO ESP32-C3 or ESP32-C3 SuperMini)
// Always-awake mode: ESP-NOW initialised once at startup.
// Sends a single byte (button index 0–4) on each confirmed press edge.
//
// Button wiring: Each button connects GPIO → GND (internal pull-up enabled).
// ============================================================================

#include <Arduino.h>
#include <esp_now.h>
#include <esp_wifi.h>
#include <WiFi.h>

// ============================================================================
// CONFIGURATION
// ============================================================================

#define FIRMWARE_VERSION "ButtonRemote v1.1"

// Number of buttons and GPIO assignments.
// Safe GPIOs on ESP32-C3: avoids strapping pins (2, 9), serial (6, 7), LED (8).
#define BTN_COUNT     5

// LED feedback pin — GPIO 8 = built-in blue LED on ESP32-C3 SuperMini
#define PIN_LED       8

// WiFi channel — fallback if AP scan fails
#define ESPNOW_CHANNEL   1
// Main ESP32 AP SSID — scanned at startup to find the actual WiFi channel
#define MAIN_AP_SSID    "CMDCNC_EVKA"
#define SCAN_RETRIES     3
// Lower TX power reduces WiFi current peaks on weak Type-C/extension supplies.
#define REMOTE_WIFI_TX_POWER WIFI_POWER_8_5dBm

// Heartbeat
#define HEARTBEAT_INTERVAL_MS  10000
#define HEARTBEAT_BYTE         0xFE

// Debounce
#define DEBOUNCE_MS   50
// Ignore buttons for the first 500 ms: GPIO 0 may read LOW while the
// USB-JTAG bridge is still settling after reset.
#define BOOT_GUARD_MS 500

// ============================================================================
// INTERNALS
// ============================================================================

// BTN0=GPIO4 (Green/SAVE_POINT), BTN1=GPIO5 (Red/DEL_POINT),
// BTN2=GPIO0, BTN3=GPIO1, BTN4=GPIO3
static const uint8_t BTN_PINS[BTN_COUNT] = {4, 5, 0, 1, 3};

struct ButtonState {
    bool     last_raw;        // last raw digitalRead() result (true = pressed = LOW)
    bool     confirmed;       // debounce-settled state
    uint32_t last_change_ms;  // millis() of last raw edge
};
static ButtonState g_buttons[BTN_COUNT];

static uint8_t broadcast_addr[] = { 0xFF, 0xFF, 0xFF, 0xFF, 0xFF, 0xFF };

static volatile bool send_done = false;
static volatile bool send_ok   = false;

static void onSendDone(const uint8_t* mac, esp_now_send_status_t status) {
    send_ok   = (status == ESP_NOW_SEND_SUCCESS);
    send_done = true;
}

static void ledOn()  { digitalWrite(PIN_LED, HIGH); }
static void ledOff() { digitalWrite(PIN_LED, LOW);  }

static void initButtons() {
    for (uint8_t i = 0; i < BTN_COUNT; i++) {
        pinMode(BTN_PINS[i], INPUT_PULLUP);
        g_buttons[i] = {false, false, 0};
    }
}

// ============================================================================
// SETUP — runs once at power-on
// ============================================================================

void setup() {
    Serial.begin(115200);
    delay(500);

    Serial.println(FIRMWARE_VERSION);
    Serial.println("[ButtonRemote] ESP-NOW wireless pendant (always-awake)");

    initButtons();
    pinMode(PIN_LED, OUTPUT);
    ledOff();

    // Initialise WiFi in STA mode, prevent any auto-scan/reconnect,
    // then pin to the ESP-NOW channel before initialising the stack.
    WiFi.mode(WIFI_STA);
    if (!WiFi.setTxPower(REMOTE_WIFI_TX_POWER)) {
        Serial.println("[ButtonRemote] WARN: setTxPower failed");
    } else {
        Serial.println("[ButtonRemote] TX power set to WIFI_POWER_8_5dBm");
    }
    WiFi.setAutoReconnect(false);
    WiFi.disconnect(false, true);   // disconnect + erase stored AP credentials
    delay(100);                     // let WiFi stack settle before channel change

    // Scan for the main ESP32's AP to discover its current WiFi channel.
    // When the main board's STA connects to a home router on channel != 1,
    // its AP silently moves to that channel — hardcoding ch1 would break ESP-NOW.
    uint8_t active_channel = ESPNOW_CHANNEL;  // fallback
    bool found_ap = false;
    for (int attempt = 0; attempt < SCAN_RETRIES; attempt++) {
        if (attempt > 0) delay(1000);
        Serial.printf("[ButtonRemote] Scanning for '%s'... (attempt %d/%d)\n",
                      MAIN_AP_SSID, attempt + 1, SCAN_RETRIES);
        int n = WiFi.scanNetworks(false, false, false, 200);
        for (int i = 0; i < n; i++) {
            if (WiFi.SSID(i) == MAIN_AP_SSID) {
                active_channel = (uint8_t)WiFi.channel(i);
                found_ap = true;
                Serial.printf("[ButtonRemote] Found on ch%u (RSSI %d dBm)\n",
                              active_channel, WiFi.RSSI(i));
                break;
            }
        }
        WiFi.scanDelete();
        if (found_ap) break;
    }
    if (!found_ap) {
        Serial.printf("[ButtonRemote] AP not found — using fallback ch%u\n", active_channel);
    }

    esp_err_t ch_err = esp_wifi_set_channel(active_channel, WIFI_SECOND_CHAN_NONE);
    Serial.printf("[ButtonRemote] Channel set ch%u -> %s\n",
                  active_channel, ch_err == ESP_OK ? "OK" : "FAIL");

    // Initialise ESP-NOW once — stays active for the lifetime of the device
    if (esp_now_init() != ESP_OK) {
        Serial.println("[ButtonRemote] ESP-NOW init FAILED");
        return;
    }
    esp_now_register_send_cb(onSendDone);

    esp_now_peer_info_t peer = {};
    memcpy(peer.peer_addr, broadcast_addr, 6);
    peer.channel = active_channel;
    peer.encrypt = false;
    esp_now_add_peer(&peer);

    Serial.println("[ButtonRemote] ESP-NOW ready");
    Serial.println("[ButtonRemote] Waiting for button press...");
    Serial.println("  BTN0 GPIO4 -> SAVE_POINT (Green - Add Point)");
    Serial.println("  BTN1 GPIO5 -> DEL_POINT  (Red   - Delete Last Point)");
    Serial.println("  BTN2 GPIO0 -> (unassigned)");
    Serial.println("  BTN3 GPIO1 -> (unassigned)");
    Serial.println("  BTN4 GPIO3 -> (unassigned)");
}

// ============================================================================
// LOOP — runs continuously
// ============================================================================
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

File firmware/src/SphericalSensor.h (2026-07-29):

// SphericalSensor.h — configuration + the SphericalPositioningSensor class.
// ALL pins, PPR values, and feature flags live here: this is the single source of
// truth for hardware configuration. Reference: docs/ARCHITECTURE.md.
// Source tour: docs/firmware/CODE_WALKTHROUGH.md.
#ifndef SPHERICAL_SENSOR_H
#define SPHERICAL_SENSOR_H

#include <Arduino.h>
#include <ESP32Encoder.h>
#include <math.h>
#include <stdint.h>

// ============================================================================
// CONFIGURATION SECTION
// ============================================================================

#define EVKA_FIRMWARE_VERSION "0.2.0-prototype"

// Pin Definitions — board selected at build time (-DPCB_V4 for the ESP32-S3 v4 PCB)
#if defined(PCB_V4)
// EVKA_position_v4 — ESP32-S3-DevKitC-1. Encoders via on-board 10k/20k dividers
// straight to GPIO (no Schmitt buffer). Verified against the v4 schematic AND PCB
// pad-nets (WIRE=DIVIDER_NODE_1/2 on J1, PHI=_3/4 on J2, THETA=_5/6 on J3).
// GPIO17/18 are NOT wired.
#define PIN_THETA_A   9     // DIVIDER_NODE_5 (J3.1 theta A)
#define PIN_THETA_B   10    // DIVIDER_NODE_6 (J3.3 theta B)
#define PIN_PHI_A     4     // DIVIDER_NODE_3 (J2.2 phi A)
#define PIN_PHI_B     5     // DIVIDER_NODE_4 (J2.4 phi B)
#define PIN_WIRE_A    7     // DIVIDER_NODE_1 (J1.1 wire A)
#define PIN_WIRE_B    8     // DIVIDER_NODE_2 (J1.3 wire B)
#else
// Classic ESP32 (Wemos D1 R32). Must stay interrupt/PCNT-capable.
#define PIN_THETA_A   14    // Encoder pin (Theta azimuth axis)
#define PIN_THETA_B   12    // Strapping pin — add pull-down
#define PIN_PHI_A     32    // GPIO 32 — ADC1_CH4
#define PIN_PHI_B     35    // GPIO 35 — input-only
#define PIN_WIRE_A    16    // Draw-wire encoder quadrature A
#define PIN_WIRE_B    17    // Draw-wire encoder quadrature B
#endif

// Optional features
#define ENABLE_BATTERY_MONITOR 1  // 1: read 1S LiPo (v4) / battery divider on PIN_BATTERY_ADC
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

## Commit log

2026-02-21 Initial commit: firmware, hardware docs, Python tools
    Organized workspace for ESP32 spherical 3D positioning system:
    - Added .gitignore, platformio.ini, pyproject.toml
    - Rewrote CLAUDE.md to match actual code (ESP32, correct pins/specs)
    - Updated README.md for ESP32 target, removed stale references
    - Replaced GEMINI.md with minimal redirect
    - Trimmed Rotary_Encoder_E40S6/README.md (868 -> ~120 lines)
    - Moved research/RESOURCES.md to docs/resources.md, deleted research/
    - Trimmed firmware/README.md and hardware/README.md
    - Added Phase 3 pin remap TODOs in SphericalSensor.h
    - Added E40S6 voltage divider warning to DWE3000_hardware_notes.md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
    [EvkaPosition.ino, SphericalSensor.cpp, SphericalSensor.h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]
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2026-02-26 Phase 4: PPR correction, .ino->.cpp migration, repo cleanup
    - Update PPR_ROTARY from datasheet 5000 to measured 1480
    - Migrate all firmware from .ino to .cpp for PlatformIO
    - Restructure tests from firmware/tests/ to firmware/
    - Add SingleRotaryTest for individual encoder testing
    - Remove GEMINI.md (redundant), move test plan to docs/
    - Fix stale paths and references across all documentation
    - Update accuracy analysis for measured resolution (~0.243 deg)
    - Create AGENTS.md for multi-agent collaboration
    - Create docs/PROJECT_ROADMAP.md with phases 5-8 plan
    - Fix relative links in moved individual_hardware_test_plan.md
    [DrawWireTest.cpp, EvkaPosition.cpp, RotaryEncoderTest.cpp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]
2026-03-11 firmware: draw-wire sign fix and AllSensorsTest pinout aligned with single tests
    - DrawWireTest: negate encoder count so wire extension reports positive distance
    - AllSensorsTest: pinout Theta 32/35, Phi 14/12, Wire 16/17 to match RotaryEncoderTest and DrawWireTest
    - AllSensorsTest: apply same wire sign convention (negate count) for consistent r readout
    Made-with: Cursor
    [AllSensorsTest.cpp, DrawWireTest.cpp, EvkaPosition.cpp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]
2026-03-11 Before calibration
    [draw_wire_calibration_log_template.csv, rotary_calibration_log_template.csv]
2026-04-05 Enhance documentation and firmware for WiFi status LED and command validation
    - Added WiFi status LED behavior details to README, including wiring instructions and operational states.
    - Updated CMD software to validate WiFi credentials, returning specific error messages for invalid SSID and password.
    - Improved integration documentation with WiFi credential validation rules and error handling.
    - Adjusted firmware to ensure consistent command responses and error reporting for unknown commands.
    - Reflected changes in the visualizer protocol and updated related Python tools for consistency.
    [CalibrationTest.cpp, EvkaPosition.cpp, SphericalSensor.cpp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]
2026-04-08 08.04.2026 -- CMD Update
    Add hardware documentation for evka_position project
    - Introduced comprehensive Bill of Materials (BOM) detailing components for the double-sided pertinax PCB.
    - Added circuit schematic for the evka_position hardware board, outlining connections and component placements.
    - Provided a PCB layout guide to assist in the design and assembly of the hardware.
    - Included individual hardware test plan for systematic testing of the draw-wire and rotary encoders.
    - Documented integration of CMD protocol for compatibility with third-party GUI, including command handling and system diagnostics.
    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
    [encoders_signal_12v.kicad_sch, evka_position_12v.kicad_sch, power_input_12v.kicad_sch]
2026-04-10 10 Nisan CMD Ofis Update documentation and configuration for ESP32-C3 integration
    - Added new environment configuration for button remote testing in `platformio.ini`.
    - Updated `.gitignore` to include additional documentation and legacy files.
    - Enhanced `README.md` and `README_TR.md` with details on the wireless button remote functionality, including GPIO mappings and command actions.
    - Revised calibration documentation to reflect updated GPIO assignments for theta and phi encoders.
    - Removed outdated audit documentation and streamlined references to current performance logs.
    These changes improve the clarity and usability of the project documentation and ensure accurate configuration for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
2026-04-13 Update documentation and firmware for OPKON DWEM2 integration
    - Replaced references to the outdated DWE3000 draw-wire encoder with the new OPKON DWEM2 across various documentation files, including README.md, calibration guides, and hardware design documents.
    - Updated firmware constants and calculations to reflect the DWEM2 specifications, including PPR and mm/count values.
    - Enhanced test guides and integration documentation to ensure accurate setup and calibration instructions for the DWEM2 encoder.
    - Adjusted button remote functionality in the firmware and GUI to accommodate new commands for saving and deleting points.
    These changes improve clarity and ensure compatibility with the lates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
    [AllSensorsTest.cpp, ButtonRemote.cpp, ButtonRemoteTest.cpp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]
2026-04-24 Add V2 hardware design documentation with full sourcing audit and corrections
    - Replace CN3767 (lead-acid charger) with BQ24650 3S synchronous buck charger throughout
    - Fix MAX813L DIP-8 pin diagram: was VCC=pin1/GND=pin2, corrected to GND=pin1/VCC=pin8
    - Replace MP2315 (not stocked Turkey) with MP1584EN (direnc.net 26.46 TL) everywhere
    - Fix PIN_ESP_EN=0 definition: EN pin is not addressable as GPIO, replaced with comment
    - Fix MAX485EPA+ VCC: must use 5V_RAIL (min 4.75V), not 3.3V
    - Fix I2C SCL direction: Output -> Bidir open-drain
    - Fix SS36 topology: D_OR is upstream of 5V_RAIL not downstream in distribution
    - Fix C_BULK 10uF -> 220uF/16V in star topology, fix P6KE18A standoff descriptio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
2026-04-26 V2 power subsystem redesign: remove BQ24650, add Q_BATT active load-sharing
    Three critical architecture flaws fixed across all V2 hardware docs:
    1. Replace Schottky OR-ing (D_EXT/D_BAT) with active IRF4905 MOSFET load-sharing
    (Q_BATT) — adapter now has unconditional priority over 12.6V charged battery.
    Gate circuit: SS14 Schottky (D_GATE) + 100kΩ pull-down (R_G2) + 1N4742A Zener (Z1).
    2. Remove BQ24650 onboard charging entirely — simultaneous charge+load topology
    prevents CC/CV termination, no cell balancing, Turkey sourcing impractical.
    Charging moved to external balance charger via XT60 + JST-XH-4P (J_BAL).
    3. Add F_BAT 5A ATO blade fuse on battery branch — 3S LiPo ca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
2026-04-27 V3 hardware review: fix ADC tap inconsistency, strengthen BMS note, add 12v_tht nav link
    F1 (must-fix): circuit_schematic_v3.md block diagram tapped V12_PROT for GPIO1 ADC
    while section 6 stated BUCK_VIN as the correct default. When adapter is removed,
    V12_PROT collapses to 0V — firmware would see spurious low-battery with V12_PROT tap.
    Moved ADC divider tap to BUCK_VIN in block diagram; removed "or V12_PROT" hedge in
    pin_assignment_v3.md.
    F2 (safety): BMS_3S was qty 0-1 "Recommended if pack remains internal". An internal
    unprotected RC LiPo with no BMS and firmware-only soft-cutoff is a fire risk.
    Changed to qty 1 with "Required unless pack has built-in cell protection" note.
    F3 (naviga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
2026-04-29 Add 5V PCB v2 design docs for LPKF S63 production
    New directory docs/hardware_design/5v_v2/ with full hardware design for
    the improved 5V board targeting FR4 + LPKF S63 mechanical milling.
    Key improvements over the original pertinax 5v/ design:
    - LTC4412 + AO3401 ideal diode replaces Schottky OR on external path
    (20mV drop vs 350mV; 5V_RAIL stays at 4.98V instead of 4.65V)
    - Dual 5V input: USB-C THT + barrel jack with Schottky OR
    - AO3401 SOT-23 for reverse polarity protection (replaces SI2301;
    same package, 4A rated vs 3A)
    - 74HC14N DIP-14 Schmitt trigger buffers all 6 encoder signal lines
    - Filter caps 1nF → 10nF (RC corner 23.9kHz → 2.38kHz)
    - MT3608 trim pot removed; fixed 100k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
2026-04-29 Add hardware design comparison document and presentation
    Create two new deliverables at docs/hardware_design/comparison/:
    - HARDWARE_COMPARISON.md (466 lines): detailed bilingual reference document
    - Section 1: Design evolution timeline (Mermaid)
    - Section 2: 5V→12V migration analysis with TP5100 critical error explanation, 2S LiPo option analysis
    - Section 3: Master comparison table (8 variants)
    - Section 4: Per-variant topology diagrams, specs, strengths, weaknesses
    - Section 5: Cross-design analysis (source selection, charging safety, buildability+cost in ₺, firmware readiness)
    - Section 6: Decision flowchart
    - Section 7: Recommendation (Final Design + V3-D optional onbo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
2026-04-30 5V PCB v2 review pass: USB-C Rd, input ESD, pi filter, GPIO12 fix
    Pre-fab review found two functional bugs and several margin issues. Fixed:
    - Add USB-C CC1/CC2 5.1kΩ Rd pulldowns (R_CC1, R_CC2). Without these,
    compliant USB-C sources do not apply VBUS — board would not charge
    from any real USB-C adapter.
    - Move R_GPIO12 (boot strapping pull-down) from divider-input side to
    the 74HC14N output side. The original placement was logically a
    no-op because the inverter sits between divider and GPIO12.
    - Add SMAJ5.0A input TVS at J_USB VBUS and J4 VIN+, placed before the
    OR-ing Schottky diodes (shunts connector-side ESD to GND before it
    reaches Q_RPP gate or TP4056 input).
    - Add pi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
2026-06-22 Add 5V v2 PCB design workspace; tidy backups, gitignore KiCad cruft
    - Consolidate 10 .pretty footprint libs into libs/
    - Delete archive/ (superseded versions, nested .history/.git)
    - Thin auto-backup ZIPs to newest 5 per folder
    - Add KiCad ignore rules (backups, locks, autosave, .kicad_prl)
    - Add EVKA_position_v2/README.md folder map
    [01_input_schottky_or.kicad_pcb, 01_input_schottky_or.kicad_sch, 02_pi_filter_5v_rail.kicad_pcb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]
2026-07-08 firmware: port to v4 PCB (ESP32-S3-DevKitC-1)
    - New PlatformIO env esp32s3_v4 (-DPCB_V4); pin map selected at build time
    - v4 pins THETA 7/8, PHI 4/5, WIRE 9/10, battery ADC GPIO1 (verified vs schematic + PCB)
    - Switch both boards to madhephaestus/ESP32Encoder (hardware PCNT)
    - Enable battery monitor (1S LiPo)
    - Update README pin map/build, roadmap, setup guide
2026-07-08 docs: archive legacy 12V/v2/v3 hardware docs into 12v_legacy/
    [encoders_signal_12v.kicad_sch, evka_position_12v.kicad_sch, power_input_12v.kicad_sch]
2026-07-08 pcb: add v3/v4/v5 KiCad workspaces + hand-built v2 master; drop superseded EVKA_position_v2 project
    v4 = fabricated current board (+ FIRMWARE.md quickstart). v2/v3/v5 kept for reference.
    [01_input_schottky_or.kicad_pcb, 01_input_schottky_or.kicad_sch, 02_pi_filter_5v_rail.kicad_pcb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]
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2026-07-09 fix: anchor calibration/ gitignore to root so docs/calibration/ isn't ignored
2026-07-09 chore: restore calibration tool + guide the broken gitignore rule had hidden
    tools/calibration/ (calibrate.py Kabsch solver) and docs/calibration/calibration_guide.md
    were silently excluded by the too-broad 'calibration/' pattern; now anchored + tracked.
2026-07-09 docs: stop gitignore hiding two referenced ESP32 troubleshooting docs; fix live links
    - Un-ignore docs/ESP32_WDT_20HZ_QUICK_REFERENCE.md + ESP32_WIFI_AP_STA_HEAP_DRAIN_GUIDE.md
    (referenced by docs index; the docs/ESP32_*.md legacy pattern caught them by accident)
    - Repoint firmware/README -> docs/ARCHITECTURE.md (CLAUDE.md is git-ignored)
    - Fix 5v/README -> 12v_legacy/12v (12v was archived)
2026-07-09 fix: scope report/ gitignore to LaTeX artifacts; track hidden report deliverables
    The bare report/ rule silently ignored laser_radius/report/ (linked as a
    finished deliverable from laser_radius/README.md) and report/main.tex.
    Third recurrence of the unanchored-gitignore bug class (cf. a32f09d,
    9c06124). Sources + PDFs now tracked; only .aux/.log/.out/.toc etc. stay
    ignored.
2026-07-09 feat: unified evka_gui package; evka_gui_v2 + position_checker entry points become shims
    Canonical GUI = tools/evka_gui (gui/model/transport/calibration + tests).
    tools/evka_gui_v2 and position_checker {main,cmd_main} re-export with
    deprecation warnings. Plan + log in docs/gui_unification/, design spec in
    docs/superpowers/specs/. README/HANDOFF/tools docs updated to match.
2026-07-09 feat: StatusLed RGB module + BLINK command + esp32s3_v4_rgb38 env
    StatusLed drives the DevKitC WS2812 (GPIO48 v1.0 / GPIO38 v1.1 via
    RGB_LED_GPIO) with boot/WiFi/validity states; BLINK flashes white ~0.7 s
    as a connection test (classic ESP32 pulses GPIO2 instead). New env
    esp32s3_v4_rgb38 extends esp32s3_v4 with -DRGB_LED_GPIO=38.
    v4 FIRMWARE.md documents LED behavior + troubleshooting.
2026-07-09 docs: remote pendant remap (SAVE/DEL_POINT), laser-radius study, integration updates
    Pendant buttons: green=SAVE_POINT, red=DEL_POINT (was ZERO/SAVE_POINT);
    ButtonRemote.cpp + TR guide + remote hardware docs updated to match.
    laser_radius gains Bosch PLR 40C integration study + firmware notes.
    CMD integration doc: BLINK, DEL_POINT, evka_gui entry points.
2026-07-09 chore: handoff polish — CI builds esp32s3_v4 + C# app; CONTRIBUTING learns evka_gui; pcb_design README
    CI now builds the canonical fabricated board env and the CMD C# app
    (EnableWindowsTargeting already in csproj). CONTRIBUTING routes new
    contributors to tools.evka_gui and plain 'pytest -q'. New
    pcb_design/README.md explains v2-v5 workspace status (v4 = current).
    ARCHITECTURE command table gains BLINK.
2026-07-13 fix: remap v4 theta and wire ports
    [EVKA_position_v4.csv, EVKA_position_v4.kicad_pcb, EVKA_position_v4.kicad_sch]
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2026-07-29 docs: add calibration report workflow and session templates
    Document the endpoint calibration report CLI, session CSV layout, and
    repeatability notes with starter templates under docs/calibration/.
    [calibration_points.csv, validation_points.csv]
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2026-07-29 fix: repair local validation workflow and record open CI segfault
    The dashboard harness and the GUI package both depended on environment
    details that only GitHub Actions happens to provide, so `npm test` and
    `pytest` failed on an ordinary Linux checkout while CI stayed green.
    - webdash_harness: run `python3`, not `python`. Debian/Ubuntu ship no
    `python` alias, so the documented `npm test` died with rc=127; CI hid
    this because actions/setup-python injects the alias.
    - evka_gui: guard the PyQt5.QtWebSockets import. Distro PyQt5 packages
    QtWebSockets separately, and the unconditional import made the entire
    package unimportable — collection aborted before any test ran. WsClient()
    no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
    [ws_client.py]
2026-07-31 feat(packaging): ship evka_gui as a Windows desktop app
    Freeze tools/evka_gui into a double-clickable EvkaGUI.exe via PyInstaller
    (onedir, --windowed) so lab users need no Python install. Same source as the
    Linux GUI - no separate port, no features dropped.
    Fix four bugs that only manifest once frozen:
    - calibration PROJECT_ROOT derived from __file__ pointed inside the read-only
    bundle, so sessions and calibration.json had nowhere valid to go. Now
    redirects to the per-user data dir (LOCALAPPDATA / XDG_DATA_HOME /
    ~/.local/share) when sys.frozen. Deliberately not bare ~/evka_position:
    that collides with the repo on a dev box checked out under $HOME.
    - tools/remote_tester/ had no __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
    [gui.py, ipt_panel.py, session_utils.py]
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2026-07-31 feat(gui): export wire/theta/phi with saved points and snapshots
    Saved-point and snapshot CSVs recorded position only. x/y/z are derived
    from the spherical triple and additionally EMA-filtered in firmware, so an
    exported point could not be traced back to what the encoders actually read
    — there was no way to tell a slipped wire encoder from a bad transform.
    Append wire_mm,theta_deg,phi_deg to both exports, in the desktop GUI and
    the web dashboard. Appended rather than inserted so readers that index by
    column number keep working. A missing reading is a blank cell, never 0.0,
    so "no data" stays distinguishable from a real zero.
    The values are latched from the live stream before any software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
    [WebDashboard.cpp, gui.py, session_utils.py]
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2026-08-12 fix(tests): replace deadlocking forked markers with a two-invocation split
    The committed `pytestmark = pytest.mark.forked` approach on the six pyqtgraph
    modules does not work -- it deadlocks the suite deterministically on Python 3.10.
    `tools/calibration/tests/test_gui.py` sorts first and builds a QApplication in
    the parent, so pytest-forked's os.fork() inherits locks held by threads that do
    not exist in the child and blocks forever. It went unnoticed because the recorded
    green run predates pytest-forked being installed: pytest silently ignores an
    unknown marker, so the markers were inert.
    Replaced with the two-invocation split REMAINING_WORK.md had predicted as the
    fallback. The modules now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
2026-08-12 docs: repair 26 broken relative links in the archived hardware trees
    Every link under docs/hardware_design/12v_legacy/ that pointed at ../5v/ was
    off by one directory level: those docs were moved down into 12v_legacy/ and
    their cross-references to the still-present docs/hardware_design/5v/ tree were
    never re-based. The v2 layout guide had the mirror-image problem, reaching up
    with ../ for files sitting in its own directory.
    All 382 relative links across project markdown now resolve. The single
    remaining 'broken link' is a false positive: a C++ lambda capture,
    [this](WiFiEvent_t event, ...), inside a fenced code block.
    Found by sweeping every markdown file rather than the ten core handoff d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
